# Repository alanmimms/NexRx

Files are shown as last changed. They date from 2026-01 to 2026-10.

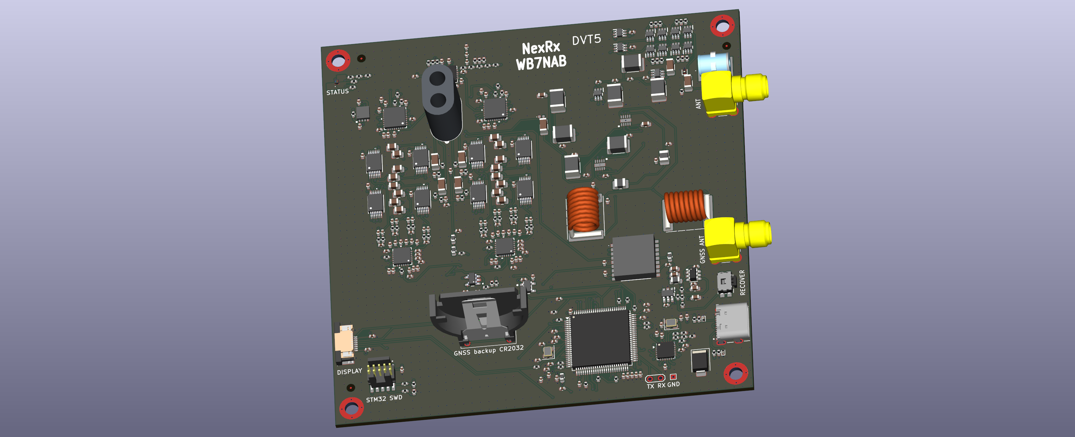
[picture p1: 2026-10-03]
doc/NexRxDVT5.png

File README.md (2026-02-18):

# NexRx: Open-Source Ham Radio SDR Receiver System
## Overview & Core Concepts

### What is NexRx?

NexRx is an ambitious open-source project that reimagines how we
interact with ham radio receivers. Instead of the knobs, buttons,
and menu diving that have defined radio interfaces for decades, NexRx
presents a browser-based interface built around a revolutionary
concept called "setboxes."

Think of it as bringing ham radio into the modern computing age -
where your radio's interface is as flexible and powerful as the
software on your computer, but still maintains the real-time
performance demands of RF communication.

This is an overview of the project. There is much more in the `./doc`
directory.

The entire project uses the MIT License, covering everything from
hardware designs and PCB layouts to software source code. This isn't
just another commercial radio with a fancy display - it's a
community-driven platform designed to push ham radio technology
forward for everyone.

### The Big Idea: Setboxes

Here's where NexRx gets interesting. Traditional radios force you to
think in terms of physical controls - turn this knob for frequency,
press that button for mode, flip this switch for antenna selection.
But why should software-defined radio be limited by the metaphors of
analog hardware?

NexRx introduces "setboxes" - think of them as smart presets that can
inherit settings from each other, just like object-oriented
programming. Instead of having separate "band" and "mode" controls,
you might have a setbox called "40m-CW-Contest" that inherits basic
40-meter settings from a parent "40m" setbox, adds CW-specific
parameters from a "CW" setbox, and then layers on contest-specific
configurations.

```mermaid
graph TD
    A[Global Settings] --> B[40m Band]
    A --> C[CW Mode]
    A --> D[Contest Setup]
    B --> E[40m-CW-Contest]
    C --> E
    D --> E
    
    style A fill:#e1f5fe
    style E fill:#c8e6c9
```

This hierarchy means you can set your antenna preferences once in
"Global Settings," define band-specific power levels in "40m Band,"
configure CW tone preferences in "CW Mode," and create
contest-specific memory channels in "Contest Setup." When you activate
"40m-CW-Contest," it automatically combines all these inherited
settings with any overrides you've defined specifically for that
configuration.

### Why This Matters

Traditional radio interfaces suffer from what we might call "control
soup" - every setting lives at the same level, making it hard to
organize your preferences logically. Want to use different antennas
for 160m versus other bands? You'll be manually switching antennas
every time you change bands. Prefer different power levels for CW
versus SSB? Hope you remember to adjust that knob every time you
change modes.

Setboxes solve this by letting you organize your radio's behavior
hierarchically. Set up your preferences once, then let the inheritance
system handle the details. The result is a radio that adapts to your
operating style instead of forcing you to adapt to its limitations.

### System Overview

NexRx consists of three main components that work together
seamlessly:

**Hardware Platform**: Built around an STM32H753 microcontroller
running at 480MHz with a full megabyte each of flash and RAM. This
isn't your typical Arduino project - we're talking serious
computational power running Zephyr RTOS. The RF hardware handles general
HF coverage from 1MHz to 30MHz.

**Embedded Software**: Written in modern C++20, this handles the
real-time RF control, basic DSP processing, and serves as a web
server. It presents itself to your computer as USB, so there's no
driver installation or network configuration hassles.

**Native Application**: This is where the magic happens. Using a
modern framework (TBD) this app runs on Linux, MacOS, and even Windows
on 64-bit PC or ARM. It handles advanced DSP, the setbox management
system, and provides rich visualizations like waterfall displays and
spectrum analysis. The interface runs entirely on the PC. The NexRx
hardware is essentially "headless".

The beauty of this architecture is its simplicity from the user's
perspective. Plug in the USB cable, install the app, and you're ready
to operate. But under the hood, you have access to computational power
and interface flexibility that would be impossible with traditional
radio architectures.

### Key Design Principles

**Inheritance Over Configuration**: Rather than configuring every
parameter for every situation, set up logical hierarchies and let
inheritance handle the complexity. Your "DX" setbox can inherit from
your "20m" setbox, which inherits from your "HF" setbox, which
inherits from your global preferences.

**Native Interface**: No drivers to manage, no compatibility worries
across different operating systems.

**Community-Driven Development**: The entire project is open source
with permissive licensing specifically to encourage community
contributions, modifications, and improvements. This is ham radio,
after all - we're supposed to be experimenting and learning.

**Real-Time Performance**: Despite the web-based interface, NexRx
maintains the real-time performance requirements of RF operation
through careful architecture and efficient protocols.

### The Vision

NexRx isn't just another SDR project - it's an attempt to demonstrate
what ham radio interfaces could become if we stopped thinking in terms
of analog radio metaphors and started thinking in terms of modern
software design patterns.

Imagine having complete recordings of every QSO with automatic digital
mode decoding, multiple simultaneous receive frequencies with
independent waterfalls, or antenna switching that automatically adapts
to your operating patterns. These capabilities become natural
extensions of the setbox paradigm rather than complex features bolted
onto traditional radio designs.

The goal is to create a platform that grows with you as an operator,
adapts to your preferences, and provides the kind of deep
configurability that makes ham radio uniquely satisfying - but without
the traditional complexity that makes advanced features intimidating
to explore.

# MCP Server

To create the Gemini MCP server I use for Kicad collaboration, you
have to add something like the following to your
`~/.gemini/settings.json` file:

	{

	...

	  "mcpServers": {
		"NexRxMCP": {
		  "command": "/home/yourusername/NexRx/.venv/bin/python3",
		  "args": ["/home/yourusername/NexRx/tools/mcp-server.py"],
		  "trust": true
		}
	  }
	}

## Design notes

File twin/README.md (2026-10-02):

# NexRx Digital Twin

Software-in-the-Loop simulation environment for the NexRx Dual-OSD SDR receiver.

## Building

```bash
mkdir build && cd build
cmake ..
make -j$(nproc)
```

For Zephyr firmware (requires Zephyr SDK):
```bash
cd zephyr
source ~/zephyr-projects/zephyr/zephyr-env.sh
west build -b native_sim
```

## Test Executables

### 1. stimulus_test

**Purpose:** Validates the antenna stimulus generators used to inject test signals into the simulation.

**Run:**
```bash
./build/stimulus_test
```

**What it tests:**
- `ToneGenerator` - Single/multi-tone CW signals
- `NoiseGenerator` - Thermal noise generation
- `CompositeStimulus` - Signal + noise combinations
- `RfCapturePlayer` - I/Q file playback with upconversion

**Expected output:**
```
=== ToneGenerator Tests ===
1. CW 14.010 MHz, 100.0 mV peak
   Peak: 100.0 mV (expected 100 mV)
   RMS:  70.7 mV (expected 70.7 mV)
   Freq: 14.01 MHz (expected 14.01 MHz)

2. Two-tone 14.000 MHz +/- 500 Hz
   Peak: ~100 mV when in phase
   ...

=== NoiseGenerator Tests ===
1. White noise 1.0 uV RMS
   Measured RMS: 1.0 uV (expected 1.0 uV)

2. Thermal noise (290K, 3kHz BW, 50 ohm)
   Measured RMS: ~155 nV (expected ~155 nV)
   ...

=== All Tests Complete ===
```

**Pass/Fail criteria:**
- **PASS:** All measured values within 10% of expected values
- **FAIL:** Large deviations indicate bugs in signal generation math
- Key checks:
  - CW tone peak should be exactly as specified
  - RMS should be peak/sqrt(2) for sinusoids
  - Thermal noise should match Johnson-Nyquist formula
  - S-meter levels: S9 = 50uV, each S-unit = 6dB

### 2. host_test

**Purpose:** Tests the host-side DSP pipeline and visualization without requiring Xyce simulation.

**Run:**
```bash
./build/host_test              # Synthetic test signal
./build/host_test --shm NAME   # Connect to running twin
```

**What it tests:**
- Synthetic OSD mixing model (RF x LO quadrature)
- `DspPipeline` signal processing
- `Visualizer` S-meter and level display
- Baseband frequency estimation

**Expected output (synthetic mode):**
```
=== NexRx Host Test - Synthetic Signal ===
RF: 14.010 MHz, 1mV peak
LO: 14.000 MHz
Expected baseband: 10 kHz

Processing 38400 samples...

S-Meter: [####      ] S5
Level: -73.2 dBm

=== Signal Analysis ===
Estimated baseband freq: 10.0 kHz
RMS level: 0.25 mV
Level: -73 dBm
S-meter: S5
```

**Pass/Fail criteria:**
- **PASS:**
  - Estimated baseband frequency within 5% of expected (10 kHz)
  - S-meter reading reasonable for 1mV input (S4-S6 range)
  - No NaN or infinite values
- **FAIL:**
  - Baseband frequency wildly wrong (indicates mixing bug)
  - Zero output (indicates signal path broken)
  - S-meter shows S0 or S9+60 (indicates scaling bug)

### 3. twin

**Purpose:** Digital twin signal generator and end-to-end test of the RF simulation pipeline. Two modes:
- `--functional`: Fast C++ model, runs real-time, streams I/Q to app
- Default: Full Xyce SPICE simulation (accurate but slow)

**Run:**
```bash
# Fast functional mode with streaming (for app integration)
./build/twin --functional --stream

# Full Xyce physics simulation
./build/twin --duration 1 --netlist netlists/pipeline_test.cir
```

**What it tests:**
- Xyce initialization and simulation stepping
- ADC sampling callback at 384 kHz
- Node voltage extraction from SPICE
- I/Q frame generation and storage

**Expected output:**
```
=== NexRx Digital Twin Pipeline Test ===
Netlist: netlists/pipeline_test.cir
Duration: 1.0 ms

--- Initializing Xyce ---
[Xyce initialization messages]

--- Running Simulation ---

--- Results ---
Success: yes
Samples collected: 384
Wall time: 2.5 s
Speed: 0.0004x realtime

--- First 10 samples ---
t=     2.604us O0:   0.123/  -0.456mV O1:   0.123/  -0.456mV
...

--- Signal Analysis (OSD0) ---
RMS magnitude: 0.5 mV
Expected baseband: 10 kHz
```

**Pass/Fail criteria:**
- **PASS:**
  - "Success: yes"
  - Sample count matches expected (duration * 384000)
  - No samples with error flag (flags != 0)
  - RMS magnitude > 0 (signal present)
- **FAIL:**
  - "Success: no" (Xyce error)
  - Zero samples collected
  - All samples show 0/0 values (node names wrong)
  - Error flags set on frames

**Note:** Requires a valid netlist with nodes named Q0_I, Q0_Q, Q1_I, Q1_Q, Q2_I, Q2_Q.

### 4. Zephyr Firmware (zephyr.exe)

**Purpose:** Tests the Zephyr RTOS firmware running on native_sim (Linux x86_64).

**Run:**
```bash
./zephyr/build/zephyr/zephyr.exe
```

**What it tests:**
- Zephyr RTOS boot and initialization
- Virtual NCO peripheral (frequency setting)
- Virtual ADC peripheral (I/Q frame reading)
- POSIX shared memory connection
- Shell command interface

**Expected output:**
```
uart connected to pseudotty: /dev/pts/X
*** Booting Zephyr OS build v4.3.0 ***
[00:00:00.000,000] <inf> nexrx_main: NexRx Digital Twin Firmware starting...
[00:00:00.000,000] <inf> nexrx_main: Build: Jan  5 2026 15:54:37
[00:00:00.000,000] <inf> twin_transport: Initializing twin transport
[00:00:00.000,000] <inf> twin_transport:   SHM: /nexrx_iq
[00:00:00.000,000] <wrn> twin_transport: Failed to open shared memory: /nexrx_iq (errno=22)
[00:00:00.000,000] <err> nexrx_main: Failed to initialize transport
[00:00:00.000,000] <inf> virtual_nco: Virtual NCO initialized with 2 channels
[00:00:00.000,000] <inf> virtual_adc: Virtual ADC initialized
[00:00:00.000,000] <inf> virtual_adc:   Channels: 4
[00:00:00.000,000] <inf> virtual_adc:   Sample rate: 384000 Hz
[00:00:00.000,000] <inf> virtual_adc:   Resolution: 24 bits
[00:00:00.000,000] <inf> virtual_nco: NCO0 frequency set to 14000000 Hz
[00:00:00.000,000] <inf> virtual_nco: NCO1 frequency set to 14000000 Hz
[00:00:00.000,000] <inf> nexrx_main: I/Q processing thread started
[00:00:00.000,000] <inf> nexrx_main: Firmware initialized, entering shell
```

**Pass/Fail criteria:**
- **PASS:**
  - "Booting Zephyr OS" message appears
  - Both NCOs initialized to 14 MHz
  - Virtual ADC shows 4 channels, 384kHz, 24-bit
  - "Firmware initialized, entering shell"
  - Shared memory warning is OK when orchestrator not running
- **FAIL:**
  - Crash or segfault
  - Missing NCO or ADC initialization messages
  - Boot loop or hang before "Firmware initialized"

**Shell commands (interactive):**
```
uart:~$ nexrx status     # Show VFO frequencies and frame count
uart:~$ nexrx freq 0 7000000   # Set VFO0 to 7 MHz
```

## Architecture Overview

```
                    ┌─────────────────┐
                    │  AntennaStimulus │ ◄── stimulus_test
                    │  (ToneGenerator) │
                    └────────┬────────┘
                             │ RF signal
                             ▼
┌────────────────────────────────────────────────────────────┐
│                     Xyce SPICE Simulation                   │ ◄── twin
│  (Preselector → Transformer → Dual-OSD → TIA)              │
└────────────────────────────┬───────────────────────────────┘
                             │ Node voltages
                             ▼
                    ┌─────────────────┐
                    │   AdcSampler    │ @ 384 kHz
                    └────────┬────────┘
                             │ IQFrame
                             ▼
                    ┌─────────────────┐
                    │ SharedMemTransport│
                    └────────┬────────┘
                             │
              ┌──────────────┴──────────────┐
              │                             │
              ▼                             ▼
     ┌─────────────────┐           ┌─────────────────┐
     │  Zephyr Firmware │           │    Host App     │ ◄── host_test
     │  (native_sim)   │           │  (DspPipeline)  │
     └─────────────────┘           └─────────────────┘
              ▲
              │
      zephyr.exe test
```

## Quick Validation

Run all tests in sequence:
```bash
cd build

# 1. Stimulus generators (no external deps)
./stimulus_test

# 2. Host DSP pipeline (no external deps)
./host_test

# 3. Digital twin - functional mode (fast)
./twin --functional --duration 100

# 3b. Or full Xyce simulation (slow, requires Xyce)
./twin --duration 0.1 --netlist netlists/pipeline_test.cir

# 4. Zephyr firmware
../zephyr/build/zephyr/zephyr.exe &
sleep 2
kill %1
```

All tests should complete without crashes. Check output against criteria above.

## Dependencies

- CMake 3.20+
- C++20 compiler (GCC 11+ or Clang 14+)
- Xyce 7.10 (for twin physics mode)
- Trilinos libraries (for Xyce)
- Zephyr SDK 4.3+ (for firmware)
- FFTW3, LAPACK, BLAS

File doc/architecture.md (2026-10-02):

# NexRx: Technical Architecture
## Hardware, Software, and RF Design

### Hardware Architecture

The NexRx hardware platform centers around an STM32H743
microcontroller - a 480MHz Cortex-M7 processor with 1MB of both flash
memory and RAM. This isn't overkill; real-time RF control, web
serving, and DSP processing demand serious computational resources.

```mermaid
graph TB
    A(Antenna) --> D(Digital attenuators)
    D --> E(broadcast HPF)
	E --> F(four octave BPF array)
    F --> G(OSD0 f-k)
    F --> H(OSD1 f+k)
    
    G --> I(4-channel audio codec with integrated PGA)
    H --> J(4-channel audio codec with integrated PGA)
    I --> |ADC data|K(STM32H743)
    J --> |ADC data|K
    K --> |I/Q data|L(host app via USB)
```

### USB to Host Communication Architecture

To achieve bit-perfect data integrity and cross-platform plug-and-play
capability without requiring custom kernel drivers, the architecture
uses a **Vendor-Specific Bulk USB Class utilizing Microsoft OS 2.0
Descriptors**.

By moving away from USB Audio Class 2.0 (UAC2) and embracing Bulk
transfers, the system benefits from hardware-level CRC error-checking
and automatic retransmissions. This guarantees delivery and entirely
eliminates the dropped packets associated with isochronous streams,
keeping the phase determinism perfectly stable for your DSP pipeline.

### Data Stream and Payload

Because the STM32 handles polyphase recombination, dual-OSD frequency
shifting, and cross-correlation internally, the USB payload is
significantly reduced.

* **Channel Count**: The STM32 sends a single, normalized,
  pre-stitched I/Q baseband stream (2 channels) to the host PC.

* **Framing**: The stream consists of 24-bit samples packed into
  32-bit words to ensure optimal DMA alignment.

* **Sample Rate & Bandwidth**: Streaming at 384ksps, this 2-channel,
  32-bit payload consumes a highly stable 24.576 Mbps of Bulk USB
  bandwidth.

### Command and Status Data Path

Control and telemetry data are completely decoupled from the I/Q data
stream, utilizing dedicated endpoints.

* **Command Channel (Endpoint 0x02 OUT)**: The host PC uses this bulk
  endpoint to issue high-level commands, such as target VFO
  frequencies and PGA analog gains, entirely abstracting the hardware
  state from the PC.

* **Telemetry Channel (Endpoint 0x83 IN)**: This bulk/interrupt
  endpoint delivers state feedback, telemetry, and autonomous SNA
  sweep responses back to the host.

* **Command Protection**: Command packets are protected by a purely
  software-based Fletcher-16 checksum loop on the host and STM32 to
  ensure commands are not corrupted.

### Operating System Deployment Matrix

This Vendor-Specific Bulk architecture cleanly satisfies your security
and privilege constraints across all target platforms:

* **Windows (10 / 11)**: 100% Zero-Admin. Windows Plug-and-Play
  manager reads the MS OS 2.0 descriptors and silently binds the
  native `WinUSB.sys` driver in the background with zero UAC or
  installer prompts.

* **macOS**: 100% Zero-Admin. The host application uses native
  user-space APIs (via `libusb` and `IOUSBHost`) to connect directly
  without requiring any kernel extensions.

* **Linux**: Standard Non-Root User Execution. Users will run a
  standard, one-time `sudo` command to copy a udev rule (e.g.,
  `99-nexrx.rules`) into `/etc/udev/rules.d/` to grant read/write
  access to the raw USB nodes.

* **Android**: Zero-Root / User-Space. The mobile app utilizes the
  standard Android USB Host API (`android.hardware.usb`). The OS
  simply displays a one-time permission pop-up asking the user to
  allow the app to access the NexRx SDR.

### Software Architecture

The software stack divides responsibilities between the embedded
system and the native host application, with each handling what it
does best.

```mermaid
graph TB
    subgraph Embedded ["STM32 Embedded (C++20/Zephyr)"]
        J[Control Plane Server]
		LCD[Tiny LCD Status]
		CAL[GNSS calibration discipline]
        H[RF Controls: AGC, attenuation, filter enables]
        I[Basic DSP / Channel Reduction]
		F[Reduced I/Q Data]
		G[CBOR/JSON Control/Status]
        K[USB]
    end
    
    subgraph App ["Native App (Lua + Raylib + C++)"]
        A[Advanced DSP - C++]
        B[Config Management - Lua]
        C[Unified Widget UI - Lua]
        D[Visualizations - C++/Raylib]
        E[Digital Mode Decoding - C++]
    end
    
    Embedded --> |Control, Status, I/Q Data| App
```

### Receiver Architecture

The receive path implements a sophisticated dual-receiver architecture
using independent octature sampling detectors (OSDs). Each OSD
operates as a direct-conversion mixer, producing I and Q baseband
signals that capture both amplitude and phase information of the RF
signal. The two receivers operate simultaneously, each with
independent frequency tuning controlled by separate CPLD-generated
local oscillator signals.

**Signal Path Components:**

**Signal Path Components & Front-End Protection:**

1. **Input Protection & DC Blocking**:
   - A series 1μF/100V C0G capacitor blocks external DC bias from damaging downstream components.
   - Fast primary TVS protection diodes clip RF surges to 25V pk-pk (surviving up to +40 dBm inputs) to protect attenuator switches.
   - Secondary TVS protection diodes clip signals to 13V pk-pk following the attenuators to protect BPF switches and OSD direct-conversion mixers.

2. **Digital Attenuator Array**:
   - Cascaded T-pad network (24 dB, 12 dB, 6 dB, 3 dB) providing 0 to 45 dB attenuation in 3 dB steps.
   - Each stage utilizes an **AS183-92LF pHEMT SPDT switch chip** wired for true bypass when deactivated.

3. **Bandpass Filter (BPF) Selection**:
   - A bank of 4 octave bandpass filters (1.8-3.4 MHz, 3.2-7.5 MHz, 7.3-14.5 MHz, 21.8-30.0 MHz) paired with a broadcast AM high-pass filter (HPF).
   - BPF selection is routed using **SP4T SKY13322-375LF switches** to select among the four BPF branches. This simplifies component count, eliminates an external inverter package, and reduces the STM32 GPIO control pin count by one.

4. **TLV320ADC5140 Integrated PGAs & Anti-Aliasing Filters**:
   - Each TLV320ADC5140 quad-channel audio ADC incorporates programmable gain amplifiers (PGA) providing 0 dB to 42 dB of analog gain control per channel, configured directly via SPI (SPI4).
   - Differential input low-pass anti-aliasing filtering prior to ADC conversion protects baseband Nyquist boundaries.

5. **Waterfall Viewport Mode Hysteresis**:
   - Below 15 MHz, the dual iCE40 CPLDs run in 8-phase Octature mode (OSD). Above 15 MHz, they run in 4-phase Quadrature mode (QSD).
   - To prevent visual display discontinuities when tuning across 15 MHz, mode switching is tied strictly to the active waterfall viewport bounds: switching to 4-phase occurs only when the active display viewport is *strictly above* 15 MHz, and switching to 8-phase occurs only when the active viewport is *strictly below* 15 MHz. When the viewport straddles 15 MHz, the active mode is retained.
   - In 4-phase QSD mode, a +3 dB digital gain scaling is automatically applied in STM32 DSP to normalize the baseline noise floor level with 8-phase mode.

**System Performance & Dynamic Range:**
- **Sensitivity / MDS**: Thermal noise floor at 50Ω, 500 Hz bandwidth is $-141\text{ dBm}$. With a estimated system noise figure of $6\text{ dB}$, Minimum Detectable Signal (MDS) for 10 dB SNR is $\text{MDS} = -125\text{ dBm}$.
- **Instantaneous Dynamic Range**: $\sim 100\text{ dB}$ (ADC limited).
- **Blocking Dynamic Range (BDR)**: $142\text{ dB}$ (+17 dBm max input to -125 dBm MDS).
- **Two-Tone IMD Dynamic Range**: $97\text{ dB}$ (OSD IP3 $+20\text{ dBm}$).

**AGC Implementation:**

AGC operates as a hybrid hardware/software system optimized for both fast protection and smooth user experience:

1. **STM32 Fast Loop**: Measures I/Q signal strength every sample period, switches attenuator pads within microseconds to prevent overload.
2. **Host PC Smoothing**: Applies gain compensation in DSP so the operator perceives smooth signal level changes rather than abrupt attenuator switching.
3. **Attack/Decay**: Fast attack on strong signals (prevent overload), slow decay to avoid pumping on fading signals.
4. **Setbox Control**: AGC characteristics (attack time, decay time, hang time, target level) configurable via setbox inheritance.

Each OSD output feeds into a four-channel audio codec that digitizes the audio-rate signals at 96 kS/s with 24-bit resolution. This baseband data flows to the STM32 for basic conditioning before transmission to the host PC as a single pre-stitched 384 ksps I/Q pair for host PC DSP processing.

### OSD Mapping and QSD Mapping
There are two instances of the "OSD" schematic page, each of which has
its own audio codec, set of eight accumulator capacitors, set of four
four-way switch chips, and cross-wiring to map the differential
RF+/RF- signals to their switch chips as shown below. Each audio codec
has its own TDM output serial line attached to the STM32, where these
audio samples are reduced via DSP.

| Input Signal | Switch Instance | Clock Phase | Accumulator Capacitor | Codec Channel |
| --- | --- | --- | --- | --- |
| RF+ | 0 | 0 | 0 | IN1+ |
| RF+ | 0 | 1 | 1 | IN3+ |
| RF+ | 0 | 2 | 2 | IN2+ |
| RF+ | 0 | 3 | 3 | IN4+ |
| RF+ | 1 | 4 | 4 | IN1- |
| RF+ | 1 | 5 | 5 | IN3- |
| RF+ | 1 | 6 | 6 | IN2- |
| RF+ | 1 | 7 | 7 | IN4- |
| RF- | 2 | 0 | 4 | IN1- |
| RF- | 2 | 1 | 5 | IN3- |
| RF- | 2 | 2 | 6 | IN2- |
| RF- | 2 | 3 | 7 | IN4- |
| RF- | 3 | 4 | 0 | IN1+ |
| RF- | 3 | 5 | 1 | IN3+ |
| RF- | 3 | 6 | 2 | IN2+ |
| RF- | 3 | 7 | 3 | IN4+ |

### Two CPLD Subsystem

The two CPLDs are identical. There is one for each of the two OSD
pipelines. Each CPLD serves as the high-speed clock generation hub,
and houses a frequency counter for the TCXO clock it receives gated by
the 1pps signal from the GNSS receiver.

**Master Clocking:**

A 40 MHz temperature-compensated crystal oscillator (TCXO) provides
the master timebase.

From this 40 MHz reference, the CPLD synthesizes all system clocks.
This is done in one of two modes, settable by software:

* For VFO frequencies below 15MHz, we generate 8 phase octature clocks
  running at VFO * 8 (up to 120MHz).

* For higher VFO frequencies, we generate 8 outputs but these are set
  up as 4 phase quadrature clocking running at VFO * 4 (up to 120MHz).

### STM32 Subsystem

The STM32H743 microcontroller orchestrates all real-time control and
serves as the bridge between RF hardware and host PC.

**Peripheral Usage:**

**I2C Buses:**
- **Audio Codec Configuration**: Sets up the audio codecs (eight baseband channels across dual OSDs)

**SPI Interfaces:**

- **CPLD Configuration**: Bitstream loading and reconfiguration,
  read/write of control and status registers.

- **High-speed peripherals**: Future expansion

**USB/Ethernet:**
- **Primary Interface**: USB 2.0 High-Speed Ethernet gadget (480 Mbps)
  and/or 100Mb CAT5 Ethernet.

**Real-time Control Tasks:**

The STM32 runs Zephyr RTOS managing multiple concurrent tasks:
- RF switching coordination (low pass filter gating, attenuators)
- AGC fast loop (signal strength → attenuator control)
- OSD channel combining into I/Q data
- Command processing from host PC

### Power Sequencing

The NexRx receiver is powered from the USB VBUS supply (5V at 3A
expected). This provides up to 15W of power, which is significantly
more than required for the dual-OSD architecture, dual iCE40 CPLDs,
and supporting digital logic.

## Power Rail Summary

| Rail | Voltage | Capacity | Control | Purpose |
| :--- | :--- | :--- | :--- | :--- |
| **VBUS** | 5.0V | 3.0A | Always On | Primary input power from USB-C. |
| **+3.3V** | 3.3V | 3.0A | Automatic | Main digital logic supply (MCU, CPLDs, Si5351). |
| **+5VA** | 5.0V | 300mA | Automatic | Analog supply for audio ADCs / Codecs. |
| **+3.3VA** | 3.3V | 300mA | Automatic | Clean analog supply for RF front-end, PGAs, and buffers. |

## Design Verification & Power Sequencing Notes

1.  **Automatic Power Sequencing:** Subsystem power rails feature
    hardware RC delay networks and automatic LDO/regulator sequencing.
    MCU software control is not required to sequence power rails
    during startup or shutdown.
2.  **Input Protection:** The VBUS input includes ESD protection and a
    TVS diode to clamp input surges.
3.  **Conversion Efficiency:** The main 3.3V digital rail uses a
    high-efficiency synchronous buck converter to minimize thermal
    dissipation inside the enclosure.
4.  **Analog Integrity:** Sensitive analog rails (+5VA, +3.3VA)
    utilize ultra-high PSRR LDO regulators to preserve low noise floor
    and high dynamic range.

The STM32 manages power-up and power-down sequencing for all
subsystems. Proper sequencing prevents damage and ensures reliable
startup.

**Note**: Detailed power sequencing design is still in development.
The following outlines requirements and approach:

**STM32 Power:**
- Single 3.3V rail, no sequencing required for STM32 itself
- VBAT pin connects to 3.3V (no battery backup planned)
- STM32 boots on internal 64 MHz HSI clock

**Startup Sequence:**
1. STM32 3.3V powers on using the "3.3V ON" power rail, which is
   enabled immediately upon availability of VBUS power from USB.
1. STM32 boots on internal clock.
1. STM32 switches to external crystal clock.
1. STM32 configures the two CPLDs (simultaneously by selecting them
   both on its SPI bus) with an image from its flash file system.
1. STM32 configures the receiver for the current VFO frequency F,
   setting the OSDs' clock generators to F +/- 12kHz.
1. STM32 configures the audio codec to set up the I/Q channel I/O.
1. STM32 connects with the host PC application (if present) over USB.
1. Ready to receive.

### Development Standards and Practices

The project maintains consistent coding standards across both embedded
and host application components. All code uses CamelCase naming
conventions for variables, functions, and methods, with SNAKE_CASE
reserved only for constants and preprocessor macros.

The embedded system targets C++20 running on Zephyr RTOS, taking
advantage of modern language features for safer and more expressive
code. The host application leverages a high-performance C++ DSP core
integrated with a Lua 5.4 scripting environment for UI and high-level
logic, utilizing Raylib for hardware-accelerated rendering.

**Performance Requirements**: The system maintains sub-100ms response
times for critical RF parameter changes, continuous I/Q streaming at
384ksps, and smooth real-time waterfall displays via the host PC app.
These requirements drive many of the architectural decisions,
particularly the division of responsibilities between embedded and
native host components.

**Communication Protocol**: The system uses binary frames for
high-throughput I/Q data and structured messages (CBOR or JSON) for
control and status updates. This hybrid approach optimizes for both
efficiency and developer productivity.

### Hardware Interface Abstractions

The embedded software provides clean C++20 abstractions for all
hardware interfaces. pHEMT FET switching, Si5351 synthesizer
configuration, and other RF parameter adjustment all use
object-oriented interfaces that hide hardware complexity from
higher-level code.

These abstractions enable rapid development and testing while
maintaining the real-time performance requirements of RF operation.
The modular design also simplifies hardware variations and upgrades
without requiring extensive software changes.

### Testing and Validation Strategy

Real-time RF systems present unique testing challenges that require
both automated testing and careful measurement validation. The project
includes provisions for automated testing of DSP algorithms,
communication protocols, and user interface components.

Hardware validation requires RF test equipment for measuring receive
sensitivity and various distortion and harmonic responses.

The open-source nature of the project enables distributed testing
across different operating environments and use cases, helping
identify issues that might not appear in controlled laboratory
conditions.

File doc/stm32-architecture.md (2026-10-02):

# STM32H743VIT6 Architecture & Peripheral Allocation

This document details the hardware allocation for the
**STM32H743VIT6** MCU in the NexRx project.

## Peripheral Allocation Summary

### SPI Controllers
* **SPI2**: ST7789V Display Interface (`dispNSS` PA11, `dispSCK` PA9, `dispMOSI` PC1, `dispDC` PE13, `dispRESET` PE12)
* **SPI3**: Dual CPLD Interface (`cpld0NCS` PA4, `cpld1NCS` PA15, `cpldSCK` PC10, `cpldMISO` PC11, `cpldMOSI` PB2, `cpldDONE` PE0, `cpldCRESET` PE1)
* **SPI4**: Dual TLV320ADC5140 ADC Control Bus (`osd0NSS` PE3, `osd1NSS` PE4, `osdSCK` PE2, `osdMOSI` PE14, `osdMISO` PE5, `adcReset` PA6)

### I2C Controllers
* **I2C1**: Si5351 Synthesizer Configuration & Status (`si5351SCL` PB6, `si5351SDA` PB7, `si5351OE` PB4)

### USART / UART Mapping
* **UART7**: GNSS Receiver Interface (`gnssRX` PE8, `gnssTX` PE9, `gnssNRESET` PB3)

### SAI (Serial Audio Interface) Mapping
* **SAI2a (Master)**: OSD0 audio serial link (`osd0` PA0 data, `osdMCLK` PA1, `osdBCLK` PA2, `osdWCLK` PA12)
* **SAI2b (Slave)**: OSD1 audio serial link (`osd1` PD11 data; synchronous to SAI2a clocks)

Each TLV320ADC5140 ADC provides four 24-bit samples at 384ksps per OSD over its serial audio link to the STM32. The STM32 performs on-chip DSP to combine and correlate these into two 384ksps streams (I and Q) sent over USB Bulk (`iq_data_pump`) to the host application.

### ADC Channels
* **ADC1**: USB Type-C CC pin monitoring (`cc1ADC` PC5, `cc2ADC` PA7) for power source validation.

### USB Interface
* **USB_OTG_HS**: High-Speed ULPI interface (480 Mbps) to external USB3343 transceiver.

---

## Hardware Pin Allocation Table

| Symbol | Peripheral | Pin | Type | Notes |
| :--- | :--- | :--- | :--- | :--- |
| `osd0` | SAI2a | PA0 | input | Master audio data (OSD0) |
| `osdMCLK` | SAI2a | PA1 | output | Master clock |
| `osdBCLK` | SAI2a | PA2 | output | Bit clock |
| `osdWCLK` | SAI2a | PA12 | output | Word clock (Frame Sync) |
| `osd1` | SAI2b | PD11 | input | Slave audio data (OSD1) |
| `dispNSS` | SPI2 | PA11 | output | Display chip select |
| `dispSCK` | SPI2 | PA9 | output | Display SPI clock |
| `dispMOSI` | SPI2 | PC1 | output | Display SPI MOSI |
| `dispDC` | GPIO | PE13 | output | Display data/command select |
| `dispRESET` | GPIO | PE12 | output | Display reset |
| `cpld0NCS` | SPI3 | PA4 | output | CPLD0 SPI chip select |
| `cpld1NCS` | SPI3 | PA15 | output | CPLD1 SPI chip select |
| `cpldSCK` | SPI3 | PC10 | output | CPLD SPI clock |
| `cpldMISO` | SPI3 | PC11 | input | CPLD SPI MISO |
| `cpldMOSI` | SPI3 | PB2 | output | CPLD SPI MOSI |
| `cpldDONE` | GPIO | PE0 | input | CPLD configuration done |
| `cpldCRESET` | GPIO | PE1 | output | CPLD configuration reset |
| `osd0NSS` | SPI4 | PE3 | output | OSD0 ADC (TLV320ADC5140) SPI select |
| `osd1NSS` | SPI4 | PE4 | output | OSD1 ADC (TLV320ADC5140) SPI select |
| `osdSCK` | SPI4 | PE2 | output | OSD ADC SPI clock |
| `osdMOSI` | SPI4 | PE14 | output | OSD ADC SPI MOSI |
| `osdMISO` | SPI4 | PE5 | input | OSD ADC SPI MISO |
| `adcReset` | GPIO | PA6 | output | Reset line for ADCs |
| `bpf2` | GPIO | PD0 | output | Filter selection (BPF branch 2) |
| `bpf1` | GPIO | PD1 | output | Filter selection (BPF branch 1) |
| `hpf` | GPIO | PD2 | output | Filter selection (HPF enable) |
| `nHPF` | GPIO | PD3 | output | Inverted HPF selection |
| `bpf4` | GPIO | PD4 | output | Filter selection (BPF branch 4) |
| `bpf3` | GPIO | PD5 | output | Filter selection (BPF branch 3) |
| `enable3V3` | GPIO | PD6 | output | 3.3V power rail enable |
| `atten6dB` | GPIO | PD7 | output | 6 dB attenuator stage |
| `atten12dB` | GPIO | PD8 | output | 12 dB attenuator stage |
| `atten24dB` | GPIO | PD9 | output | 24 dB attenuator stage |
| `atten3dB` | GPIO | PD10 | output | 3 dB attenuator stage |
| `cc1ADC` | ADC1 | PC5 | input | USB CC1 voltage |
| `cc2ADC` | ADC1 | PA7 | input | USB CC2 voltage |
| `statusRed` | GPIO | PB9 | output | RGB Status LED - Red (active low) |
| `statusGreen` | GPIO | PB8 | output | RGB Status LED - Green (active low) |
| `statusBlue` | GPIO | PE6 | output | RGB Status LED - Blue (active low) |
| `gnssNRESET` | GPIO | PB3 | output | GNSS reset (active low) |
| `gnssRX` | UART7 | PE8 | input | GNSS serial receive |
| `gnssTX` | UART7 | PE9 | output | GNSS serial transmit |
| `si5351OE` | GPIO | PB4 | output | Si5351 output enable |
| `si5351SCL` | I2C1 | PB6 | bidir | Si5351 I2C clock |
| `si5351SDA` | I2C1 | PB7 | bidir | Si5351 I2C data |
| `swdSWDIO` | SWD | PA13 | bidir | SWD debug data |
| `swdSWDCLK` | SWD | PA14 | input | SWD debug clock |
| `usbDATA0` | USB_HS | PA3 | bidir | USB ULPI Data 0 |
| `usbCLKOUT` | USB_HS | PA5 | input | USB ULPI Clock |
| `usbDATA1` | USB_HS | PB0 | bidir | USB ULPI Data 1 |
| `usbDATA2` | USB_HS | PB1 | bidir | USB ULPI Data 2 |
| `usbDATA7` | USB_HS | PB5 | bidir | USB ULPI Data 7 |
| `usbDATA3` | USB_HS | PB10 | bidir | USB ULPI Data 3 |
| `usbDATA4` | USB_HS | PB11 | bidir | USB ULPI Data 4 |
| `usbDATA5` | USB_HS | PB12 | bidir | USB ULPI Data 5 |
| `usbDATA6` | USB_HS | PB13 | bidir | USB ULPI Data 6 |
| `usbSTP` | USB_HS | PC0 | output | USB ULPI Stop |
| `usbDIR` | USB_HS | PC2_C | input | USB ULPI Direction |
| `usbNXT` | USB_HS | PC3_C | input | USB ULPI Next |
| `STM32Clock` | RCC | PH0 | input | 26MHz Crystal Resonator (HSE) |

---

## Firmware Integration (Zephyr RTOS)

The embedded firmware resides in the `fw/` directory.

### Subsystem Driver Allocation:
1. **SPI (`zephyr,spi-stm32`)**:
   - SPI2: ST7789V display driver.
   - SPI3: Dual CPLD register and configuration interface.
   - SPI4: Dual TLV320ADC5140 ADC SPI control driver.
2. **I2C (`zephyr,i2c-stm32`)**: Controls Si5351 synthesizer tuning (I2C1).
3. **UART (`zephyr,uart-stm32`)**: Handles GNSS NMEA/UBX telemetry parsing (UART7).
4. **SAI (`zephyr,i2s-stm32`)**: Captures four 24-bit samples at 384ksps per OSD across SAI2a (master) and SAI2b (slave) with DMA buffering.
5. **USB (`zephyr,usb-device`)**: High-speed USB 2.0 offload (480 Mbps) using the external ULPI PHY.
6. **ADC (`zephyr,adc-stm32`)**: Monitors CC1 and CC2 pin voltages to validate Type-C power negotiation before enabling 3.3V analog supplies.
7. **GPIO (`zephyr,gpio-stm32`)**:
   - BPF/HPF filter bank selection (`bpf1`..`bpf4`, `hpf`, `nHPF`).
   - Attenuator stage switching (`atten3dB`, `atten6dB`, `atten12dB`, `atten24dB`).
   - Power rail control (`enable3V3`).
   - Status RGB LEDs (`statusRed`, `statusGreen`, `statusBlue`).
   - Hardware reset control (`adcReset`, `gnssNRESET`, `cpldCRESET`).

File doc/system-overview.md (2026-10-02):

# NexRx: System Overview
## Open-Source HF SDR Receiver

**Document Version:** 1.0
**Date:** March 2026
**License:** MIT License (hardware, firmware, and software)

---

## Table of Contents

1. [Introduction](#introduction)
2. [Key Innovations](#key-innovations)
3. [System Architecture](#system-architecture)
4. [Power Architecture](#power-architecture)
5. [Connectivity Architecture](#connectivity-architecture)
6. [Host PC Application](#host-pc-application)
7. [Operating Concept: SetBoxes](#operating-concept-setboxes)
8. [Target Users](#target-users)
9. [System Specifications](#system-specifications)

---

## Introduction

NexRx is an open-source software-defined radio (SDR) receiver that is
the receiver portion of the NexRig project—a full transceiver. NexRx is a
general coverage HF receiver aimed at the ham radio HF bands but it
covers 1-30 MHz without gaps. Unlike traditional commercial receivers,
NexRx combines modern computing capabilities with sophisticated RF
engineering to create a platform that is both powerful and accessible
to the amateur radio community.

The entire project—hardware schematics, PCB designs, firmware source
code, FPGA designs, and host application software—is released under
the MIT License. This permissive license encourages experimentation,
modification, and contribution from the global amateur radio
community.

### Design Philosophy

NexRx represents a fundamental rethinking of receiver architecture:

**Digital-First Engineering**: Where traditional radios use analog
circuits, NexRx leverages digital control and processing. The Host
PC, STM32H753 microcontroller, and Lattice FPGA handle tasks
traditionally performed by analog components for flexibility and
precision.

**Software-Defined Configuration**: The SetBox paradigm replaces
traditional fixed knobs with hierarchical configuration
inheritance. Complex operating scenarios become simple profile
switches, with all parameters managed intelligently by the software.

---

## Key Innovations

### Dual-OSD Receiver Architecture

NexRx's receiver uses two independent Octature/Quadrature Synchronous Detectors
(OSDs) operating simultaneously to achieve superior image rejection and harmonic
attenuation.

**OSD0** operates at frequency offset *f-k*, providing the first
receive signal path with excellent sensitivity.

**OSD1** operates at frequency offset *f+k*, enabling image cancellation
and passband stitching through complex signal combining with OSD0. The complementary
frequency offsets allow DSP software to separate desired signals from
images and achieve high dynamic range image rejection.

The dual OSD paths feed eight ADC channels (four 24-bit channels at 384 ksps
per OSD) with integrated programmable gain amplifiers in dual TLV320ADC5140 audio converters.
The STM32 performs on-chip DSP to correlate and combine these into two 384 ksps streams
(I and Q) sent over USB to the host PC for advanced DSP processing. Below 15 MHz, the
CPLDs run the detector switches in 8-phase octature mode (OSD); above 15 MHz,
they run in 4-phase quadrature mode (QSD) with automatic +3 dB digital normalization.

### SetBox Configuration Paradigm

Traditional radios force operators to adjust many independent
parameters every time they change bands, modes, or operating
situations. A contest operator switching from 20-meter CW to 40-meter
SSB might need to change: frequency, mode, antenna selection, power
level, audio equalization, AGC settings, noise reduction, filter
bandwidth, and more.

NexRx's SetBox software configuration system uses hierarchical
inheritance. Create a "Contest-Base" SetBox defining common contest
settings—perhaps reduced power for battery operation and your contest
callsign. Create "Contest-20m" and "Contest-40m" SetBoxes inheriting
from Contest-Base but adding band-specific antenna selections and
frequency memories. Create "Contest-20m-CW" and "Contest-40m-SSB"
SetBoxes that inherit from their respective band configurations and
add mode-specific parameters.

When you switch from Contest-20m-CW to Contest-40m-SSB, the system
instantly reconfigures everything—antenna, power, frequency, mode,
audio processing, and waterfall colors. Settings common to all contest operations (inherited from
Contest-Base) remain consistent, while band and mode specifics adjust
automatically.

The SetBox hierarchy makes complex operating scenarios trivial to
manage while maintaining complete control for operators who want to
adjust individual parameters.

---

## System Architecture

## Connectivity Architecture

### Data Streams

**Receive I/Q Data** (STM32 → Host):
- Four baseband channels (I and Q for OSD0 and OSD1), pre-stitched into a 384 ksps stream
- 24-bit samples packed into 32-bit words
- Total data rate: 2 channels × 384,000 samples/sec × 4 bytes = ~3.07 MB/s (24.576 Mbps continuous payload)
- Transport must deliver minimal latency

**Control/Status Messages** (Bidirectional):
- Relay switching commands (band, attenuator, T/R)
- PGA gain adjustments
- FPGA frequency/phase settings
- Temperature/voltage telemetry
- Calibration data
- TCP transport for reliability
- Low bandwidth (~100 kB/s peak)

Total bandwidth: ~15 Mbps well within 100 Mbps Ethernet capability
(Fast Ethernet), leaving substantial headroom. The Ethernet vs USB2
(480Mb/s) decision is still pending, but it's likely both will be
supported in some fashion.

## Host PC Application

### Native Application

The NexRx user interface is a high-performance **native desktop application** built with **Lua 5.4** and **Raylib**.

**Cross-Platform**: A single codebase produces native applications for:
- Windows (10/11)
- macOS (11.0+)
- Linux (Ubuntu, Fedora, Arch, etc.)

The application is packaged as a standalone binary with embedded Lua scripts and assets, ensuring a consistent experience across platforms.

#### Application Architecture

**Main Process (C++ Engine)**
- High-throughput I/Q signal processing and DSP.
- Hardware-accelerated rendering of spectrum and waterfall.
- Low-latency socket communication with the STM32.
- Operating system integration (Audio, File I/O).

**Scripting Layer (Lua UI)**
- Unified Widget system for UI hierarchy and interaction logic.
- Reactive property graph for state synchronization.
- SetBox configuration and styling management.
- User-definable macros and operating workflows.

### DSP Responsibilities

The host application performs **computationally intensive DSP**
unsuitable for real-time embedded processing:

**Dual-OSD Combining**: The two complex baseband signals (from
OSD0 and OSD1) are combined with calibrated weights and phase alignment
to maximize desired signals and cancel images.

**Demodulation**: SSB, CW, AM, FM, and digital mode (PSK, FT8, RTTY)
demodulation algorithms.

**Filtering**: User-adjustable passband filters, notch filters, and
noise reduction filters applied in the frequency domain (FFT-based).

**AGC (Automatic Gain Control)**: Adaptive gain control with
configurable attack/release times to maintain consistent audio levels.

**Audio Processing**: High-fidelity audio output with user-adjustable equalization.

**Visualization**: Real-time FFT for waterfall and spectrum displays,
constellation diagrams for digital modes, waveform display.

### User Interface Highlights

**Waterfall Display**: Primary tuning interface. Mouse wheel scrolling
tunes frequency. Click-and-drag selects signals via SignalBoxes. Zoom controls adjust
span.

**SetBox Selector**: Dropdown or tree view showing available
configurations. One-click switching between operating scenarios.

**Control Panel**: Consolidated access to frequency, mode, power,
antenna selection, audio controls, and advanced settings.

**Status Indicators**: S-meter, VSWR, temperature, power output,
voltage rails—all updated in real-time.

**Digital Mode Integration**: Built-in decoders for popular digital
modes with automatic frequency tracking and logging.

---

## Operating Concept: SetBoxes

### The Problem with Traditional Radios

A typical contest operator switching from 20-meter CW to 40-meter SSB
must manually adjust dozens of independent parameters. Traditional radios force operators to execute complex sequences of knob turns and button presses, leading to errors and slow transitions.

### The SetBox Solution

A **SetBox** is a named configuration profile containing values for every adjustable parameter in the system. SetBoxes form **inheritance hierarchies**, where child SetBoxes inherit parameter values from parents and override only what changes. This decouples the *intent* of the operator from the *implementation* of the radio's state.

**Example Hierarchy**:

```
Global-Defaults
    ├─ Contest-Base (inherits from Global-Defaults)
    │   ├─ Contest-20m (inherits from Contest-Base)
    │   │   ├─ Contest-20m-CW (inherits from Contest-20m)
    │   │   └─ Contest-20m-SSB (inherits from Contest-20m)
    │   └─ Contest-40m (inherits from Contest-Base)
    │       ├─ Contest-40m-CW (inherits from Contest-40m)
    │       └─ Contest-40m-SSB (inherits from Contest-40m)
    └─ Ragchew-Base (inherits from Global-Defaults)
        ├─ Ragchew-20m-SSB
        └─ Ragchew-40m-SSB
```

**Global-Defaults** might define:
- Default AGC: Medium
- Default antenna: Auto-select by band

**Contest-Base** inherits everything from Global-Defaults but overrides:
- Callsign: W1ABC/M (mobile operation)

**Contest-20m** inherits from Contest-Base and overrides:
- Frequency: 14.000 MHz starting point
- Antenna: Force 20m beam selection

**Contest-20m-CW** inherits from Contest-20m and overrides:
- Mode: CW
- Filter bandwidth: 500 Hz
- AGC: Fast

When the operator switches to Contest-20m-CW, the system applies:
- Callsign: W1ABC/M (from Contest-Base)
- Frequency: 14.000 MHz (from Contest-20m)
- Antenna: 20m beam (from Contest-20m)
- Mode: CW (from Contest-20m-CW)
- Filter: 500 Hz (from Contest-20m-CW)
- AGC: Fast (from Contest-20m-CW)

Switching to Contest-40m-SSB instantly reconfigures to:
- Callsign: W1ABC/M (from Contest-Base, unchanged)
- Frequency: 7.200 MHz (from Contest-40m)
- Antenna: 40m dipole (from Contest-40m)
- Mode: SSB (from Contest-40m-SSB)
- Filter: 2.4 kHz (from Contest-40m-SSB)
- AGC: Slow (from Contest-40m-SSB)

### Benefits

**Consistency**: Settings common to all contest operations (power,
callsign) are defined once in Contest-Base and automatically apply to
all child SetBoxes.

**Flexibility**: Any parameter can be overridden at any level of the
hierarchy.

**Simplicity**: Switching between complex operating scenarios becomes
a single SetBox selection.

**Transparency**: The user interface shows exactly where each active
parameter value comes from in the inheritance chain.

**Experimentation**: Trying new settings is safe. Create a new child
SetBox, experiment, and discard if unsuccessful. The parent SetBox
remains unchanged.

---

## Target Users

### Amateur Radio Operators

**Experienced Operators**: Hams who understand radio theory and want
maximum control over their equipment. NexRx provides direct access to
every parameter while simplifying complex operations through SetBoxes.

**Digital Mode Enthusiasts**: Built-in decoders and optimized
configurations for digital modes.

**Contesters**: Rapid band/mode switching via SetBoxes. Multiple
receiver windows. Logging integration.

**Experimenters**: Open-source design invites modification. Add new
digital modes, implement advanced DSP algorithms, design custom UI
panels—all without hardware changes.

### Developers and Researchers

**RF Engineers**: Complete schematics and design documentation enable
detailed analysis and optimization. The modular architecture supports
subsystem replacement without redesigning the entire radio.

**Software Developers**: The Lua-based UI is highly accessible for customization. Contribution doesn't require deep embedded systems expertise.

**Educators**: NexRx serves as a teaching platform for SDR concepts,
DSP algorithms, RF engineering, and software architecture.

### Open-Source Community

Anyone interested in advancing amateur radio technology. Contributions
range from documentation improvements to hardware revisions to
software enhancements. The MIT License ensures that improvements
benefit the entire community.

---

## System Specifications

### Frequency Coverage

**Receive**: 1.0 - 30 MHz continuous (general coverage)

### Receiver Performance

**Architecture**: Dual-OSD direct conversion with complementary image rejection

**Preselection**: Band pass filters with overlapping ranges for full
HF coverage and an additional high pass filter to reject the AM
broadcast band.

**Sampling Rate**: 96 kHz per channel (four channels: I/Q for each of two OSDs), pre-stitched into 384 ksps
**ADC Resolution**: 24-bit
**Dynamic Range**: >100 dB (achievable with dual-OSD combining and gain ranging)
**MDS (Minimum Detectable Signal)**: Better than -130 dBm (estimated, 500 Hz BW, 10 dB SNR)

### Physical Interfaces

**Power**: USB-C connector.
**Data**: RJ45 Ethernet, 100 Mbps (Fast Ethernet) or USB2 480Mb/s (still pending).
**Antenna**: SO-239 or Type-N connector (TBD)

### Control and Monitoring

**Microcontroller**: STM32H753, 480 MHz Cortex-M7, 1MB flash, 1MB RAM, Zephyr RTOS
**FPGA**: Lattice iCE40UP5K-SG48I, 40 MHz TCXO reference, NCO and clock generation
**Voltage Monitoring**: USB VBUS input

---

## Conclusion

NexRx represents a modern approach to amateur radio receiver
design, combining sophisticated RF engineering with flexible software
control. The dual-OSD receiver architecture and SetBox configuration
system provide capabilities typically found only in commercial
equipment costing thousands of dollars.

The open-source nature of the project—hardware, firmware, and
software—encourages experimentation, learning, and community
contribution.

The following documents provide detailed technical information:

- **RX-ARCHITECTURE.md**: Complete receiver design (preselector, OSDs, PGAs, ADC, AGC)
- **SYSTEM-INTEGRATION.md**: Power system, connectivity, protocols, firmware/FPGA design, calibration
- **CONSTRUCTION-TESTING.md**: Assembly procedures, testing, calibration, validation

Welcome to the NexRx project. We look forward to your contributions and innovations.

---

**Document Revision**: 1.1
**Last Updated**: March 2026
**Project Repository**: https://github.com/alanmimms/nexrx.git
**License**: MIT License - See LICENSE.md

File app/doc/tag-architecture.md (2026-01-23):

# Unified Tag & SetBox Architecture

## 1. Executive Summary

NexRx utilizes a **Digital-First** architecture where application state, UI layout, and hardware control are unified into a single reactive system. There is no hardcoded layout engine; instead, **SetBoxes** contain **Rules** that match **Tags** to derive **Properties**. Drawing occurs from first principles every frame, ensuring the UI is always bit-identical to the underlying configuration.

## 2. Core Principles

* **Everything is a Widget**: Every visible element (text, waterfalls, buttons) is a widget responding to the same tag-based lifecycle.
* **Behavior via Rules**: Styling and event handling are declared in SetBoxes, not hardcoded in Lua.
* **Reactive Synchronicity**: UI properties are **Reactive Observables**. A change in a SetBox property triggers an immediate topological reflow of the UI.
* **Live-Round-Trip**: The UI can be manipulated graphically (Design Mode) to update SetBox properties, which are then serialized back to Lua files.

## 3. The Tag System

Tags are namespaced strings representing the current environment. The **Active Tag Set** is recomputed every frame from five sources:

| Namespace | Source | Examples |
| --- | --- | --- |
| `widget.` | Widget Identity | `widget.VfoA`, `widget.Waterfall` |
| `state.` | App/Hardware State | `state.Mode-USB`, `state.Hardware-Twin` |
| `input.` | Held Inputs | `input.SHIFT`, `input.MouseLEFT` |
| `event.` | Transient Events | `event.MouseDown-LEFT`, `event.KeyDown-H` |
| `layout.` | Structural Forces | `layout.Anchor-Left`, `layout.Spring-H` |

### Comparison Syntax

Rules can match against widget properties using comparison operators:

* `tag.prop==value` (Equals)
* `tag.prop>value` (Greater than)
* `tag.prop~A,B,C` (Value in set)

## 4. SetBox Rules & Scoring

A **SetBox** is a hierarchical configuration container. It contains rules that apply properties when a specific combination of tags is active.

### Priority and Overrides

Each tag in a rule can have a priority suffix `@N` (default `@1`).

```lua
-- Rule 1: Global Default
rule { tags = {"widget.Button"}, apply = { bg = "#374151" } } -- Score = 1

-- Rule 2: Hover State (Higher priority)
rule { tags = {"widget.Button@10", "state.Hovered@5"}, apply = { bg = "#3b82f6" } } -- Score = 15

```

The rule with the highest total score (sum of tag priorities) determines the property value. This allows child SetBoxes to override parent behavior by providing more specific or higher-priority rules.

## 5. Reactive Property Integration

Properties are not static values; they are **Computeds** in the Reactive Property System.

* **Lazy Evaluation**: Properties are only re-calculated when a dependency (like a changed SetBox value) is updated.
* **Topological Updates**: If the `layout.SidebarWidth` changes, all dependent widgets (VFOs, Waterfalls) reflow in the correct order to prevent visual "glitches".

## 6. Layout via Attraction Forces

Instead of rigid Docks or Splits, NexRx uses an **Attraction Force Model**. Layout is determined by reactive "springs" and "anchors" defined in rules:

* **Anchors**: Fixed relationships to container edges (e.g., `anchorLeft = 0`).
* **Springs**: Flexible distribution of space (e.g., `springHorizontal = 1.0`).
* **Reserving Space**: Widgets use the `layout.reserveSpace(w, h)` property to influence the cursor of their parent container.

## 7. The Live-Round-Trip (Design Mode)

The "Live-Round-Trip" allows the GUI and Lua code to be manipulated interchangeably.

1. **Enter Design Mode**: Activating `state.DesignMode` triggers rules that add visual handles (borders, resize grips) to all widgets.
2. **Manipulation**: Moving a widget via `event.MouseMove` updates the corresponding **Observable** in the active SetBox.
3. **Reflow**: The reactive core detects the change, updates the layout properties, and the UI draws the new position in the next frame.
4. **Serialization**: A reactive **Watcher** monitors the SetBox and writes the updated Lua rule definitions back to the project repository.

## 8. Event Bubbling & Handlers

Events are transient tags. When an event occurs:

1. **Tag Injection**: Transient tags like `event.MouseDown-LEFT` are added to the Active Set.
2. **Bubbling**: The event includes tags from the target widget and all parent containers.
3. **Handler Execution**: The highest-scoring rule with a `handler` property executes its Lua function.
4. **Completion**: If the handler returns `true`, the event is consumed; otherwise, it continues to bubble.

## 9. Implementation Standards

* **Naming**: CamelCase for methods/variables, SNAKE_CASE for constants.
* **Performance**: Targeting >= 60fps on host hardware for smooth manipulation.
* **Asynchronicity**: UI rendering is asynchronous to DSP; structural changes do not interrupt the I/Q stream.

---

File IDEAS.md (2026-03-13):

# List of ideas to work in someday or soon

* Add "auto" tuning to click on a signal in spectrum, analyze what
  that signal is with DSP, etc., and tune to hear it properly, setting
  demod mode, bandwidth, precise frequency to tune it, etc.

  * Add a "auto clean" to narrow bandpass filters, add notch(es) to
    eliminate interference, maybe find best noise blanking technology
    to use for the current signalbox.

* Build minimize solution for parts of the UI.

* Build detent-set based sliders for setting eg AGC mode instead of
  the four buttons. Should this be used for volume? RF gain?
  
* RF gain is currently a small integer in control commands. Why isn't
  this a 0..1 float? Attenuator blocks aren't the only thing
  controlled by it. PGA and audio codec permit fine grained gain.

* Add mechansism to tune bandpass width.

* Implement AGC

* Implement zoom for spectrum/waterfall

* Consider greater sample rates

* Change CALIBRATE to "I/Q balance cal" in utilities subUI

* Build notch filter solution - especially for CW over top of SSB and vice versa.

* Build decoder plugin solution.

* Build CW decoder.

* Build RTTY decoder.

* Build SSTV decoder.

* Build FT8 decoder.

* Use bands.lua data to create bands list for buttons.

* Use a new modes.lua to create modes list for modes.

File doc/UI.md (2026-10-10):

# NexRx UI Architecture Guide

## Overview

NexRx is a high-frequency (HF) amateur radio receiver built on a novel
hardware design. It streams dual OSD I/Q samples (up to 384 kS/s)
via a 480Mb/s USB connection to a host PC.

The software architecture divides responsibilities strictly to
maintain high performance while offering maximum flexibility. The host
application is built in C++ to handle the last stages of digital
signal processing (DSP) and real-time data constraints. The user
interface, however, is driven entirely by Lua 5.4, utilizing Raylib
and SDL2 to render an immediate-mode, OpenGL-accelerated GUI that
operates similarly to a high-framerate video game UI.

This document outlines the core concepts, data structures, and layout
philosophies of the NexRx UI engine.

---

## Core Philosophy

* **Strict Language Separation:** C++ does the heavy lifting (DSP,
  hardware interfacing, raw OpenGL rendering). Lua dictates the logic,
  layout, state, and UI hierarchy.
* **Data-Driven UI:** The UI is constructed as a tree of Lua tables.
  This structural approach ensures the UI can easily be serialized,
  modified at runtime, and eventually manipulated via a Drag-and-Drop
  (DND) visual editor.
* **Decoupled Layouts:** Widgets do not contain their own positioning
  math. They declare their constraints (stuck edges, proportional
  mapping, flex), and a contextual layout function processes the
  container to position the children.
* **FPS-Style Rendering:** The UI does not use a "dirty rectangle" or
  traditional retained redraw system. It renders continuously,
  allowing for seamless zooming, panning, and animations in critical
  components like the RF spectrum and waterfall.

---

## Architecture Components

### 1. The Widget Types and Instances

The UI differentiates strictly between a **Widget Type** (the
definition or class) and a **Widget Instance** (the realized object in
the tree).

A Lua metatable DSL (Domain Specific Language) allows developers and
users to construct the UI declaratively. Every hierarchy begins with a
`Window` root node.

```lua
local WidgetInstance = {}
WidgetInstance.__index = WidgetInstance

-- Defines a new widget class
local function defineWidgetType(typeName)
  local widgetType = { typeName = typeName }
  
  setmetatable(widgetType, {
    __call = function (cls, def)
      local instance = {
        type = cls.typeName,
        id = def.id or "",
        props = def.props or {},
        tags = def.tags or {},
        children = def.children or {},
        parent = nil
      }
      
      local nChildren = #instance.children
      for i = 1, nChildren do
        instance.children[i].parent = instance
      end
      
      setmetatable(instance, WidgetInstance)
      return instance
    end
  })
  
  return widgetType
end

local Window = defineWidgetType("Window")
local VBox = defineWidgetType("VBox")
local Checkbox = defineWidgetType("Checkbox")

```

### 2. Theming and State (Tags)

State is managed through a hierarchical tag system. Themes are defined
globally using normalized RGBA color values (0.0 to 1.0). When a
widget renders, it resolves its style by traversing its tag hierarchy
(Local -> Container -> Window -> Global).

```lua
local function hexToRgba(hexStr)
  local hex = string.gsub(hexStr, "#", "")
  local hexLen = string.len(hex)
  
  local r = tonumber(string.sub(hex, 1, 2), 16) / 255.0
  local g = tonumber(string.sub(hex, 3, 4), 16) / 255.0
  local b = tonumber(string.sub(hex, 5, 6), 16) / 255.0
  local a = 1.0
  
  if (hexLen == 8) then
    a = tonumber(string.sub(hex, 7, 8), 16) / 255.0
  end
  
  return { r, g, b, a }
end

local theme = {
  default = {
    background = { style = "fill", color = hexToRgba("#1c1c1cFF") },
    foreground = { textColor = { 0.86, 0.86, 0.86, 1.0 }, lineColor = { 0.0, 1.0, 0.0, 1.0 } }
  }
}

```

This allows a global state change (e.g., adding a `"transmitting"`
tag) to instantly alter the appearance or behavior of deeply nested
leaf widgets, such as checkboxes or sliders, without requiring tight
coupling.

### 3. Layout Strategies

Layout logic is treated as a swappable strategy applied to containers.
The layout function interprets a child's constraints (e.g., edge
sticking) and distributes available space.

The layout process uses the Stick bits to pin the edges of a given
widget to its siblings corresponding adjacent or parent's
corresponding edge to make its size fill or not fill the available
space. This is done in box X and Y axes based in the stickiness bits.
The size of a label is taken into account for its height and width to
force the parent's dimensions to encompass it if it's tallest or
widest of the kids.

#### Generic Sticking and Stretching

For standard UI elements (buttons, panels), widgets declare their
adhesion to container boundaries via the `props.stick` table.

```lua
local function applyHorizontalSticking(container)
  local nChildren = #container.children
  local parentWidth = container.props.width
  local currentX = container.props.x
  
  for i = 1, nChildren do
    local child = container.children[i]
    local stick = child.props.stick or {}
    local padLeft = child.props.padLeft or 0
    local padRight = child.props.padRight or 0
    
    if (stick.left and stick.right) then
      child.props.width = parentWidth - padLeft - padRight
      child.props.x = currentX + padLeft
    elseif (stick.left) then
      child.props.x = currentX + padLeft
    elseif (stick.right) then
      child.props.x = (currentX + parentWidth) - child.props.width - padRight
    end
    
    currentX = currentX + child.props.width + padLeft + padRight
  end
end

```

#### Proportional Mapping (Data-Driven Placement)

For SDR-specific widgets, like a `SignalBox` representing a
demodulation target on the spectrum, positioning is mapped directly
from the domain data (frequency) to screen space, bypassing
traditional flex or grid rules.

```lua
local function spectrumLayout(container)
  local fMin = container.props.freqMin
  local fMax = container.props.freqMax
  local span = fMax - fMin
  local nChildren = #container.children
  
  for i = 1, nChildren do
    local child = container.children[i]
    if (child.type == "SignalBox") then
      local startFreq = child.props.centerFreq - (child.props.bandwidth / 2.0)
      local xRatio = (startFreq - fMin) / span
      local wRatio = child.props.bandwidth / span
      
      child.props.x = container.props.x + (xRatio * container.props.width)
      child.props.width = wRatio * container.props.width
    end
  end
end

```

### 4. The C++ Bridge

The C++ host provides primitive rendering functions and handles
high-throughput data. To maintain performance and follow project
conventions, the API utilizes standard C strings (`const char*`)
rather than standard library string objects, avoiding unnecessary
allocations during the render loop.

Functions are generalized, and templates are reserved strictly for
handling varying DSP data types.

```cpp
class RenderBridge {
public:
  void drawWidgetBorder(const char* widgetId, int x, int y, int w, int h, const char* borderStyle) {
    constexpr int borderThickness = 2; 
    
    if (strcmp(borderStyle, "dashed") == 0) {
      // Execute Raylib dashed line draw
    } else if (strcmp(borderStyle, "solid") == 0) {
      // Execute Raylib solid line draw
    }
  }

  template <typename DSP_PAYLOAD>
  void drawWaterfallRegion(const char* widgetId, int x, int y, int w, int h, const DSP_PAYLOAD* dspData, int dataSize) {
    constexpr int bytesPerPixel = 4;
    constexpr int textureWidth = 1024;
    constexpr int maxBufferSize = textureWidth * 1024 * bytesPerPixel; 
    
    for (int i = 0; i < dataSize; ++i) {
      // Map dspData[i] to waterfall texture and render via Raylib
    }
  }
};

```

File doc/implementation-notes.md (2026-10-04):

# NexRx: Implementation and Design Notes

This document captures non-obvious design decisions and architectural
details discovered during schematic analysis.

---

## Active Bias Voltage Generation

### Design Choice
The receiver uses an **OPA1692** operational amplifier to buffer
resistive voltage dividers, creating the `+1.65V` (OSD) reference.

### Rationale
*   **Low Source Impedance**: The OSD sampling capacitors (8.2nF)
    charge at frequencies up to 120 MHz. An active buffer ensures the
    bias point remains stable during these rapid switching events,
    preventing "bias sag" that would degrade I/Q balance.
*   **Noise Isolation**: The OPA1692 is a high-performance audio op-amp
    with extremely low noise. It filters residual noise from the
    digital power rails that might leak through the resistive
    dividers.
*   **Multiple Load Driving**: A single buffered reference can drive
    both OSD channels crosstalk or voltage variation between channels.

---

## RF Switching with pHEMTs

### Design Choice
The preselector and attenuator stages utilize **AS183-92LF** -- and
their relatives, **SKY13322-375LF** -- pHEMT (pseudomorphic High
Electron Mobility Transistor) switches.

### Rationale
*   **High Linearity**: With an Input IP3 of +43 dBm, these switches
    can handle very strong signals (up to +20 dBm) without
    introducing intermodulation distortion.
*   **Low Insertion Loss**: 0.3 dB loss at HF frequencies preserves
    system noise figure.
*   **Zero DC Power**: Unlike PIN diodes, pHEMT switches require
    negligible current to maintain their state, reducing heat and
    power consumption.

---

## Cascaded Protection Strategy

The receiver implements a four-stage protection chain to ensure
survivability in harsh RF environments:

1.  **GDT (Gas Discharge Tube)**: Located at the SMA antenna input.
    Acts as the "heavy hitter" for lightning-induced surges or
    massive static discharge.
2.  **25V pk-pk Limiter**: A TVS diode array before the digital
    attenuators. Protects the attenuator switch chips from nearby
    high-power transmitters (+40 dBm survival).
3.  **13V pk-pk Limiter**: A second stage before the preselector.
    Protects the sensitive OSD analog switches from transients that
    bypass the primary limiter.
4.  **ADC Input Diodes**: Final BAV99-style clamping at the TLV320ADC5140
    inputs to ensure signals never exceed the ADC's power rails.

---

## Transformer Symmetry

### Design Choice
The 200Ω to 3x22Ω output transformer uses **hexafilar winding** on a
BN-43-202 binocular core.

### Rationale
*   **Phase/Amplitude Matching**: The dual-OSD architecture relies
    on mathematical cancellation of images and harmonics. This requires the
    two RF inputs to the OSDs to be as identical as possible.
*   **Magnetic Coupling**: Hexafilar winding (twisting all six wires
    together before winding) ensures that leakage inductance and
    coupling coefficients are perfectly matched across all channels.

## OSD Biasing Implementation

### Design Choice
The final implementation uses **10kΩ** bias resistors for the OSD inputs (instead of the 100kΩ originally considered).

### Rationale
*   **Thermal Noise Reduction**: Lower resistance values reduce the
    Johnson-Nyquist noise contribution at the sensitive OSD input stage.
*   **Improved Settling Time**: 10kΩ provides a faster RC time constant
    with the AC coupling capacitors, ensuring the DC bias point settles
    quickly during power-up or rapid signal transients.
*   **Dynamic Range**: The reduced noise floor directly contributes to
    the high dynamic range targets of the receiver.

---

## High-Speed USB Connectivity

### Design Choice
The receiver utilizes an external **USB3343** ULPI (UTMI+ Low Pin Interface)
transceiver instead of the STM32's internal Full-Speed PHY.

### Rationale
*   **High-Speed Data Rates**: The NexRx streams two channels of 24-bit
    baseband data (streamed at 384 ksps). At ~12.25 Mbps of raw throughput (plus overhead),
    this exceeds the reliable capacity of standard 12 Mbps Full-Speed USB.
*   **480 Mbps Capability**: The USB3343 provides a true High-Speed (480 Mbps)
    interface, ensuring that the USB bus is never a bottleneck for
    real-time spectral visualization and audio processing.
*   **Offloading Microcontroller**: Using an external PHY allows the
    STM32H753 to focus its computational resources on DSP and AGC
    tasks rather than managing the low-level physical USB signaling.

# Testing and Twin

The digital twin hardware simulation takes considerable multi-core CPU
horsepower to run. You will want to run this on a pretty high end
modern CPU. I use a 32 core (64 thread) AMD Ryzen Threadripper 2990WX
at 2.2GHz. Fortunately, this level of horsepower is usually only
needed if you don't have hardware.

The NexRx app is architected to require substantially less power
(TBD). Estimates are:

* UDP network ingest thread: < 2% CPU.
* Stage D DSP / Demodulation thread: about 18% to 25% of one core.
* Raylib UI / Render thread: about 4% to 6% of one core.

## Realtime Scheduling of Twin

To run the "twin" testing against the app (digital twin to stand in
for hardware), you might want to grant realtime capability to your
username. These instructions apply for modern (Ubuntu 26.04 is what
I'm using) Linux.

You can grant non-root users permission to use POSIX realtime
scheduling (like `SCHED_FIFO` or `SCHED_RR`) and memory locking by
configuring PAM (Pluggable Authentication Modules) limits. This is the
standard mechanism to run high-performance audio or SDR DSP code
natively without requiring `sudo`.

1. **Create a Realtime Group:** Terminal.

First, create a dedicated group for users who need realtime execution
privileges.

```bash
sudo groupadd realtime

```

**Verification:** Run `getent group realtime` to confirm the group was
successfully added to the system.

2. **Add Your User to the Group:** Terminal.

Add your current user account to this new group.

```bash
sudo usermod -aG realtime $USER

```

**Verification:** Run `groups $USER` and ensure `realtime` appears in
the output list.

3. **Configure PAM Limits:** File Editing.

Create a new limits configuration file that delegates realtime
priority (`rtprio`) and unlimited memory locking (`memlock`) to
members of the group. The `@` symbol denotes a group rather than a
specific user.

```bash
sudo nano /etc/security/limits.d/99-realtime.conf

```

Paste the following two lines into the file and save it:

```text
@realtime - rtprio 98
@realtime - memlock unlimited

```

**Verification:** Run `cat /etc/security/limits.d/99-realtime.conf` to
ensure the file contains the correct text exactly as written.

4. **Apply and Verify Limits:** Session Restart.

PAM limits are evaluated strictly at login. You must completely log
out of your Ubuntu desktop session and log back in (or reboot) for the
changes to take effect.

**Verification:** Open a new terminal and run `ulimit -r` to confirm
it returns `98`, and `ulimit -l` to confirm it returns `unlimited`.
Your `signalgen` and host application processes can now execute
realtime functions without root access.

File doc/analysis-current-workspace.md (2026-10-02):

# Analysis: Current Workspace Signal Path

## Twin Signal Generator (SignalGen.cpp)
- **Oversampling**: 5x (480 kHz rate).
- **Anti-Aliasing**: 6th-order elliptic filter (fc=40kHz) at 480 kHz.
- **Decimation**: Proper 5:1 decimation (no boxcar averaging found in the latest code).
- **Quantization**: 24-bit with TPDF dithering.
- **LO Generation**: Incremental phase rotation with **normalization every sample** (`std::sqrt` and `1.0/mag`).
- **Phase Continuity**: Maintained during frequency updates (no reset).
- **Simulated Hardware Errors**: Applied at the 480 kHz rate.
- **Control**: CBOR-based protocol (`SVFO`, `SPRL`, etc.).

## App Control Path (GuiEngine.cpp & AppController.lua)
- **VFO Tuning**: `rx.setVFO` is called via the Model's reactive system.
- **VFO Offset**: Correctly sends 12000.0 Hz (12kHz * 1000) for the default offset.
- **Issue**: There is a potential race or miscommunication where `SVFO` is not seen in logs, while `SPRL/SPRC` are. This might be due to the `rx` global not being correctly accessed or the `postCommand` mechanism in `GuiEngine.cpp`.

## App Receive Path DSP (DspEngine.cpp)
- **Frequency Alignment**: Uses `std::fmod`, `std::cos`, and `std::sin` every sample based on `totalSamplesProcessed`. This is expensive and susceptible to phase jumps if packets are dropped.
- **Image Rejection (LMS / Calibration)**:
  - Uses Dual-OSD Coherent Summation: `combined = 0.5 * (wA0 * S0' + S1')`.
  - Learning Rate (`mu`): 0.05 (50x larger than gemini-app-start). This high rate likely causes the LMS to correlate on noise and "chatter," creating the reported noise floor artifacts.
  - Leaky LMS: Adds a `1.0 - leak` term which can also add noise if not tuned carefully.
- **Matrix Bypass**: Allows raw S0' output.

## Root Cause Comparison
1. **Noise Floor**: Highly likely caused by the high LMS learning rate (0.05) and matrix combination which spreads LMS chatter across the spectrum.
2. **Tuning Glitches**: Not present in Twin (incremental rotation is smooth), but potential timing issues in App due to `totalSamplesProcessed` reference.
3. **VFO Command Failure**: Likely a Lua-to-C++ binding or Model update synchronization issue.

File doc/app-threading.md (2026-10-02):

# Threading Architecture

1. Main (UI) Thread:

   * *Function*: Manages the SDL2 window, OpenGL context, and the Lua
     environment.

   * *Responsibilities*: Processes user input (mouse/keyboard),
	 executes the Lua update() and draw() loops, renders the Waterfall
	 and Spectrum, and handles all File I/O (loading config, logging).

   * *Constraints*: Must never block on network or heavy DSP;
     otherwise, the UI "stutters."

2. DSP (Reception) Thread:

   * *Function*: High-priority thread managed by TwinConn that
     triggers upon arrival of network IQ frames.

   * *Responsibilities*: Performs frequency shifting (LO rotation),
	 Dual-OSD combination, LMS balancing, baseband filtering, and
	 demodulation.

   * *Constraints*: Strictly No-Blocking. No std::cout, no printf, no
	 File I/O, and absolutely no Lua calls. Communication with other
	 threads is done via thread-safe lock-free buffers (audioBuffer,
	 iqBuffer) or atomic variables.

3. Audio Callback Thread:

   * *Function*: System-managed thread that pulls samples from the
     application to feed the sound card (via SDL_Audio).

   * *Responsibilities*: Reads from the audioBuffer (populated by
     DSP), and applies master volume.

   * *Constraints*: Must return quickly to prevent audio under-runs
     (clicks/pops).

4. Command (Worker) Thread:

   * *Function*: Asynchronous queue processor.

   * *Responsibilities*: Serializes outgoing control commands (Set
     VFO, Set Gain) to the hardware/twin over TCP.

   * *Constraints*: Prevents network latency from blocking the UI
     thread during property changes.

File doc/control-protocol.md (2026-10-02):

# NexRx Control Protocol Specification

This document defines the communication protocol used for control and
configuration between the NexRx Application (Client) and the NexRx
Digital Twin or Physical Hardware (Server). This protocol is only for
the _control plane:_ It doesn't carry digital media streaming data. It
gives the NexRx host app control over the hardware and software in the
NexRx radio.

## 1. Overview

The control plane uses a reliable, bi-directional stream for sending
commands and receiving responses. It is designed to be
transport-agnostic, though currently implemented over TCP/IP for use
with the digital twin.

*   **Default TCP Port:** 5000
*   **Role:** The App is the Client; the Twin/Hardware is the Server.
*   **Model:** Synchronous Request-Response using CBOR.

## 2. Transport Layer

The protocol runs over TCP. To ensure low-latency performance, the
`TCP_NODELAY` option (Nagle's algorithm disabled) is enabled on both
sides.

## 3. Framing

Every message (request and response) is encapsulated in a binary frame.

### 3.1 Frame Structure

| Offset | Size | Type | Description |
| :--- | :--- | :--- | :--- |
| 0 | Var | CBOR uint | **Payload Length**: The number of bytes in the following payload, encoded as a CBOR unsigned integer. |
| Var | N | bytes | **Payload**: The CBOR-encoded message data. |

*   **Byte Order:** CBOR encoding naturally handles byte order (network byte order).

## 4. Message Format (CBOR)

All payloads are encoded using **CBOR (Concise Binary Object Representation)**.

### 4.1 Request Format

A request is a CBOR array:
`[command_id, [args...]]`

*   **command_id**: A 4-byte text string identifier.
*   **args**: An array of arguments specific to the command.

### 4.2 Response Format

A response is a CBOR array:
`[status_code, payload]`

*   **status_code**: 0 for success (`OK`), non-zero for errors.
*   **payload**: Command-specific return data (e.g., a string, a nested array, or a JSON string).

## 5. Command Reference

### 5.1 System Control

| Command | ID (String) | Args | Description |
| :--- | :--- | :--- | :--- |
| `START_STREAM` | `STM[` | `[]` | Enables IQ data streaming via the UDP data plane. |
| `STOP_STREAM` | `]STM` | `[]` | Disables IQ data streaming. |
| `GET_STATUS` | `GSTS` | `[]` | Returns a JSON string containing system status. |
| `GET_CONFIGURATION`| `GCNF` | `[]` | Returns a JSON string describing hardware capabilities. |
| `DISCONNECT` | `GBYE` | `[]` | Hint from client that it is closing the connection. |

### 5.2 Receiver Configuration

| Command | ID (String) | Args | Description |
| :--- | :--- | :--- | :--- |
| `SET_OSD_VFO` | `SVFO` | `[index, freq_hz]` | Sets the NCO frequency for OSD 0 or 1. |
| `SET_ATTEN` | `SATT` | `[db_value, enabled]` | Enables/disables a specific attenuator stage (3, 6, 12, or 24 dB). |
| `SET_HPF_BYPASS` | `SHPB` | `[bypass]` | Bypasses the 1.75 MHz AM reject High Pass Filter if true. |
| `SET_BPF_SELECT` | `SBPF` | `[index]` | Selects one of the 5 BPFs (1=1.8-3.4, 2=3.2-7.5, 3=7.3-14.5, 4=14.3-22, 5=21.8-30). 0 for bypass. |
| `SET_PGA_GAIN` | `SPGA` | `[gain_db]` | Sets the gain for TLV320ADC5140 audio ADC PGAs across both OSD converters. |
| `SET_TR_MODE`  | `STRM` | `[mode]` | Sets T/R mode: 0=RX (default), 1=TX. |

### 5.3 Internal Signal Generator (ISG)

The Internal Signal Generator provides a reference signal for calibration and testing.

| Command | ID (String) | Args | Description |
| :--- | :--- | :--- | :--- |
| `SET_ISG_ENABLE`| `SIEN` | `[enabled]` | Master power control for the ISG. |
| `SET_ISG_FREQ` | `SIFQ` | `[freq_hz]` | 0=Disabled, 1=White Noise, >1=Single Tone (Hz). |

### 5.4 Calibration

Calibration data is stored as JSON strings.

| Command | ID (String) | Args | Description |
| :--- | :--- | :--- | :--- |
| `SET_CALIBRATION`| `SCAL` | `[type, json_data]` | Stores a JSON calibration string for a specific type. |
| `GET_CALIBRATION`| `GCAL` | `[type]` | Retrieves a JSON calibration string. |

### 5.5 Audio ADC (TLV320ADC5140)

Configures the TLV320ADC5140 audio ADC parameters across both OSD converters (four 24-bit channels at 384ksps per OSD).

| Command | ID (String) | Args | Description |
| :--- | :--- | :--- | :--- |
| `SET_CODEC` | `SCOD` | `[rate, [ch_map...], gain, filter]` | Configures sample rate, channel mapping, gain, and filter type. |

## 6. Philosophy

The philosophy for the attenuator and the L and C components in the
preselector is to provide raw calibration and hardware capability data
to the application and have the application determine which specific
components to enable to achieve its goals.

This ensures that if complex calculations are required—for example,
combining calibration data with DSP signal metrics to determine the
optimal L/C/Attenuator configuration—these calculations are performed
on the host application where significantly more compute power is
available compared to the embedded controller.

## 7. Data Plane (UDP/USB)

High-bandwidth IQ sample data is sent over a separate UDP stream (Digital Twin)
or USB Bulk endpoint (Physical Hardware).

### 7.1 Digital Twin Format (CBOR / Version 1)

The Digital Twin uses CBOR-encoded arrays for UDP packets:
`["NXRQ", 1, type, frames]`

### 7.2 Physical Hardware Format (Binary / Version 2)

To minimize MCU overhead, the physical hardware uses a fixed-length binary
header for USB Bulk transfers.

| Offset | Size | Type | Description |
| :--- | :--- | :--- | :--- |
| 0 | 4 | uint32 | **Magic**: `0x52584E51` ("NXRQ") |
| 4 | 4 | uint32 | **Version**: `2` (Binary Format) |
| 8 | 4 | uint32 | **Sequence**: 32-bit packet counter |
| 12 | 8 | uint64 | **Timestamp**: 64-bit nanosecond timer |
| 20 | 4 | uint32 | **Frame Count**: Number of I/Q frames (4 channels/frame) |
| 24 | N | int32[] | **Samples**: Interleaved `[i0, q0, i1, q1, ...]` |

*   **Sample Alignment**: Each sample is a 32-bit signed integer (S24 sign-
    extended to S32).
*   **Frame Structure**: A single "frame" consists of 4 samples (I/Q for two
    OSD stages).

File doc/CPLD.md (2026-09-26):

# NexRx CPLD Architecture (iCE40LP384-SG32)

This document describes the design, register map, and verification
flow for the NexRx CPLD SystemVerilog logic (`CPLD/rtl/top.sv`).

## Architecture Overview

Two identical iCE40LP384 CPLD ICs are deployed in the system—one
dedicated to **OSD0** and one to **OSD1**. Each CPLD acts as a
GNSS-disciplined, precision 8-phase octature or 4-phase quadrature
clock generator.

### Key Components

*   **Walking Ring Phase Generator**: A software-configurable one-hot
    counter that converts the synthesizer input clock (`osdClk`, pin
    20) into non-overlapping multiphase switching signals
    (`nPh[0..7]`).
    *   **8-Phase Octature Mode**: Active below 15 MHz ($8 \times
        \text{VFO}$ input clock up to 120 MHz).
    *   **4-Phase Quadrature Mode**: Active above 15 MHz ($4 \times
        \text{VFO}$ input clock up to 120 MHz).
*   **Waterfall Viewport Hysteresis Rule**: To eliminate visual
    discontinuities and mode thrashing in the waterfall display around
    15 MHz, software evaluates the active waterfall viewport
    boundaries:
    *   Switch to **4-phase mode** occurs **only when the entire
        waterfall viewport is strictly above 15 MHz**.
    *   Switch to **8-phase mode** occurs **only when the entire
        waterfall viewport is strictly below 15 MHz**.
    *   When the waterfall viewport straddles 15 MHz (e.g. 14.9 MHz to
        15.1 MHz), the current clock mode is preserved.
*   **GNSS TCXO Discipline Counter**: A monotonic 64-bit counter
    clocked directly by the 40 MHz master TCXO (`tcxo`, pin 29) and
    latched on the rising edge of the 1pps timing pulse from the GNSS
    chip (`gnssPPS`, pin 32). The latched 64-bit value is read via SPI
    by the STM32 to compute exact TCXO frequency offset and drift.
*   **SPI Slave Interface**: A 40-bit register-mapped SPI slave (8-bit
    address/command, 32-bit data payload).

## Pin Assignment Summary (`CPLD/rtl/pins.pcf`)

| Signal Name | CPLD Pin | Direction | Description |
| :--- | :--- | :--- | :--- |
| `osdClk` | Pin 20 | Input | Clock input from Si5351 synthesizer output. |
| `tcxo` | Pin 29 | Input | 40 MHz TCXO reference clock. |
| `gnssPPS` | Pin 32 | Input | 1 Hz precision pulse input directly from GNSS receiver. |
| `fpgaMOSI` | Pin 13 | Input | SPI Master-Out Slave-In from STM32. |
| `fpgaMISO` | Pin 12 | Output | SPI Master-In Slave-Out to STM32. |
| `fpgaSCK` | Pin 15 | Input | SPI Serial Clock from STM32. |
| `fpgaNSS` | Pin 14 | Input | SPI Active-Low Chip Select from STM32. |
| `nPh[0..7]` | Pins 1, 5, 8, 2, 18, 22, 23, 19 | Output | Non-overlapping 8-phase clock outputs to OSD switches. |

## Register Map (32-bit wide)

See `CPLD/rtl/regs.py` for register generators.

| Address | Mode | Name | Description |
| :---: | :---: | :---: | :--- |
| **0x00** | RW | `Control` | Bit 0: Mode Select (0 = 8-phase Octature, 1 = 4-phase Quadrature). Bit 1: Soft Reset. |
| **0x01** | RO | `PPSLatchHi` | High 32 bits of the 64-bit TCXO frequency counter latched on the last 1pps edge. |
| **0x02** | RO | `PPSLatchLo` | Low 32 bits of the 64-bit TCXO frequency counter latched on the last 1pps edge. |
| **0x7F** | RO | `Sig` | Hardware signature validation. Always reads `0x4E785278` ("NxRx"). |

## Simulation & Verification

The `CPLD/` directory contains complete SystemVerilog testbenches
(`tb.cpp`) and verification tooling:
*   **Simulation**: `verilator`, `gtkwave`, or `surfer`.
*   **Synthesis & PnR**: `yosys`, `nextpnr-ice40`, and `icepack`.

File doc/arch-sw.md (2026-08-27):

# NexRx Software & Digital Twin Architecture Specification

## 1. System Overview & Partitioning

The NexRx software ecosystem is partitioned into three distinct
operational domains: the **STM32 Embedded Firmware**, the **PC Host
Receiver Engine**, and the **Hardware Digital Twin (`Twin`)**. The
design enforces a strict separation of concerns, offloading real-time
DSP, phase-coherent decimation, and hardware sequencing to embedded
execution while dedicating host resources to high-level filtering,
demodulation, and stream management.

```
┌───────────────────────────────────────────────────────────────────────────────┐
│                             PC Host Application                               │
│  ┌────────────────────────┐   ┌────────────────────┐   ┌───────────────────┐  │
│  │   USB Ingest Engine    │   │ Host-Side ASRC     │   │ Channel Demod     │  │
│  │ (WinUSB/libusb Stream) │─▶│ & Elastic Buffer   │─▶│ (SSB/CW/AM/Modes) │  │
│  └────────────────────────┘   └────────────────────┘   └───────────────────┘  │
│               ▲                                                 │             │
│               │ (2-ch 384ksps I/Q @ 24.576Mbps)                 │             │
└───────────────┼─────────────────────────────────────────────────┼─────────────┘
                |                                                 │
  [USB Bulk Pipe / IPC Socket]                         [High-Level Control Pipe]
                |                                                 │
┌───────────────┴─────────────────────────────────────────────────▼───────────┐
│                          Shared Firmware Core (C++)                         │
│  ┌────────────────────────┐  ┌────────────────────┐  ┌───────────────────┐  │
│  │ DSP Pipeline Engine    │  │ VFO State Machine  │  │ Autonomous BIST   │  │
│  │ (2x4 Matrix, Rot, Sum) │  │ & Mode Hysteresis  │  │ & Goertzel Engine │  │
│  └────────────────────────┘  └────────────────────┘  └───────────────────┘  │
└───────────────────────────────────────┬─────────────────────────────────────┘
                                        │
                         ┌──────────────┴──────────────┐
                         ▼                             ▼
┌───────────────────────────────────┐ ┌────────────────────────────────┐
│     STM32 Physical Platform       │ │    PC Hardware Digital Twin    │
├───────────────────────────────────┤ ├────────────────────────────────┤
│ • STM32 HAL / SAI / I2C / USB     │ │ • HalSynth (Simulated LO)      │
│ • Dual TLV320ADC5140 TDM Ingest   │ │ • HalAudio (Synthetic RF Gen)  │
│ • Si5351 Clock Synthesizer        │ │ • HalTransport (Socket / Pipe) │
│ • CPLD Shift Registers & Relays   │ │ • SamplePacer (384ksps Timer)  │
└───────────────────────────────────┘ └────────────────────────────────┘
```

---

## 2. Shared Firmware Core & Hardware Abstraction Layer (HAL)

To guarantee exact behavioral parity between physical silicon and the
simulation environment without duplicating firmware logic, all core
receiver algorithms compile against C++ Hardware Abstraction
interfaces (see `HAL*.h`). All interface filenames and class
definitions strictly use `PascalCase`, omitting underscores.

---

## 3. STM32 Embedded Firmware Pipeline

### 3.1 DMA Audio Ingest & Polyphase Recombination

* **Physical Ingest:** The STM32 SAI peripheral receives 8
  differential channels across synchronous TDM streams from two
  TLV320ADC5140 converters at 384ksps of 24-bit samples.

* **Intrinsic Harmonic Rejection:** For each 8-way Octal Sampling
  Detector (OSD0 and OSD1), a programmable $2 \times 4$ projection
  matrix converts the 4 differential pairs into orthogonal $I$ and $Q$
  baseband signals, rejecting 3rd and 5th odd harmonics by
  $>60\text{dB}$:

$$I = \text{CH}_1 + \frac{\sqrt{2}}{2}\text{CH}_3 - \frac{\sqrt{2}}{2}\text{CH}_4$$

$$Q = \text{CH}_2 + \frac{\sqrt{2}}{2}\text{CH}_3 + \frac{\sqrt{2}}{2}\text{CH}_4$$

* **Calibration Weighting:** The fixed geometric coefficients
  $\frac{\sqrt{2}}{2} \approx 0.7071$ are dynamically modified by
  calibration offsets stored in non-volatile memory to cancel physical
  analog board imbalances.

### 3.2 Dual-OSD Translation & Coherent Summation

* **Spectral Rotation:** The OSD0 baseband stream is shifted up by
  $+12\text{kHz}$ and the OSD1 baseband stream is shifted down by
  $-12\text{kHz}$ via complex exponential multiplication ($e^{\pm
  j\omega t}$) to center the true RF spectrum at baseband.

* **Vector Summation:** The firmware adds the rotated streams together
  in the time domain, producing a $+6\text{dB}$ constructive
  reinforcement of true RF signals while unaligned hardware images, LO
  spurs, and ADC artifacts are vetoed into the noise floor.

* **DC Hole Mitigation:** Offsetting the local oscillators by $\pm
  12\text{kHz}$ places the physical DC notches of the analog front
  end outside the primary detection passband, eliminating the central
  DC spike without requiring heavy host-side notch filtering.

### 3.3 VFO State Machine & 15.1 MHz Dual-Mode Hysteresis

* **Conversion Gain Compensation:** Polyphase 8-way commutation yields
  a $-0.9\text{dB}$ conversion loss, whereas high-band 4-way Tayloe
  commutation exhibits a $-3.9\text{dB}$ loss. When transitioning to
  4-way mode above 15.1 MHz, the STM32 applies a frame-synchronous
  $+3\text{dB}$ digital gain compensation to maintain a stable
  baseline noise floor.

* **Viewport Hysteresis Window:** The mode transition is governed by a
  300 kHz hysteresis loop (14.950 MHz to 15.250 MHz) tied to the
  active display span, ensuring hardware state transitions never occur
  while the 15.1 MHz boundary is within the active passband.

* **Deterministic Tuning Sequence:**
1. Drive `OutputEnableBar` (OEB) HIGH to halt clock outputs.

2. Write new fractional divider parameters to the Si5351 via I2C.

3. Trigger a soft PLL reset on Si5351 Register 177.

4. Enforce a 1.0 ms settling delay for analog VCO lock.

5. Pulse `CPLDReset` to align walking ring counters to state
   `00000001`.

6. Drive `OutputEnableBar` LOW to simultaneously launch phase-locked
   clocks into the mixers.

### 3.4 Autonomous Scalar Network Analyzer (SNA) BIST Engine

* **Closed-Loop Test Execution:** An on-chip diagnostic state machine
  runs a 113-bin frequency sweep (1.8 MHz to 30.0 MHz in 250 kHz
  steps).

* **Tracking Clock Generation:** Si5351 CH0 outputs a test tone at
  $f$, while CH1 outputs an OSD tracking clock at $4(f + 10\text{
  kHz})$.

* **Goertzel Magnitude Filter:** For each 1.0 ms step (384 samples),
  the STM32 executes a 10 kHz Goertzel magnitude detector on the
  polyphase-recombined baseband stream.

* **ATE Data Export:** The final 113-element magnitude array is
  serialized and output over the USB Virtual COM Port (VCP) as a
  standard CSV/JSON payload.

---

## 4. Hardware Digital Twin (`Twin`)

The `Twin` subsystem models the physical hardware and executes the
identical shared C++ firmware algorithms on the host PC, validating
downstream DSP and host communication paths before physical hardware
assembly.

### 4.1 Architecture & Components

```
┌─────────────────────────────────────────────────────────────────────────────┐
│                          Digital Twin (`Twin`) Execution                    │
│                                                                             │
│  ┌───────────────────────┐                     ┌─────────────────────────┐  │
│  │ Synthetic RF Gen      │                     │ Twin Synth Model        │  │
│  │ (Carriers, Noise, QRN)│                     │ (Calculates LO Freqs    │  │
│  └──────────┬────────────┘                     │  from Si5351 Registers) │  │
│             │                                  └────────────┬────────────┘  │
│             ▼                                               │               │
│  ┌──────────────────────────────────────────────────────────┴────────────┐  │
│  │ Simulated Mixer & ADC Downconversion (OSD0 / OSD1 Commutation)        │  │
│  └──────────────────────────────────────┬────────────────────────────────┘  │
│                                         │                                   │
│                                         ▼ (8 Differential Channels)         │
│  ┌───────────────────────────────────────────────────────────────────────┐  │
│  │ Shared Firmware DSP Core:                                             │  │
│  │ • 2x4 Polyphase Matrix Multiplication                                 │  │
│  │ • NCO Frequency Shifts (+/- 12 kHz)                                   │  │
│  │ • Coherent Summation & Image Vetoing                                  │  │
│  │ • Dual-Mode Gain Normalization (+3 dB)                                │  │
│  └──────────────────────────────────────┬────────────────────────────────┘  │
│                                         │                                   │
│                                         ▼ (2-ch Normalized I/Q)             │
│  ┌───────────────────────────────────────────────────────────────────────┐  │
│  │ SamplePacer & Virtual Transport (IPC Socket / Named Pipe @ 384ksps)   │  │
│  └───────────────────────────────────────────────────────────────────────┘  │
└─────────────────────────────────────────────────────────────────────────────┘

```

### 4.2 Synthetic RF & Mixer Simulation

* **RF Signal Synthesis:** Mathematical signal generators synthesize
  arbitrary RF test environments:

$$S_{\text{RF}}(t) = \sum_{k} A_k \cos(2\pi f_k t + \phi_k) + N_{\text{AWGN}}(t) + N_{\text{Impulse}}(t)$$

* **Simulated LO Tracking:** The `TwinSynth` class intercepts register
  writes to Si5351 MultiSynth parameters and computes the active
  mixing frequencies for OSD0 and OSD1.
* **Commutation Simulation:** The RF input is downconverted by
  multiplying against simulated 8-phase (or 4-phase) switching
  functions, generating 8 differential baseband audio channels with
  simulated analog phase/amplitude skews to enable testing of skew
  compensation algorithms.

### 4.3 Deterministic Sample Pacing

* **Master Clock Authority:** The `Twin` operates as an unyielding
  data master, pumping samples at precisely 384ksps.

* **High-Resolution Pacer:** A dedicated `SamplePacer` thread uses
  high-precision timers (e.g., `std::chrono::steady_clock`) to push
  384 sample pairs every 1.0 ms into the virtual transport.
* **Zero Backpressure:** Transport endpoints operate in non-blocking
  mode; if the host application fails to read incoming blocks in real
  time, the virtual transport buffer overflows, faithfully reproducing
  physical USB DMA overrun behavior.

---

## 5. Host PC Software Architecture

The host PC receiver engine ingests the normalized baseband stream,
resolves clock domain drift, manages adaptive noise cancellation, and
executes mode demodulation.

### 5.1 Driverless USB Transport Layer

* **Protocol:** Vendor-Specific Bulk USB Class utilizing Microsoft OS
  2.0 Descriptors.

* **Platform Binding:**
* **Windows 10/11:** Automatic native binding to `WinUSB.sys` without
  administrative prompts or third-party filter drivers.

* **macOS:** User-space bulk communication via `libusb` / `IOUSBHost`.

* **Linux:** User-space access via standard non-root `udev`
  permissions (`99-nexrx.rules`).

* **Payload Ingest:** Continuously receives a 2-channel, 24-bit
  baseband stream packed into 32-bit words at 384ksps (24.576Mbps
  sustained throughput).

### 5.2 Host-Side Elastic Buffering & Dynamic Time Interpolation

Because the physical STM32 ADC crystal and the host PC sound card DAC
operate on independent physical timebases, the host software
implements host-side sample rate adaptation to prevent FIFO overflow
or starvation.

```
[Incoming USB Bulk Stream / Twin IPC (384ksps Master)]
                         │
                         ▼
[Host Ingest Ring Buffer (Lock-Free FIFO)]
                         │
                         ├────────────────────────────────────────┐
                         ▼                                        ▼
           [Watermark Tracking / Software PLL]         [Baseband DSP Processing]
                         │                             (LMS Noise Filter, Demod)
                         ▼                                        │
           [Fractional ASRC / Interpolator]                       ▼
                         │                             [Audio Output Buffer]
                         └────────────────────────────────────────┤
                                                                  ▼
                                                      [OS Audio DAC Master Clock]
                                                      (WASAPI / CoreAudio / ALSA)

```

* **Ingest Ring Buffer:** Incoming bulk packets are pushed immediately
  into a high-capacity lock-free ring buffer.
* **Buffer Watermark Tracking:** A software tracking loop monitors the
  long-term fill level of the buffer against the local audio
  consumption rate.
* **Asynchronous Sample Rate Conversion (ASRC):** A high-order
  polynomial (or Farrow) fractional interpolator dynamically adjusts
  the resampling ratio by minute fractions of a percent, eliminating
  buffer underruns and overruns without dropping samples or
  introducing audible pitch artifacts.
* **Concealment Engine:** If severe operating system scheduling stalls
  occur, the host applies Vector Blanking and Linear Predictive Coding
  (LPC) interpolation to patch data discontinuities seamlessly.

### 5.3 Demodulation & Fundamental Signal Chain

* **Panoramic Waterfall & Panadapter:** The host computes direct FFTs
  on the incoming pre-stitched, normalized 384ksps $I/Q$ stream,
  displaying a 300 kHz panoramic view with zero DC spike or image
  artifacts.

* **Digital Down-Conversion (DDC):** A software NCO and complex mixer
  translate the desired listening frequency within the 300 kHz
  passband down to zero IF.
* **Demodulation Blocks:**
* **SSB/CW:** Weaver / Phasing method baseband filtering with variable
  bandwidth selection.
* **AM:** Synchronous carrier recovery and envelope detection.
* **Digital Modes:** Baseband routing to external virtual audio
  endpoints for digital decoding.

* **Adaptive Filtering:** Multi-tap Least Mean Squares (LMS) adaptive
  noise reduction and automatic notch filtering operating on the
  extracted audio channel.

---

## 6. Interface & Wire Protocol Specification

### 6.1 USB Bulk Endpoint Architecture

| Endpoint | Direction | Transfer Type | Max Packet Size | Description |
| --- | --- | --- | --- | --- |
| `0x00` | Bidirectional | Control | 64 Bytes | Standard enumeration & MS OS 2.0 descriptors

 |
| `0x81` | IN (MCU $\to$ Host) | Bulk | 512 Bytes | Normalized 2-Channel $I/Q$ data stream (384ksps)

 |
| `0x02` | OUT (Host $\to$ MCU) | Bulk | 64 Bytes | High-level receiver command channel

 |
| `0x83` | IN (MCU $\to$ Host) | Bulk / Interrupt | 64 Bytes | Telemetry, state feedback & SNA sweep responses

 |

### 6.2 Data Stream Framing (`0x81` Bulk IN)

* **Sample Depth:** 24-bit signed integer, sign-extended and
  left-aligned into a 32-bit signed integer word.

* **Channel Interleaving:** Consecutive sample pairs are transmitted
  in alternating $[I_k, Q_k]$ sequence:

$$\text{Payload Word: } [\text{Sample } k \text{ (Channel 0 / } I
\text{)}], [\text{Sample } k \text{ (Channel 1 / } Q \text{)}]$$

* **Data Rate:**

$$2 \text{ channels} \times 32 \text{ bits/sample} \times 384,000
\text{ samples/sec} = 24.576 \text{Mbps}$$

### 6.3 Command Protocol Structure (`0x02` Bulk OUT)

Commands are structured as fixed-header, variable-length binary
packets, where the `n` byte structure is:

	00: Sync Byte (0xA5)
	01: Command ID
	02: Payload Length
	03..n-3: Payload Data (n-5 bytes)
	n-1..n-2: CRC-16-CCITT (16-bits)

#### Core Command Set

* `0x0001` - `SetTunedFrequency`: Payload contains a 32-bit unsigned
  integer representing target center frequency in Hz.

* `0x0002` - `SetAnalogGain`: Payload contains an 8-bit unsigned
  integer setting front-end PGA gain (0 to 42 dB).

* `0x0003` - `SetAttenuator`: Payload contains an 8-bit value in dB to
  specify the input T-pad attenuation required.

* `0x0010` - `TriggerRFSweep`: Payload defines SNA start frequency,
  stop frequency, and step size for autonomous BIST execution.

* `0x0020` - `SetRecombinationWeights`: Payload contains eight 16-bit
  fixed-point coefficients for the $2 \times 4$ polyphase
  recombination matrix.

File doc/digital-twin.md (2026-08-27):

# NexRx Digital Twin Architecture

## 1. Overview

The NexRx Digital Twin (`Twin`) is a Software-in-the-Loop (SiL)
simulation environment that models the physical hardware and executes
the identical shared C++ firmware algorithms natively on the host
PC. It allows the host PC receiver engine (DSP, UI, demodulation) to
be developed, tested, and validated without requiring physical
hardware.

The Twin accurately emulates the RF frontend's Dual Octal Sampling
Detector (OSD) architecture and runs the exact STM32 embedded DSP
pipeline to synthesize the final data stream.

---

## 2. Shared Firmware Core & Hardware Abstraction Layer (HAL)

To guarantee exact behavioral parity between the physical silicon and
the simulation environment without duplicating firmware logic, all
core receiver algorithms compile against abstract C++ Hardware
Abstraction interfaces.

* **HALSynth:** The Twin intercepts simulated I2C register writes to
  Si5351 MultiSynth parameters and computes the active mixing
  frequencies ($f - 12\text{kHz}$ and $f + 12\text{kHz}$) for OSD0
  and OSD1.

* **HALGpio:** Simulates the state of hardware control pins, including
  the Output Enable Bar (OEB), reset lines, and mode selection relays.

* **HALAudio:** Injects synthetic RF test vectors into the simulated
  mixing and ADC quantization stages, pushing the resulting 8-channel
  frames to the DSP callback.

* **HALTransport:** Binds the high-level command and data streams to a
  local Inter-Process Communication (IPC) transport—such as a POSIX
  domain socket or named pipe—acting as a direct stand-in for the
  physical USB endpoints.

---

## 3. Simulated Signal Pipeline

### 3.1 Synthetic RF Generation

Mathematical signal generators synthesize arbitrary RF test
environments. The engine supports complex carrier injection,
atmospheric noise (AWGN), QRN impulses, and modulated digital signals.

### 3.2 Mixer & ADC Behavioral Engine

* The synthetic RF input is downconverted by multiplying it against
  simulated 8-phase or 4-phase switching functions.

* This generates the 8 differential baseband audio channels while
  simulating analog phase and amplitude skews typical of the physical
  hardware.

### 3.3 Deterministic Sample Pacing

* The Twin acts as an unyielding data master, operating at precisely
  384ksps.

* A dedicated `SamplePacer` thread uses high-precision timers to push
  exactly 384 sample pairs every 1.0 ms into the virtual transport.

* This perfectly mimics the timing of the STM32's hardware DMA buffer
  intervals and forces the host software to perform host-side elastic
  buffering and dynamic time interpolation.

---
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

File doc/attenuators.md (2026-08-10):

# Attenuator T-Pad Values

In a T-pad topology, you use two identical **Series** resistors (R1,
R2) and one **Shunt** resistor (R3) to ground.

| Target Attenuation | Ideal Series | Ideal Shunt | Recommended E96 Series | Recommended E96 Shunt |
| --- | --- | --- | --- | --- |
| **3 dB** | $8.55\ \Omega$ | $141.93\ \Omega$ | **$8.66\ \Omega$** | **$143\ \Omega$** |
| **6 dB** | $16.61\ \Omega$ | $66.93\ \Omega$ | **$16.5\ \Omega$** | **$66.5\ \Omega$** |
| **12 dB** | $29.92\ \Omega$ | $26.81\ \Omega$ | **$30.1\ \Omega$** | **$26.7\ \Omega$** |
| **24 dB** | $44.06\ \Omega$ | $6.34\ \Omega$ | **$44.2\ \Omega$** | **$6.34\ \Omega$** |
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

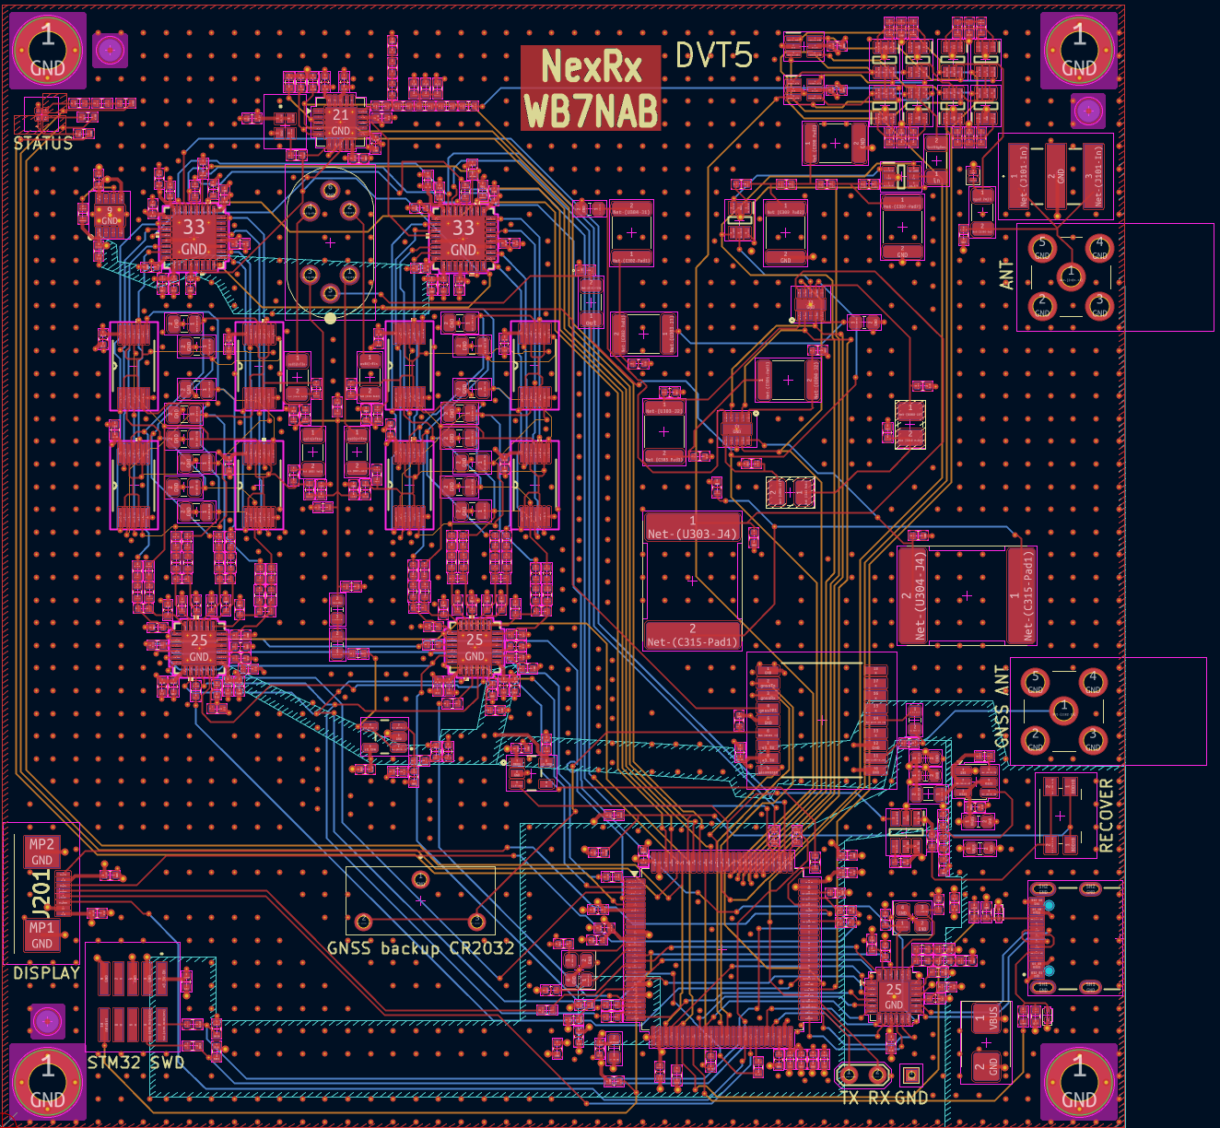
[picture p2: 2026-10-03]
doc/NexRxDVT5-PCB.png

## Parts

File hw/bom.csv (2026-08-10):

Reference | Value | Footprint | QUANTITY | LCSC | MPN | Description
BT101 | CR3032 holder | Library:S8401-46 | 1 | C5904513 | S8401-46 | Coin Cell Battery Retainer, Vertical Throughboard, for CR2032 and BR2032 Coin Cell Batteries
C101 | 100nF | Capacitor_SMD:C_1206_3216Metric | 1 |  | GRM3195C2A104JA01D | Capacitor, MLCC, NP0, 100V, 5%, 100nF, 1206
C102 | 100nF | Capacitor_SMD:C_1206_3216Metric | 1 |  | GRM3195C2A104JA01D | Capacitor, MLCC, NP0, 100V, 5%, 100nF, 1206
C103 | 100nF | Capacitor_SMD:C_1206_3216Metric | 1 |  | GRM3195C2A104JA01D | Capacitor, MLCC, NP0, 100V, 5%, 100nF, 1206
C104 | 10uF | Capacitor_SMD:C_0402_1005Metric | 1 | C479655 | CM105X5R106M25AT | Unpolarized capacitor
C105 | 10uF | Capacitor_SMD:C_0402_1005Metric | 1 | C479655 | CM105X5R106M25AT | Unpolarized capacitor
C106 | 150pF | Capacitor_SMD:C_0402_1005Metric | 1 |  |  | Unpolarized capacitor
C107 | 100nF | Capacitor_SMD:C_0402_1005Metric | 1 |  | C0805F104K1RACAUTO | Capacitor, MLCC, X7R, 50V, 5%, 100nF, 0603
C108 | 100nF | Capacitor_SMD:C_0402_1005Metric | 1 |  | C0805F104K1RACAUTO | Capacitor, MLCC, X7R, 50V, 5%, 100nF, 0603
C201 | 10uF | Capacitor_SMD:C_0402_1005Metric | 1 |  | 81-GXT155R71E223KE1D | Capacitor, MLCC, X7R, 25V, 10%, 10uF, 0603
C202 | 10uF | Capacitor_SMD:C_0402_1005Metric | 1 |  |  | Unpolarized capacitor
C203 | 10uF | Capacitor_SMD:C_0402_1005Metric | 1 |  | 81-GXT155R71E223KE1D | Capacitor, MLCC, X7R, 25V, 10%, 10uF, 0603
C204 | 27pF | Capacitor_SMD:C_0402_1005Metric | 1 |  |  | Capacitor, MLCC, NP0, 50V, 5%, 27pF, 0402
C205 | 27pF | Capacitor_SMD:C_0402_1005Metric | 1 |  |  | capacitor, small US symbol
C206 | 1uF | Capacitor_SMD:C_0402_1005Metric | 1 |  |  | Unpolarized capacitor
C207 | 100nF | Capacitor_SMD:C_0402_1005Metric | 1 |  | C0805F104K1RACAUTO | Capacitor, MLCC, X7R, 50V, 5%, 100nF, 0603
C208 | 100nF | Capacitor_SMD:C_0402_1005Metric | 1 |  | C0805F104K1RACAUTO | Capacitor, MLCC, X7R, 50V, 5%, 100nF, 0603
C209 | 1uF | Capacitor_SMD:C_0402_1005Metric | 1 |  |  | Unpolarized capacitor
C210 | 100nF | Capacitor_SMD:C_0402_1005Metric | 1 |  | C0805F104K1RACAUTO | Capacitor, MLCC, X7R, 50V, 5%, 100nF, 0603
C211 | 100nF | Capacitor_SMD:C_0402_1005Metric | 1 |  | C0805F104K1RACAUTO | Capacitor, MLCC, X7R, 50V, 5%, 100nF, 0603
C212 | 4.7uF | Capacitor_SMD:C_0402_1005Metric | 1 |  | 298D475X9010M2T | Capacitor, Tantalum, 10V, 10%, 4.7uF, 0805
C213 | 1uF | Capacitor_SMD:C_0402_1005Metric | 1 |  |  | Unpolarized capacitor
C214 | 1uF | Capacitor_SMD:C_0402_1005Metric | 1 |  |  | Unpolarized capacitor
C215 | 1uF | Capacitor_SMD:C_0402_1005Metric | 1 |  | GRM155R61E105KE11D | Capacitor, MLCC, X5R, 25V, 10%, 1uF, 0402
C216 | 100nF | Capacitor_SMD:C_0402_1005Metric | 1 |  |  | Unpolarized capacitor
C217 | 27pF | Capacitor_SMD:C_0402_1005Metric | 1 |  |  | capacitor, small US symbol
C218 | 27pF | Capacitor_SMD:C_0402_1005Metric | 1 |  |  | capacitor, small US symbol
C219 | 2.2uF | Capacitor_SMD:C_0402_1005Metric | 1 |  |  | Capacitor, MLCC, X7R, 50V, 10%, 2.2uF, 0603
C220 | 2.2uF | Capacitor_SMD:C_0402_1005Metric | 1 |  |  | Capacitor, MLCC, X7R, 50V, 10%, 2.2uF, 0603
C221 | 10uF | Capacitor_SMD:C_0402_1005Metric | 1 |  |  | Unpolarized capacitor
C222 | 10uF | Capacitor_SMD:C_0402_1005Metric | 1 |  |  | Unpolarized capacitor
C223 | 10uF | Capacitor_SMD:C_0402_1005Metric | 1 |  |  | Unpolarized capacitor
C224 | 10uF | Capacitor_SMD:C_0402_1005Metric | 1 |  |  | Unpolarized capacitor
C225 | 10uF | Capacitor_SMD:C_0402_1005Metric | 1 |  |  | Unpolarized capacitor
C226 | 1uF | Capacitor_SMD:C_0402_1005Metric | 1 |  | GRM155R61E105KE11D | Capacitor, MLCC, X5R, 25V, 10%, 1uF, 0402
C227 | 100nF | Capacitor_SMD:C_0402_1005Metric | 1 |  |  | Unpolarized capacitor
C228 | 100nF | Capacitor_SMD:C_0402_1005Metric | 1 |  |  | Unpolarized capacitor
C229 | 100nF | Capacitor_SMD:C_0402_1005Metric | 1 |  |  | Unpolarized capacitor
C230 | 100nF | Capacitor_SMD:C_0402_1005Metric | 1 |  |  | Unpolarized capacitor
C231 | 100nF | Capacitor_SMD:C_0402_1005Metric | 1 |  | C0805F104K1RACAUTO | Capacitor, MLCC, X7R, 50V, 5%, 100nF, 0603
C232 | 100nF | Capacitor_SMD:C_0402_1005Metric | 1 |  |  | Unpolarized capacitor
C233 | 100nF | Capacitor_SMD:C_0402_1005Metric | 1 |  |  | Unpolarized capacitor
C301 | 910pF | Capacitor_SMD:C_0402_1005Metric | 1 |  | C0402C132J5GACTU | capacitor, US symbol
C302 | 1.5nF | Capacitor_SMD:C_0402_1005Metric | 1 |  | C0402C202J3GACTU | capacitor, US symbol
C303 | 910pF | Capacitor_SMD:C_0402_1005Metric | 1 |  | C0402C132J5GACTU | capacitor, US symbol
C304 | 300pF | Capacitor_SMD:C_0402_1005Metric | 1 |  | C0402C132J5GACTU | capacitor, US symbol
C305 | 620pF | Capacitor_SMD:C_0402_1005Metric | 1 |  | C0402C202J3GACTU | capacitor, US symbol
C306 | 300pF | Capacitor_SMD:C_0402_1005Metric | 1 |  | C0402C132J5GACTU | capacitor, US symbol
C307 | 2.2nF | Capacitor_SMD:C_0402_1005Metric | 1 |  | GRM2165C1H162JA01D | capacitor, US symbol
C308 | 1nF | Capacitor_SMD:C_0402_1005Metric | 1 |  | 08051A911JAT2A | capacitor, US symbol
C309 | 1nF | Capacitor_SMD:C_0402_1005Metric | 1 |  | 08051A911JAT2A | capacitor, US symbol
C310 | 2.2nF | Capacitor_SMD:C_0402_1005Metric | 1 |  | GRM2165C1H162JA01D | capacitor, US symbol
C311 | 150pF | Capacitor_SMD:C_0402_1005Metric | 1 |  | C0402C132J5GACTU | capacitor, US symbol
C312 | 300pF | Capacitor_SMD:C_0402_1005Metric | 1 |  | C0402C202J3GACTU | capacitor, US symbol
C313 | 150pF | Capacitor_SMD:C_0402_1005Metric | 1 |  | C0402C132J5GACTU | capacitor, US symbol
C314 | 75pF | Capacitor_SMD:C_0402_1005Metric | 1 |  | C0402C132J5GACTU | capacitor, US symbol
C315 | 160pF | Capacitor_SMD:C_0402_1005Metric | 1 |  | C0402C202J3GACTU | capacitor, US symbol
C316 | 75pF | Capacitor_SMD:C_0402_1005Metric | 1 |  | C0402C132J5GACTU | capacitor, US symbol
C317 | 100nF | Capacitor_SMD:C_0402_1005Metric | 1 |  | C0805F104K1RACAUTO | Capacitor, MLCC, X7R, 50V, 5%, 100nF, 0603
C801 | 1uF | Capacitor_SMD:C_0402_1005Metric | 1 |  | GRM155R61E105KE11D | Capacitor, MLCC, X5R, 25V, 10%, 1uF, 0402
C802 | 100nF | Capacitor_SMD:C_0402_1005Metric | 1 |  | C0805F104K1RACAUTO | Capacitor, MLCC, X7R, 50V, 5%, 100nF, 0603
C803 | 100nF | Capacitor_SMD:C_0402_1005Metric | 1 |  | C0805F104K1RACAUTO | Capacitor, MLCC, X7R, 50V, 5%, 100nF, 0603
C804 | 100nF | Capacitor_SMD:C_0402_1005Metric | 1 |  | C0805F104K1RACAUTO | Capacitor, MLCC, X7R, 50V, 5%, 100nF, 0603
C805 | 10uF | Capacitor_SMD:C_0402_1005Metric | 1 |  | TAJD106K050RNJ | Capacitor, Tantalum, 50V, 10%, 10uF, 0805
C806 | 4.7uF | Capacitor_SMD:C_0402_1005Metric | 1 |  |  | Capacitor, MLCC, X5R, 25V, 5%, 0402
C807 | 2.2nF | Capacitor_SMD:C_0402_1005Metric | 1 |  |  | Capacitor, MLCC, NP0, 25V, 5%, 0603
C808 | 10uF | Capacitor_SMD:C_0402_1005Metric | 1 |  | TAJD106K050RNJ | Capacitor, Tantalum, 50V, 10%, 10uF, 0805
C809 | 100nF | Capacitor_SMD:C_0402_1005Metric | 1 |  | C0805F104K1RACAUTO | Capacitor, MLCC, X7R, 50V, 5%, 100nF, 0603
C810 | 4.7uF | Capacitor_SMD:C_0402_1005Metric | 1 |  |  | Capacitor, MLCC, X5R, 25V, 5%, 0402
C811 | 100nF | Capacitor_SMD:C_0402_1005Metric | 1 |  | C0805F104K1RACAUTO | Capacitor, MLCC, X7R, 50V, 5%, 100nF, 0603
C812 | 10uF | Capacitor_SMD:C_0402_1005Metric | 1 |  | TAJD106K050RNJ | Capacitor, Tantalum, 50V, 10%, 10uF, 0805
C813 | 150pF | Capacitor_SMD:C_0402_1005Metric | 1 |  | 06033A151FAT2A | Capacitor, MLCC, NP0, 50V, 5%, 150pF, 0603
C814 | 150pF | Capacitor_SMD:C_0402_1005Metric | 1 |  | 06033A151FAT2A | Capacitor, MLCC, NP0, 50V, 5%, 150pF, 0603
C815 | 8nF 1% | Capacitor_SMD:C_0805_2012Metric | 1 |  |  | Unpolarized capacitor
C816 | 1uF | Capacitor_SMD:C_0402_1005Metric | 1 |  | GRM155R61E105KE11D | Capacitor, MLCC, X5R, 25V, 10%, 1uF, 0402
C817 | 8nF 1% | Capacitor_SMD:C_0805_2012Metric | 1 |  |  | Unpolarized capacitor
C818 | 100nF | Capacitor_SMD:C_0402_1005Metric | 1 |  | C0805F104K1RACAUTO | Capacitor, MLCC, X7R, 50V, 5%, 100nF, 0603
C819 | 4.7uF | Capacitor_SMD:C_0402_1005Metric | 1 |  |  | Capacitor, MLCC, X5R, 25V, 5%, 0402
C820 | 8nF 1% | Capacitor_SMD:C_0805_2012Metric | 1 |  |  | Unpolarized capacitor
C821 | 2.2nF | Capacitor_SMD:C_0402_1005Metric | 1 |  |  | Capacitor, MLCC, NP0, 25V, 5%, 0603
C822 | 100nF | Capacitor_SMD:C_0402_1005Metric | 1 |  | C0805F104K1RACAUTO | Capacitor, MLCC, X7R, 50V, 5%, 100nF, 0603
C823 | 8nF 1% | Capacitor_SMD:C_0805_2012Metric | 1 |  |  | Unpolarized capacitor
C824 | 4.7uF | Capacitor_SMD:C_0402_1005Metric | 1 |  |  | Capacitor, MLCC, X5R, 25V, 5%, 0402
C825 | 100nF | Capacitor_SMD:C_1206_3216Metric | 1 |  | GRM3195C2A104JA01D | Capacitor, MLCC, NP0, 100V, 5%, 100nF, 1206
C826 | 8nF 1% | Capacitor_SMD:C_0805_2012Metric | 1 |  |  | Unpolarized capacitor
C827 | 150pF | Capacitor_SMD:C_0402_1005Metric | 1 |  | 06033A151FAT2A | Capacitor, MLCC, NP0, 50V, 5%, 150pF, 0603
C828 | 150pF | Capacitor_SMD:C_0402_1005Metric | 1 |  | 06033A151FAT2A | Capacitor, MLCC, NP0, 50V, 5%, 150pF, 0603
C829 | 8nF 1% | Capacitor_SMD:C_0805_2012Metric | 1 |  |  | Unpolarized capacitor
C830 | 8nF 1% | Capacitor_SMD:C_0805_2012Metric | 1 |  |  | Unpolarized capacitor
C831 | 4.7uF | Capacitor_SMD:C_0402_1005Metric | 1 |  |  | Capacitor, MLCC, X5R, 25V, 5%, 0402
C832 | 8nF 1% | Capacitor_SMD:C_0805_2012Metric | 1 |  |  | Unpolarized capacitor
C833 | 2.2nF | Capacitor_SMD:C_0402_1005Metric | 1 |  |  | Capacitor, MLCC, NP0, 25V, 5%, 0603
C834 | 4.7uF | Capacitor_SMD:C_0402_1005Metric | 1 |  |  | Capacitor, MLCC, X5R, 25V, 5%, 0402
C835 | 150pF | Capacitor_SMD:C_0402_1005Metric | 1 |  | 06033A151FAT2A | Capacitor, MLCC, NP0, 50V, 5%, 150pF, 0603
C836 | 150pF | Capacitor_SMD:C_0402_1005Metric | 1 |  | 06033A151FAT2A | Capacitor, MLCC, NP0, 50V, 5%, 150pF, 0603
C837 | 100nF | Capacitor_SMD:C_0402_1005Metric | 1 |  | C0805F104K1RACAUTO | Capacitor, MLCC, X7R, 50V, 5%, 100nF, 0603
C838 | 4.7uF | Capacitor_SMD:C_0402_1005Metric | 1 |  |  | Capacitor, MLCC, X5R, 25V, 5%, 0402
C839 | 2.2nF | Capacitor_SMD:C_0402_1005Metric | 1 |  |  | Capacitor, MLCC, NP0, 25V, 5%, 0603
C840 | 4.7uF | Capacitor_SMD:C_0402_1005Metric | 1 |  |  | Capacitor, MLCC, X5R, 25V, 5%, 0402
C841 | 150pF | Capacitor_SMD:C_0402_1005Metric | 1 |  | 06033A151FAT2A | Capacitor, MLCC, NP0, 50V, 5%, 150pF, 0603
C842 | 150pF | Capacitor_SMD:C_0402_1005Metric | 1 |  | 06033A151FAT2A | Capacitor, MLCC, NP0, 50V, 5%, 150pF, 0603
C843 | 100nF | Capacitor_SMD:C_0402_1005Metric | 1 |  | C0805F104K1RACAUTO | Capacitor, MLCC, X7R, 50V, 5%, 100nF, 0603
C844 | 100nF | Capacitor_SMD:C_0402_1005Metric | 1 |  | C0805F104K1RACAUTO | Capacitor, MLCC, X7R, 50V, 5%, 100nF, 0603
C845 | 100nF | Capacitor_SMD:C_1206_3216Metric | 1 |  | GRM3195C2A104JA01D | Capacitor, MLCC, NP0, 100V, 5%, 100nF, 1206
C901 | 1uF | Capacitor_SMD:C_0402_1005Metric | 1 |  | GRM155R61E105KE11D | Capacitor, MLCC, X5R, 25V, 10%, 1uF, 0402
C902 | 100nF | Capacitor_SMD:C_0402_1005Metric | 1 |  | C0805F104K1RACAUTO | Capacitor, MLCC, X7R, 50V, 5%, 100nF, 0603
C903 | 100nF | Capacitor_SMD:C_0402_1005Metric | 1 |  | C0805F104K1RACAUTO | Capacitor, MLCC, X7R, 50V, 5%, 100nF, 0603
C904 | 100nF | Capacitor_SMD:C_0402_1005Metric | 1 |  | C0805F104K1RACAUTO | Capacitor, MLCC, X7R, 50V, 5%, 100nF, 0603
C905 | 10uF | Capacitor_SMD:C_0402_1005Metric | 1 |  | TAJD106K050RNJ | Capacitor, Tantalum, 50V, 10%, 10uF, 0805
C906 | 4.7uF | Capacitor_SMD:C_0402_1005Metric | 1 |  |  | Capacitor, MLCC, X5R, 25V, 5%, 0402
C907 | 2.2nF | Capacitor_SMD:C_0402_1005Metric | 1 |  |  | Capacitor, MLCC, NP0, 25V, 5%, 0603
C908 | 10uF | Capacitor_SMD:C_0402_1005Metric | 1 |  | TAJD106K050RNJ | Capacitor, Tantalum, 50V, 10%, 10uF, 0805
C909 | 100nF | Capacitor_SMD:C_0402_1005Metric | 1 |  | C0805F104K1RACAUTO | Capacitor, MLCC, X7R, 50V, 5%, 100nF, 0603
C910 | 4.7uF | Capacitor_SMD:C_0402_1005Metric | 1 |  |  | Capacitor, MLCC, X5R, 25V, 5%, 0402
C911 | 100nF | Capacitor_SMD:C_0402_1005Metric | 1 |  | C0805F104K1RACAUTO | Capacitor, MLCC, X7R, 50V, 5%, 100nF, 0603
C912 | 10uF | Capacitor_SMD:C_0402_1005Metric | 1 |  | TAJD106K050RNJ | Capacitor, Tantalum, 50V, 10%, 10uF, 0805
C913 | 150pF | Capacitor_SMD:C_0402_1005Metric | 1 |  | 06033A151FAT2A | Capacitor, MLCC, NP0, 50V, 5%, 150pF, 0603
C914 | 150pF | Capacitor_SMD:C_0402_1005Metric | 1 |  | 06033A151FAT2A | Capacitor, MLCC, NP0, 50V, 5%, 150pF, 0603
C915 | 8nF 1% | Capacitor_SMD:C_0805_2012Metric | 1 |  |  | Unpolarized capacitor
C916 | 1uF | Capacitor_SMD:C_0402_1005Metric | 1 |  | GRM155R61E105KE11D | Capacitor, MLCC, X5R, 25V, 10%, 1uF, 0402
C917 | 8nF 1% | Capacitor_SMD:C_0805_2012Metric | 1 |  |  | Unpolarized capacitor
C918 | 100nF | Capacitor_SMD:C_0402_1005Metric | 1 |  | C0805F104K1RACAUTO | Capacitor, MLCC, X7R, 50V, 5%, 100nF, 0603
C919 | 4.7uF | Capacitor_SMD:C_0402_1005Metric | 1 |  |  | Capacitor, MLCC, X5R, 25V, 5%, 0402
C920 | 8nF 1% | Capacitor_SMD:C_0805_2012Metric | 1 |  |  | Unpolarized capacitor
C921 | 2.2nF | Capacitor_SMD:C_0402_1005Metric | 1 |  |  | Capacitor, MLCC, NP0, 25V, 5%, 0603
C922 | 100nF | Capacitor_SMD:C_0402_1005Metric | 1 |  | C0805F104K1RACAUTO | Capacitor, MLCC, X7R, 50V, 5%, 100nF, 0603
C923 | 8nF 1% | Capacitor_SMD:C_0805_2012Metric | 1 |  |  | Unpolarized capacitor
C924 | 4.7uF | Capacitor_SMD:C_0402_1005Metric | 1 |  |  | Capacitor, MLCC, X5R, 25V, 5%, 0402
C925 | 100nF | Capacitor_SMD:C_1206_3216Metric | 1 |  | GRM3195C2A104JA01D | Capacitor, MLCC, NP0, 100V, 5%, 100nF, 1206
C926 | 8nF 1% | Capacitor_SMD:C_0805_2012Metric | 1 |  |  | Unpolarized capacitor
C927 | 150pF | Capacitor_SMD:C_0402_1005Metric | 1 |  | 06033A151FAT2A | Capacitor, MLCC, NP0, 50V, 5%, 150pF, 0603
C928 | 150pF | Capacitor_SMD:C_0402_1005Metric | 1 |  | 06033A151FAT2A | Capacitor, MLCC, NP0, 50V, 5%, 150pF, 0603
C929 | 8nF 1% | Capacitor_SMD:C_0805_2012Metric | 1 |  |  | Unpolarized capacitor
C930 | 8nF 1% | Capacitor_SMD:C_0805_2012Metric | 1 |  |  | Unpolarized capacitor
C931 | 4.7uF | Capacitor_SMD:C_0402_1005Metric | 1 |  |  | Capacitor, MLCC, X5R, 25V, 5%, 0402
C932 | 8nF 1% | Capacitor_SMD:C_0805_2012Metric | 1 |  |  | Unpolarized capacitor
C933 | 2.2nF | Capacitor_SMD:C_0402_1005Metric | 1 |  |  | Capacitor, MLCC, NP0, 25V, 5%, 0603
C934 | 4.7uF | Capacitor_SMD:C_0402_1005Metric | 1 |  |  | Capacitor, MLCC, X5R, 25V, 5%, 0402
C935 | 150pF | Capacitor_SMD:C_0402_1005Metric | 1 |  | 06033A151FAT2A | Capacitor, MLCC, NP0, 50V, 5%, 150pF, 0603
C936 | 150pF | Capacitor_SMD:C_0402_1005Metric | 1 |  | 06033A151FAT2A | Capacitor, MLCC, NP0, 50V, 5%, 150pF, 0603
C937 | 100nF | Capacitor_SMD:C_0402_1005Metric | 1 |  | C0805F104K1RACAUTO | Capacitor, MLCC, X7R, 50V, 5%, 100nF, 0603
C938 | 4.7uF | Capacitor_SMD:C_0402_1005Metric | 1 |  |  | Capacitor, MLCC, X5R, 25V, 5%, 0402
C939 | 2.2nF | Capacitor_SMD:C_0402_1005Metric | 1 |  |  | Capacitor, MLCC, NP0, 25V, 5%, 0603
C940 | 4.7uF | Capacitor_SMD:C_0402_1005Metric | 1 |  |  | Capacitor, MLCC, X5R, 25V, 5%, 0402
C941 | 150pF | Capacitor_SMD:C_0402_1005Metric | 1 |  | 06033A151FAT2A | Capacitor, MLCC, NP0, 50V, 5%, 150pF, 0603
C942 | 150pF | Capacitor_SMD:C_0402_1005Metric | 1 |  | 06033A151FAT2A | Capacitor, MLCC, NP0, 50V, 5%, 150pF, 0603
C943 | 100nF | Capacitor_SMD:C_0402_1005Metric | 1 |  | C0805F104K1RACAUTO | Capacitor, MLCC, X7R, 50V, 5%, 100nF, 0603
C944 | 100nF | Capacitor_SMD:C_0402_1005Metric | 1 |  | C0805F104K1RACAUTO | Capacitor, MLCC, X7R, 50V, 5%, 100nF, 0603
C945 | 100nF | Capacitor_SMD:C_1206_3216Metric | 1 |  | GRM3195C2A104JA01D | Capacitor, MLCC, NP0, 100V, 5%, 100nF, 1206
C1001 | 4.7uF | Capacitor_SMD:C_0402_1005Metric | 1 |  | 298D475X9010M2T | Capacitor, Tantalum, 10V, 10%, 4.7uF, 0805
C1002 | 4.7uF | Capacitor_SMD:C_0402_1005Metric | 1 |  | 298D475X9010M2T | Capacitor, Tantalum, 10V, 10%, 4.7uF, 0805
C1003 | 100nF | Capacitor_SMD:C_0402_1005Metric | 1 |  | C0805F104K1RACAUTO | Capacitor, MLCC, X7R, 50V, 5%, 100nF, 0603
C1004 | 100nF | Capacitor_SMD:C_0402_1005Metric | 1 |  | C0805F104K1RACAUTO | Capacitor, MLCC, X7R, 50V, 5%, 100nF, 0603
C1005 | 100nF | Capacitor_SMD:C_0402_1005Metric | 1 |  | C0805F104K1RACAUTO | Capacitor, MLCC, X7R, 50V, 5%, 100nF, 0603
C1006 | 100nF | Capacitor_SMD:C_0402_1005Metric | 1 |  | C0805F104K1RACAUTO | Capacitor, MLCC, X7R, 50V, 5%, 100nF, 0603
C1007 | 100nF | Capacitor_SMD:C_0402_1005Metric | 1 |  | C0805F104K1RACAUTO | Capacitor, MLCC, X7R, 50V, 5%, 100nF, 0603
C1008 | 100nF | Capacitor_SMD:C_0402_1005Metric | 1 |  | C0805F104K1RACAUTO | Capacitor, MLCC, X7R, 50V, 5%, 100nF, 0603
C1009 | 100nF | Capacitor_SMD:C_0402_1005Metric | 1 |  | C0805F104K1RACAUTO | Capacitor, MLCC, X7R, 50V, 5%, 100nF, 0603
C1201 | 100nF | Capacitor_SMD:C_0402_1005Metric | 1 |  | C0805F104K1RACAUTO | Capacitor, MLCC, X7R, 50V, 5%, 100nF, 0603
C1202 | 100nF | Capacitor_SMD:C_0402_1005Metric | 1 |  | C0805F104K1RACAUTO | Capacitor, MLCC, X7R, 50V, 5%, 100nF, 0603
C1203 | 100nF | Capacitor_SMD:C_0402_1005Metric | 1 |  | C0805F104K1RACAUTO | Capacitor, MLCC, X7R, 50V, 5%, 100nF, 0603
C1204 | 100nF | Capacitor_SMD:C_0402_1005Metric | 1 |  | C0805F104K1RACAUTO | Capacitor, MLCC, X7R, 50V, 5%, 100nF, 0603
C1205 | 100nF | Capacitor_SMD:C_0402_1005Metric | 1 |  | C0805F104K1RACAUTO | Capacitor, MLCC, X7R, 50V, 5%, 100nF, 0603
C1206 | 100nF | Capacitor_SMD:C_0402_1005Metric | 1 |  | C0805F104K1RACAUTO | Capacitor, MLCC, X7R, 50V, 5%, 100nF, 0603
C1207 | 27pF | Capacitor_SMD:C_0402_1005Metric | 1 |  |  | capacitor, small US symbol
C1208 | 27pF | Capacitor_SMD:C_0402_1005Metric | 1 |  |  | capacitor, small US symbol
C1209 | 27pF | Capacitor_SMD:C_0402_1005Metric | 1 |  |  | capacitor, small US symbol
C1401 | 4.7uF | Capacitor_SMD:C_0402_1005Metric | 1 |  | 298D475X9010M2T | Capacitor, Tantalum, 10V, 10%, 4.7uF, 0805
C1402 | 4.7uF | Capacitor_SMD:C_0402_1005Metric | 1 |  | 298D475X9010M2T | Capacitor, Tantalum, 10V, 10%, 4.7uF, 0805
C1403 | 100nF | Capacitor_SMD:C_0402_1005Metric | 1 |  | C0805F104K1RACAUTO | Capacitor, MLCC, X7R, 50V, 5%, 100nF, 0603
C1404 | 100nF | Capacitor_SMD:C_0402_1005Metric | 1 |  | C0805F104K1RACAUTO | Capacitor, MLCC, X7R, 50V, 5%, 100nF, 0603
C1405 | 100nF | Capacitor_SMD:C_0402_1005Metric | 1 |  | C0805F104K1RACAUTO | Capacitor, MLCC, X7R, 50V, 5%, 100nF, 0603
C1406 | 100nF | Capacitor_SMD:C_0402_1005Metric | 1 |  | C0805F104K1RACAUTO | Capacitor, MLCC, X7R, 50V, 5%, 100nF, 0603
C1407 | 100nF | Capacitor_SMD:C_0402_1005Metric | 1 |  | C0805F104K1RACAUTO | Capacitor, MLCC, X7R, 50V, 5%, 100nF, 0603
C1408 | 100nF | Capacitor_SMD:C_0402_1005Metric | 1 |  | C0805F104K1RACAUTO | Capacitor, MLCC, X7R, 50V, 5%, 100nF, 0603
C1409 | 100nF | Capacitor_SMD:C_0402_1005Metric | 1 |  | C0805F104K1RACAUTO | Capacitor, MLCC, X7R, 50V, 5%, 100nF, 0603
C1501 | 100nF | Capacitor_SMD:C_0402_1005Metric | 1 |  | C0805F104K1RACAUTO | Capacitor, MLCC, X7R, 50V, 5%, 100nF, 0603
C1502 | 10uF | Capacitor_SMD:C_0603_1608Metric | 1 |  | 81-GXT155R71E223KE1D | Capacitor, MLCC, X7R, 25V, 10%, 10uF, 0603
C1503 | 1uF | Capacitor_SMD:C_0402_1005Metric | 1 |  | GRM155R61E105KE11D | Capacitor, MLCC, X5R, 25V, 10%, 1uF, 0402
C1504 | 1uF | Capacitor_SMD:C_0402_1005Metric | 1 |  |  | Unpolarized capacitor
C1505 | 1uF | Capacitor_SMD:C_0402_1005Metric | 1 |  | GRM155R61E105KE11D | Capacitor, MLCC, X5R, 25V, 10%, 1uF, 0402
C1506 | 10uF | Capacitor_SMD:C_0603_1608Metric | 1 |  |  | Unpolarized capacitor
C1507 | 10uF | Capacitor_SMD:C_0603_1608Metric | 1 |  |  | Unpolarized capacitor
C1508 | 200pF | Capacitor_SMD:C_0402_1005Metric | 1 |  | C1608C0G1H221F080AA | Capacitor, MLCC, NP0, 50V, 5%, 220pF, 0603
C1509 | 1uF | Capacitor_SMD:C_0402_1005Metric | 1 |  |  | Unpolarized capacitor
C1510 | 1uF | Capacitor_SMD:C_0402_1005Metric | 1 |  |  | Unpolarized capacitor
C1511 | 100nF | Capacitor_SMD:C_0402_1005Metric | 1 |  | C0805F104K1RACAUTO | Capacitor, MLCC, X7R, 50V, 5%, 100nF, 0603
C1512 | 2.2uF | Capacitor_SMD:C_0402_1005Metric | 1 |  | TMCP1D225MTR2F | Capacitor, Tantalum, 50V, 10%, 2.2uF, CP_EIA-3528-21_Kemet-B
C1513 | 10nF | Capacitor_SMD:C_0402_1005Metric | 1 |  | C0805F104K1RACAUTO | Capacitor, MLCC, X7R, 50V, 5%, 100nF, 0603
C1514 | 10nF | Capacitor_SMD:C_0402_1005Metric | 1 |  | GCM1885C2A103JE02J | Capacitor, MLCC, X7R, 25V, 5%, 10nF, 0603
C1515 | 2.2uF | Capacitor_SMD:C_0402_1005Metric | 1 |  | TMCP1D225MTR2F | Capacitor, Tantalum, 50V, 10%, 2.2uF, CP_EIA-3528-21_Kemet-B
C1516 | 10nF | Capacitor_SMD:C_0402_1005Metric | 1 |  | GCM1885C2A103JE02J | Capacitor, MLCC, X7R, 25V, 5%, 10nF, 0603
C1517 | 10uF | Capacitor_SMD:C_0603_1608Metric | 1 |  | 81-GXT155R71E223KE1D | Capacitor, MLCC, X7R, 25V, 10%, 10uF, 0603
D101 | TPD1E0B04DPY | Diode_SMD:D_SOD-882 | 1 |  |  | 0.13-pF, ±3.6-V, ±8-kV ESD protection diode in 0402 & 0201 packages for USB-C & Antenna
D102 | SP0402B-ELC-01ETG | Diode_SMD:D_0402_1005Metric | 1 |  | SP0402B-ELC-01ETG | ESD Suppressor Diode TVS Bi-Dir 7V 2-Pin DFN T/R
D201 | LED_BGRA | Library:UHD111AFKAC3K23E1L3VG5ZB3Z3 | 1 |  | UHD111A-FKA-C3K23E1L3VG5ZB3Z3 | RGB LED, blue/green/red/anode
D1501 | SMBJ15A | Diode_SMD:D_SMB | 1 |  | SMBJ15A | 600W 14V transient protection zener diode
D1502 | ESD9B5.0ST5G | Diode_SMD:D_SOD-923 | 1 |  |  | ESD protection diode, 5.0Vrwm, SOD-923
D1503 | ESD9B5.0ST5G | Diode_SMD:D_SOD-923 | 1 |  |  | ESD protection diode, 5.0Vrwm, SOD-923
FB201 | 600 | Inductor_SMD:L_0603_1608Metric | 1 |  | MI0603J601R-10 | Ferrite bead, small symbol,TDK KPZ1608SHR601ATD25 600 ohm ferrite bead 1A
FB1501 | 600 | Inductor_SMD:L_0603_1608Metric | 1 |  | MI0603J601R-10 | Ferrite bead, small symbol,TDK KPZ1608SHR601ATD25 600 ohm ferrite bead 1A
GD101 | 350V | Library:GDT3535S1RP | 1 |  | GDT35-35-S1-RP | Gas Discharge Tube with 3 Pins
J101 | SMA | Library:733910083 | 1 |  | 733910083 | coaxial connector (BNC, SMA, SMB, SMC, Cinch/RCA, LEMO, ...)
J102 | SMA | Library:733910083 | 1 |  | 733910083 | coaxial connector (BNC, SMA, SMB, SMC, Cinch/RCA, LEMO, ...)
J201 | 68710814022 | Library:68710814022 | 1 |  | 5034800800 | Wurth Elektronik 687 Series 0.5mm 8 Way 1 Row Straight PCB Socket Surface Mount Wire to Board
J202 | FTSH-105-01-L-DV-K | Library:FTSH10501LDVK | 1 |  |  | Cortex Debug Connector, standard ARM Cortex-M SWD and JTAG interface SamTec FTSH-105-01-L-DV-K
J1501 | pwr+data | Library:USB_C_Receptacle_HRO_TYPE-C-31-M-12-bursted | 1 |  | TYPE-C-31-M-12 | USB 2.0-only 16P Type-C Receptacle connector
L101 | 47nH | Inductor_SMD:L_0603_1608Metric | 1 | C98076 | AIMC-0603-47NJ-T | Inductor with ferrite core, small symbol
L1501 | 2.2uH | Inductor_SMD:L_0805_2012Metric | 1 |  |  | Inductor, small symbol
L1502 | 1.5uH | Inductor_SMD:L_1210_3225Metric | 1 |  | NLV32T-1R5J-EF | Inductor with ferrite core, small symbol
R101 | 100k | Resistor_SMD:R_0402_1005Metric | 1 |  | ERJ-P08J104V | Resistor, Thin Film, 0.1%, 100k, 0603
R201 | 10k | Resistor_SMD:R_0402_1005Metric | 1 |  |  | Resistor, Thin Film, 0.1%, 10k, 0402
R202 | 22 | Resistor_SMD:R_0402_1005Metric | 1 |  |  | Resistor, Thin Film, 0.1%, 22, 0402
R203 | 22 | Resistor_SMD:R_0402_1005Metric | 1 |  |  | Resistor, Thin Film, 0.1%, 22, 0402
R204 | 10k | Resistor_SMD:R_0402_1005Metric | 1 |  |  | Resistor, Thin Film, 0.1%, 10k, 0402
R205 | 10k | Resistor_SMD:R_0402_1005Metric | 1 |  |  | Resistor, Thin Film, 0.1%, 10k, 0402
R206 | 22 | Resistor_SMD:R_0402_1005Metric | 1 |  |  | Resistor, small US symbol
R207 | 22 | Resistor_SMD:R_0402_1005Metric | 1 |  |  | Resistor, small US symbol
R208 | 22 | Resistor_SMD:R_0402_1005Metric | 1 |  |  | Resistor, small US symbol
R209 | 100 | Resistor_SMD:R_0402_1005Metric | 1 |  |  | Resistor, small US symbol
R210 | 100 | Resistor_SMD:R_0402_1005Metric | 1 |  |  | Resistor, small US symbol
R211 | 100 | Resistor_SMD:R_0402_1005Metric | 1 |  |  | Resistor, small US symbol
R212 | 22 | Resistor_SMD:R_0402_1005Metric | 1 |  |  | Resistor, small US symbol
R213 | 22 | Resistor_SMD:R_0402_1005Metric | 1 |  |  | Resistor, small US symbol
R214 | 100 | Resistor_SMD:R_0402_1005Metric | 1 |  |  | Resistor, small US symbol
R215 | 100 | Resistor_SMD:R_0402_1005Metric | 1 |  |  | Resistor, small US symbol
R216 | 22 | Resistor_SMD:R_0402_1005Metric | 1 |  |  | Resistor, small US symbol
R217 | 22 | Resistor_SMD:R_0402_1005Metric | 1 |  |  | Resistor, small US symbol
R218 | 22.1k | Resistor_SMD:R_0402_1005Metric | 1 |  |  | Resistor, Thin Film, 0.1%, 22.1k, 0402
R219 | 22 | Resistor_SMD:R_0402_1005Metric | 1 |  |  | Resistor, small US symbol
R220 | 22 | Resistor_SMD:R_0402_1005Metric | 1 |  |  | Resistor, small US symbol
R221 | 8.06k | Resistor_SMD:R_0402_1005Metric | 1 |  |  | Resistor, Thin Film, 0.1%, 8.06k, 0603
R222 | 330 | Resistor_SMD:R_0402_1005Metric | 1 |  |  | Resistor, Thin Film, 0.1%, 10k, 0402
R223 | 5.1k | Resistor_SMD:R_0402_1005Metric | 1 |  |  | Resistor, Thin Film, 0.1%, 5.1k, 0603
R224 | 5.1k | Resistor_SMD:R_0402_1005Metric | 1 |  |  | Resistor, Thin Film, 0.1%, 5.1k, 0603
R225 | 10k | Resistor_SMD:R_0402_1005Metric | 1 |  |  | Resistor, Thin Film, 0.1%, 10k, 0402
R401 | 34.4 | Resistor_SMD:R_0402_1005Metric | 1 |  |  | Resistor, Thin Film, 0.1%, 34.4, 0402
R402 | 34.4 | Resistor_SMD:R_0402_1005Metric | 1 |  |  | Resistor, Thin Film, 0.1%, 34.4, 0402
R403 | 562 | Resistor_SMD:R_0402_1005Metric | 1 |  |  | Resistor, Thin Film, 0.1%, 562, 0402
R501 | 34.4 | Resistor_SMD:R_0402_1005Metric | 1 |  |  | Resistor, Thin Film, 0.1%, 34.4, 0402
R502 | 34.4 | Resistor_SMD:R_0402_1005Metric | 1 |  |  | Resistor, Thin Film, 0.1%, 34.4, 0402
R503 | 562 | Resistor_SMD:R_0402_1005Metric | 1 |  |  | Resistor, Thin Film, 0.1%, 562, 0402
R601 | 34.4 | Resistor_SMD:R_0402_1005Metric | 1 |  |  | Resistor, Thin Film, 0.1%, 34.4, 0402
R602 | 34.4 | Resistor_SMD:R_0402_1005Metric | 1 |  |  | Resistor, Thin Film, 0.1%, 34.4, 0402
R603 | 562 | Resistor_SMD:R_0402_1005Metric | 1 |  |  | Resistor, Thin Film, 0.1%, 562, 0402
R701 | 34.4 | Resistor_SMD:R_0402_1005Metric | 1 |  |  | Resistor, Thin Film, 0.1%, 34.4, 0402
R702 | 34.4 | Resistor_SMD:R_0402_1005Metric | 1 |  |  | Resistor, Thin Film, 0.1%, 34.4, 0402
R703 | 562 | Resistor_SMD:R_0402_1005Metric | 1 |  |  | Resistor, Thin Film, 0.1%, 562, 0402
R801 | 100 | Resistor_SMD:R_0402_1005Metric | 1 |  |  | Resistor, Thin Film, 0.1%, 100, 0402
R802 | 100 | Resistor_SMD:R_0402_1005Metric | 1 |  |  | Resistor, Thin Film, 0.1%, 100, 0402
R803 | 10k | Resistor_SMD:R_0402_1005Metric | 1 |  |  | Resistor, Thin Film, 0.1%, 10k, 0402
R804 | 100 | Resistor_SMD:R_0402_1005Metric | 1 |  |  | Resistor, Thin Film, 0.1%, 100, 0402
R805 | 100 | Resistor_SMD:R_0402_1005Metric | 1 |  |  | Resistor, Thin Film, 0.1%, 100, 0402
R806 | 22 | Resistor_SMD:R_0402_1005Metric | 1 |  |  | Resistor, small US symbol
R807 | 10 | Resistor_SMD:R_0402_1005Metric | 1 |  |  | Resistor, Thin Film, 0.1%, 10 ohm, 0402
R808 | 22 | Resistor_SMD:R_0402_1005Metric | 1 |  |  | Resistor, small US symbol
R809 | 100 | Resistor_SMD:R_0402_1005Metric | 1 |  |  | Resistor, Thin Film, 0.1%, 100, 0402
R810 | 100 | Resistor_SMD:R_0402_1005Metric | 1 |  |  | Resistor, Thin Film, 0.1%, 100, 0402
R811 | 100 | Resistor_SMD:R_0402_1005Metric | 1 |  |  | Resistor, Thin Film, 0.1%, 100, 0402
R812 | 100 | Resistor_SMD:R_0402_1005Metric | 1 |  |  | Resistor, Thin Film, 0.1%, 100, 0402
R813 | 10k | Resistor_SMD:R_0402_1005Metric | 1 |  |  | Resistor, Thin Film, 0.1%, 10k, 0402
R814 | 10 | Resistor_SMD:R_0402_1005Metric | 1 |  |  | Resistor, Thin Film, 0.1%, 10 ohm, 0402
R901 | 100 | Resistor_SMD:R_0402_1005Metric | 1 |  |  | Resistor, Thin Film, 0.1%, 100, 0402
R902 | 100 | Resistor_SMD:R_0402_1005Metric | 1 |  |  | Resistor, Thin Film, 0.1%, 100, 0402
R903 | 10k | Resistor_SMD:R_0402_1005Metric | 1 |  |  | Resistor, Thin Film, 0.1%, 10k, 0402
R904 | 100 | Resistor_SMD:R_0402_1005Metric | 1 |  |  | Resistor, Thin Film, 0.1%, 100, 0402
R905 | 100 | Resistor_SMD:R_0402_1005Metric | 1 |  |  | Resistor, Thin Film, 0.1%, 100, 0402
R906 | 22 | Resistor_SMD:R_0402_1005Metric | 1 |  |  | Resistor, small US symbol
R907 | 10 | Resistor_SMD:R_0402_1005Metric | 1 |  |  | Resistor, Thin Film, 0.1%, 10 ohm, 0402
R908 | 22 | Resistor_SMD:R_0402_1005Metric | 1 |  |  | Resistor, small US symbol
R909 | 100 | Resistor_SMD:R_0402_1005Metric | 1 |  |  | Resistor, Thin Film, 0.1%, 100, 0402
R910 | 100 | Resistor_SMD:R_0402_1005Metric | 1 |  |  | Resistor, Thin Film, 0.1%, 100, 0402
R911 | 100 | Resistor_SMD:R_0402_1005Metric | 1 |  |  | Resistor, Thin Film, 0.1%, 100, 0402
R912 | 100 | Resistor_SMD:R_0402_1005Metric | 1 |  |  | Resistor, Thin Film, 0.1%, 100, 0402
R913 | 10k | Resistor_SMD:R_0402_1005Metric | 1 |  |  | Resistor, Thin Film, 0.1%, 10k, 0402
R914 | 10 | Resistor_SMD:R_0402_1005Metric | 1 |  |  | Resistor, Thin Film, 0.1%, 10 ohm, 0402
R1001 | 22.1k | Resistor_SMD:R_0402_1005Metric | 1 |  |  | Resistor, Thin Film, 0.1%, 22.1k, 0402
R1002 | 10k | Resistor_SMD:R_0402_1005Metric | 1 |  |  | Resistor, US symbol
R1003 | 22 | Resistor_SMD:R_0402_1005Metric | 1 |  |  | Resistor, small US symbol
R1201 | 22 | Resistor_SMD:R_0402_1005Metric | 1 |  |  | Resistor, small US symbol
R1202 | 330 | Resistor_SMD:R_0402_1005Metric | 1 |  |  | Resistor, Thin Film, 0.1%, 330, 0402
R1203 | 100k | Resistor_SMD:R_0402_1005Metric | 1 |  |  | Resistor, US symbol
R1204 | 100k | Resistor_SMD:R_0402_1005Metric | 1 |  |  | Resistor, Thin Film, 0.1%, 100k, 0402
R1205 | 100k | Resistor_SMD:R_0402_1005Metric | 1 |  |  | Resistor, US symbol
R1206 | 100k | Resistor_SMD:R_0402_1005Metric | 1 |  |  | Resistor, US symbol
R1207 | 330 | Resistor_SMD:R_0402_1005Metric | 1 |  |  | Resistor, US symbol
R1208 | 330 | Resistor_SMD:R_0402_1005Metric | 1 |  |  | Resistor, US symbol
R1209 | 330 | Resistor_SMD:R_0402_1005Metric | 1 |  |  | Resistor, US symbol
R1401 | 22.1k | Resistor_SMD:R_0402_1005Metric | 1 |  |  | Resistor, Thin Film, 0.1%, 22.1k, 0402
R1402 | 10k | Resistor_SMD:R_0402_1005Metric | 1 |  |  | Resistor, US symbol
R1403 | 22 | Resistor_SMD:R_0402_1005Metric | 1 |  |  | Resistor, small US symbol
R1501 | 100k | Resistor_SMD:R_0402_1005Metric | 1 |  |  | Resistor, Thin Film, 0.1%, 100k, 0402
R1502 | 22.1k | Resistor_SMD:R_0402_1005Metric | 1 |  |  | Resistor, Thin Film, 0.1%, 22.1k, 0402
R1503 | 47k | Resistor_SMD:R_0402_1005Metric | 1 |  |  | Resistor, US symbol
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

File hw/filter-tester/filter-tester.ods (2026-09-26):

Reference | Qty | Value | Footprint | MPN | Manufacturer | Mouser_PN
C101,C102 | 2 | 100nF | Capacitor_SMD:C_1206_3216Metric | GRM3195C2A104JA01D | muRata | 81-GRM31C5C2A104JA1L
C201,C202,C205 | 3 | 1.3nF | Capacitor_SMD:C_0402_1005Metric | C0402C132J5GACTU | KEMET | 80-C0402C132J5GACTU
C203 | 1 | 2nF | Capacitor_SMD:C_0402_1005Metric | C0402C202J3GACTU | KEMET | 80-C0402C202J3G
C204,C209 | 2 | 510pF | Capacitor_SMD:C_0402_1005Metric | GRT1555C1H511FA02D | muRata | 81-GRT1555C1H511FA2D
C206 | 1 | 910pF | Capacitor_SMD:C_0402_1005Metric | GRT1555C1H911FA02D | muRata | 81-GRT1555C1H911FA2D
C207,C208 | 2 | 200pF | Capacitor_SMD:C_0402_1005Metric | GCM1555C1H201FA16D | muRata | 81-GCM1555C1H201FA6D
C210,C211 | 2 | 75pF | Capacitor_SMD:C_0402_1005Metric | GCM1555C1H750FA16J | muRata | 81-GCM1555C1H750FA6J
C212 | 1 | 470pF | Capacitor_SMD:C_0402_1005Metric | GRM1555C2A471GE01D | muRata | 81-GRM1555C2A471GE1D
C213,C214 | 2 | 39pF | Capacitor_SMD:C_0402_1005Metric | GRM1555C2A390JA01D | muRata | 81-GRM1555C2A390JA1D
C215 | 1 | 430pF | Capacitor_SMD:C_0402_1005Metric | GRT1555C1H431FA02D | muRata | 81-GRT1555C1H431FA2D
C216,C219 | 2 | 1.6nF | Capacitor_SMD:C_0805_2012Metric | GRM2165C1H162JA01D | muRata | 81-GRM2165C1H162JA1D
C217,C218 | 2 | 910pF | Capacitor_SMD:C_0805_2012Metric | 08051A911JAT2A | Kyocera | 581-08051A911JAT2A
J101,J102 | 2 | SMA | Library:733910083 | 73391-0083 | Molex | 538-73391-0083
J103 | 1 | Conn_02x10_Odd_Even | Connector_PinHeader_2.54mm:PinHeader_2x10_P2.54mm_Vertical_SMD | M20-8761046 | Harwin | 855-M20-8761046
R101,R102,R103,R104,R105,R106,R107,R108,R109,R110 | 10 | 10k | Resistor_SMD:R_0603_1608Metric | RC0402JR-7D10KL | YAGEO | 603-RC0402JR-7D10KL
U201,U202,U203,U204,U205,U206,U207,U208,U209,U210 | 10 | AS183-92LF | Library:SOT65P220X110-6N | AS183-92LF | Skyworks | 873-AS183-92LF
https://www.mouser.com/en/account/orders/detail
W2026043007513973

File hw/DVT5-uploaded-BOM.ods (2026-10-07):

Comment | Designator | Footprint | JLCPCB Part # | Qty | Ext.Price($)
4.7uF | C1001,C1002,C1401,C1402,C214,C806,C810,C819,C824,C831,C834,C838,C840,C906,C910,C919,C924,C931,C934,C938,C940 | 0402 | C23733 | 52 | 0.86
AS183-92LF | U301,U302,U401,U402,U501,U502,U601,U602,U701,U702 | SOT65P220X110-6N | C2654768 | 20 | 0.00
47nH | L101 | 0603 | C60035 | 6 | 0.25
TPD1E0B04DPY | D101 | D_SOD-882 | C913830 | 5 | 0.88
SN74LVC2G14DCKRE4 | U101,U103 | SOT65P210X110-6N | C37361 | 8 | 1.68
1nF | C308,C309 | 0402 | C53547 | 20 | 0.18
10uF | C1502,C1506,C1507,C1517,C201,C202,C203,C221,C222,C223,C224,C225,C805,C808,C812,C905,C908,C912,C104,C105 | 0402 | C76991 | 50 | 1.03
8.66 | R401,R402 | 0402 | C166423 | 20 | 0.02
SP0402B-ELC-01ETG | D201,D102 | 0402 | C1974049 | 4 | 0.00
CR3032holder | BT101 | XDBS-CR2032-5 | C48687404 | 2 | 0.24
600 | FB1501,FB201 | 0603 | C1006 | 20 | 0.15
3.3uH | L305,L307 | 1812 | C49241336 | 5 | 1.04
66.5 | R503 | 0402 | C158993 | 20 | 0.01
100k | R101,R1203,R1204,R1205,R1206,R1501 | 0402 | C25741 | 22 | 0.05
300pF | C1508,C304,C306,C312 | 0402 | C126505 | 20 | 0.71
10nF | C1513,C1514,C1516 | 0402 | C1710 | 20 | 0.23
330nH | L310,L311 | L_Coilcraft_2929SQ-331 | C42418223 | 4 | 2.07
150pF | C106,C311,C313,C315,C813,C814,C827,C828,C835,C836,C841,C842,C913,C914,C927,C928,C935,C936,C941,C942 | 0402 | C12220 | 50 | 0.31
pwr+data | J1501 | SAMESKY_UJ20-C-H-G-SMT-1-P16-TR | C45082766 | 2 | 1.50
1.5uH | L1502 | 0603 | C73201 | 20 | 0.36
TPS22918DBVR | U1503 | SOT95P280X145-6N | C131941 | 5 | 1.80
560nH | L308,L309 | 1008 | C54534441 | 8 | 0.58
Si5351C-B-GM | U1201 | QFN-20-1EP_4x4mm_P0.5mm_EP2.7x2.7mm | C3608122 | 2 | 11.03
SMBJ15A | D1501 | D_SMB | C83846 | 5 | 0.71
27pF | C1207,C1208,C1209,C204,C205,C215,C216 | 0402 | C1557 | 24 | 0.06
2.2nF | C307,C310,C807,C821,C833,C839,C907,C921,C933,C939 | 0402 | C2167434 | 24 | 0.33
22k | R1001,R1401,R1502,R219 | 0402 | C25768 | 20 | 0.05
TPS74612PQWDRBRQ1 | U1504,U1501 | SON65P300X300X100-9N-D | C2862740 | 5 | 1.08
ICE40LP384-SG32 | U1001,U1401 | QFNS32_LAT | C1552244 | 4 | 14.03
100nF | C1003,C1004,C1005,C1006,C1007,C1008,C1009,C107,C108,C1201,C1202,C1203,C1204,C1205,C1206,C1403,C1404,C1405,C1406,C1407,C1408,C1409,C1501,C1511,C207,C208,C212,C213,C218,C227,C228,C229,C230,C231,C232,C233,C802,C803,C804,C809,C811,C818,C822,C837,C843,C844,C902,C903,C904,C909,C911,C918,C922,C937,C943,C944 | 0402 | C96446 | 120 | 9.02
STM32H743VIT6 | U201 | LQFP-100_14x14mm_P0.5mm | C114409 | 2 | 24.29
22 | R1003,R1201,R1403,R1505,R202,R203,R204,R205,R208,R209,R210,R214,R215,R218,R220,R221,R226,R806,R808,R906,R908 | 0402 | C25092 | 52 | 0.14
1uF | C1503,C1504,C1505,C1509,C1510,C206,C209,C210,C211,C217,C226,C801,C816,C901,C916 | 0402 | C77009 | 42 | 0.29
LMR51430 | U1502 | SOT-23-6 | C5210749 | 2 | 1.67
1k | R1507,R1508,R222 | 0402 | C11702 | 20 | 0.04
10k | R1002,R1402,R1511,R201,R206,R207,R223,R224,R225,R227,R231,R803,R813,R903,R913 | 0402 | C283961 | 40 | 0.29
GNSSmodule | U102 | MAXM10M20B | C90770 | 2 | 6.47
100 | R1512,R211,R212,R213,R216,R217,R801,R802,R804,R805,R809,R810,R811,R812,R901,R902,R904,R905,R909,R910,R911,R912 | 0402 | C332259 | 54 | 0.78
1.5nF | C302 | 0402 | C668348 | 20 | 0.36
910pF | C301,C303 | 0603 | C458911 | 20 | 0.38
680pF | C305 | 0402 | C113781 | 20 | 0.15
75pF | C314,C316 | 0402 | C37809 | 20 | 0.07
6.34 | R703 | 0402 | C166432 | 20 | 0.02
26.7 | R603 | 0402 | C159056 | 20 | 0.09
5.1k | R1210,R1509,R1510,R229,R230 | 0402 | C854378 | 20 | 0.64
2.2uF | C1512,C1515,C219,C220 | 0402 | C50254 | 16 | 1.37
USB3343-CP | U202 | QFN-24-1EP_4x4mm_P0.5mm_EP2.6x2.6mm | C633347 | 2 | 6.22
TLV320ADC5140IRTWR | U802,U902 | RTW24_4P15X4P15_TEX | C2876368 | 4 | 18.18
47k | R1503,R1504,R1506 | 0402 | C25792 | 20 | 0.05
16.5 | R501,R502 | 0402 | C368412 | 20 | 0.02
44.2 | R701,R702 | 0402 | C173939 | 20 | 0.06
68710814022 | J201 | 68710814022 | C293338 | 5 | 1.67
ESD9B5.0ST5G | D1502,D1503 | D_SOD-923 | C111566 | 9 | 0.41
SN74CBTLV3125RGYR | U801,U803,U804,U805,U901,U903,U904,U905 | DGV14 | C133940 | 16 | 0.00
2.7uH | L301,L302,L306 | 1812 | C20882986 | 10 | 10.93
26MHz | Y201,Y202 | Crystal_SMD_2520-4Pin_2.5x2.0mm | C2149229 | 5 | 0.66
OPA320AIDBVR | U1505 | SOT95P280X145-5N | C92494 | 2 | 2.72
100nF | C101,C102,C103,C825,C845,C925,C945 | 1206 | C170182 | 16 | 2.67
SMA | J101,J102 | SMAJPHRATH1 | C493445 | 4 | 28.08
330 | R1202,R1207,R1208,R1209,R228 | 0402 | C25104 | 20 | 0.08
FTSH-105-01-L-DV-K | J202 | FTSH10501LDVK | C5155080 | 2 | 2.89
10 | R807,R814,R907,R914 | 0402 | C25077 | 20 | 0.06
143 | R403 | 0402 | C852531 | 20 | 0.40
1.2uH | L303,L304 | 1812 | C52259879 | 4 | 0.93
2.2uH | L1501 | 0805 | C341781 | 5 | 1.82
30.1 | R601,R602 | 0402 | C67234 | 20 | 0.01
350V | GD101 | GDT3535S1RP | C19947197 | 2 | 0.00
40MHz | Y1201 | ECSTXO201633400TR | C2451471 | 2 | 4.92

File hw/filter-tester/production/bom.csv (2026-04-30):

Designator | Footprint | Quantity | Value | LCSC Part #
C101, C102 | 1206 | 2 | 100nF | GRM3195C2A104JA01D
C201, C202, C205 | 0402 | 3 | 1.3nF | C0402C132J5GACTU
C203 | 0402 | 1 | 2nF | C0402C202J3GACTU
C204, C209 | 0402 | 2 | 510pF | GRT1555C1H511FA02D
C206 | 0402 | 1 | 910pF | GRT1555C1H911FA02D
C207, C208 | 0402 | 2 | 200pF | GCM1555C1H201FA16D
C210, C211 | 0402 | 2 | 75pF | GCM1555C1H750FA16J
C212 | 0402 | 1 | 470pF | GRM1555C2A471GE01D
C213, C214 | 0402 | 2 | 39pF | GRM1555C2A390JA01D
C215 | 0402 | 1 | 430pF | GRT1555C1H431FA02D
C216, C219 | 0805 | 2 | 1.6nF | GRM2165C1H162JA01D
C217, C218 | 0805 | 2 | 910pF | 08051A911JAT2A
J101, J102 | 733910083 | 2 | SMA | 73391-0083
J103 | PinHeader_2x10_P2.54mm_Vertical_SMD | 1 | Conn_02x10_Odd_Even | M20-8761046
L201, L202, L216, L217, L218 | 1812 | 5 | 3.3uH | 1812CS-332XJR
L203, L204, L205 | 1812 | 3 | 2.2uH | 1812CS-222XJR
L206, L207, L208 | 1812 | 3 | 1.2uH | 1812CS-122XJR
L209 | 1206 | 1 | 470nH | AISC-1206-R47G-T
L210, L211, L213, L214 | 1812 | 4 | 1uH | 1812CS-102XJR
L212 | 1206 | 1 | 150nH | AISC-1206-R15G-T
L215 | 1206 | 1 | 82nH | AISC-1206-82NK-T
R101, R102, R103, R104, R105, R106, R107, R108, R109, R110 | 0603 | 10 | 10k | RC0402JR-7D10KL
U201, U202, U203, U204, U205, U206, U207, U208, U209, U210 | SOT65P220X110-6N | 10 | AS183-92LF | AS183-92LF

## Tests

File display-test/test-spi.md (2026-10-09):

| STM32 pin | Function | wire color and connector |
| +---+ | +---+ | +---+ |
| PG3 | RES  | WH/PUR CN8 |
| PB3 | SCK  | YEL CN7 |
| PA4 | NSS  | ORG CN7 |
| PB5 | MOSI | BLU CN7 |
| PG2 | DC   | GRN CN8 |
| 3v3 | 3.3V | RED CN8 |
| GND | GND  | BLK CN8 |

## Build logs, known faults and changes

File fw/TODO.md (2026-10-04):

# NexRx Firmware (fw) - Development TODO

## Phase 1: Basic Bring-Up & Infrastructure
- [x] **Debug Logging**: Route logs over dedicated USB CDC-ACM 0 (virtual COM port) and configure USART6 (PC6 TX) as auxiliary hardware debug UART.
- [ ] **Power & USB-C CC Monitoring**: Read `cc1ADC` (PC5) and `cc2ADC` (PA7) via ADC1 to determine USB-C power budget (500mA, 1.5A, 3.0A) before enabling 3.3V power rail via `enable3V3` (PD6).
- [ ] **Power Status Indication**: Display error banner on LCD and set RGB status LED (PB8/PB9/PE6) if detected USB power is inadequate.
- [x] **Display**: SPI2 driver and `DisplayManager` for ST7789V status rendering ("BOOTING...", "WAIT CPLD", "READY").

## Phase 2: Host Connectivity & Dynamic CPLD Configuration (Path B)
- [ ] **USB High-Speed PHY (ULPI)**: Configure Zephyr `&usbotg_hs` with external USB3343 ULPI PHY for sustained 480 Mb/s throughput.
- [ ] **USB Device Composite Stack**:
  - Endpoint 0x81 Bulk IN: continuous 384 ksps I/Q sample stream (24.576 Mbps).
  - CDC-ACM 0: Interactive Zephyr Shell & serial console.
  - CDC-ACM 1: CBOR request/response control plane.
- [ ] **Firmware Version Handshake**: Report firmware version and protocol magic on connection; App verifies compatibility and displays an interactive modal if an update is required.
- [ ] **Dynamic CPLD Bitstream Loading**:
  - App streams ~7.1 KB iCE40 bitstream over USB (`CMD_LOAD_CPLD`).
  - MCU triggers Slave SPI configuration sequence over SPI3 simultaneously to both CPLDs (`cpld0NCS` PA4, `cpld1NCS` PA15, `cpldCRESET` PE1).
  - Monitor `cpldDONE` (PE0) pin for configuration success.
  - Validate register access by checking signature `0x4E785278` ("NxRx") on both CPLDs.

## Phase 3: Peripheral & Front-End Control
- [ ] **Direct GPIO Attenuator Array**: Implement `FrontEndDriver` controlling AS183-92LF step attenuator switches on GPIOD (`atten3dB` PD10, `atten6dB` PD7, `atten12dB` PD8, `atten24dB` PD9) for 0 to 45 dB attenuation in 3 dB steps.
- [ ] **Direct GPIO Filter Bank**: Implement BPF/HPF band selection on GPIOD (`bpf1` PD1, `bpf2` PD0, `bpf3` PD5, `bpf4` PD4, `hpf` PD2, `nhpf` PD3) to switch the 4 octave bandpass filters and broadcast AM high-pass filter.
- [ ] **Si5351 Synthesizer**: Complete I2C1 MultiSynth fractional PLL/divider calculation for OSD0 ($f - 12\text{kHz}$) and OSD1 ($f + 12\text{kHz}$), applying $8\times$ factor in 8-phase mode (< 15 MHz) and $4\times$ in 4-phase mode (> 15 MHz).
- [x] **Dual TLV320ADC5140 Audio ADCs**: Configure both quad-channel ADCs over SPI4 for 384 ksps 24-bit TDM/I2S output and integrated PGA gain control (0 to 42 dB).
- [ ] **GNSS Telemetry**: UART7 driver for GNSS receiver and 1pps TCXO discipline counter latch via CPLD registers.

## Phase 4: High-Speed Audio Capture & Cortex-M7 DSP Pipeline
- [ ] **SAI2 Capture Engine**:
  - Configure SAI2b (Master) on PA0/PA1/PA2/PA12 for OSD0 (4 channels, 24-bit, 384 ksps).
  - Configure SAI2a (Slave) on PD11 for OSD1 (4 channels, 24-bit, 384 ksps) synchronous to SAI2b clocks.
  - Set up circular ping-pong DMA buffers in AXI SRAM (`sram0` @ `0x24000000`).
- [ ] **On-Chip DSP Channel Reduction**:
  - Polyphase projection: Combine 4 differential phases per OSD into orthogonal $I/Q$ baseband pairs.
  - Complex phasor rotation: Rotate OSD0 by $-12\text{kHz}$ and OSD1 by $+12\text{kHz}$.
  - Coherent summation: $(OSD0_{\text{rot}} + OSD1_{\text{rot}}) \times 0.5$ for $+6\text{ dB}$ signal reinforcement and image rejection.
  - 4-Phase gain normalization: Automatically scale by $+3\text{ dB}$ ($\times \sqrt{2}$) when in 4-phase mode.
- [ ] **Fast Reflex AGC**: Peak detection $\max(|I|, |Q|)$ per frame; coordinate step attenuator switching with PGA gain reduction within $< 500\ \mu\text{s}$ to prevent ADC clipping.
- [ ] **Data Framing & USB Offload**: Pack interleaved 2-channel 384 ksps samples into fixed binary `IQPacketHeader` (Version 2) with timestamp and sequence numbering, submitting to USB Bulk IN endpoint.

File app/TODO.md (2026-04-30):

# NOTES to do

* Add tag for platform the app is running on so we can conditionalize
  things like font path using proper rules.

# UI
* Parameterize spectrum/waterfall rendering (grid, center lines, colors) via Lua and SetBox rules/tags instead of hard-coded C++ values.

## How to do each use scenario
* Show and change bandpass and notch filters on spectrum/waterfall.
* Zoom in and out for waterfall/spectrum width.
* Show sideband rejection.
* Create and change color schemes.
* Move widgets around and set up layout rules.
* Set up SetBox rules and tags and try them out.
* Tie various controls to keystrokes and/or mouse clicks and wheel with modifiers.
  * E.g., volume up and down are up/down arrows and freq is left/right arrows.
  * SetBox for each event type with modifiers as part of name.
    * SetBox sets whatever effect the event is tied to.
	* Can be specific to mouse position or not via event delivery search path.
* Right click or similar "context menu".
  * For volume control -> MUTE.
  * S meter decay time and peaking behavior.
  * Add/change/delete SetBox associated with a UI item.
* Zoom out to show more than +/-50kHz waterfall/spectrum.
  * Can timeshare or quick-shift tuning for QSDs somehow?
* Can waterfall look much more like spectrum rotated out from 2d on screen into 3d?

# Document

The design philosophy is:

  1. All UI is presentation only.
     * We handle events based on tags defined for UI regions, for clicks, keys, modifiers, etc.
	 * The UI widget code creates a presentation.
	 * The code that creates a UI widget by calling that code also
       creates the setbox rules to handle events as needed for that
       UI.

  1. All events dispatched uniformly - clicks, releases, motion, wheel, keys
  2. Tags describe the event context - mouse button type, held mouse buttons, modifiers, widget, mode
  3. SetBox rules determine handlers - no hard-coded mouse button-specific behavior
  4. Motion events are first-class - with held mouse buttons acting as modifier

* Need capability to support future extension of set of UI devices.
  * Can add USB based keypads, touchpads, knobs, etc. for example like the ones used for CAD.

# Hardware Calibration & Verification (ISG)
* Implement FPGA ISG Stimulus:
  * Add command to FPGA to generate PDM "sine" on IOB_22a at a requested frequency.
  * Filtered through 130pf + 100k resistor, fed to rx input in 50 ohm domain.
  * Consider if FPGA can generate a better signal than square wave (e.g., simple DDS or PWM filtering).
  * Add commands to Twin/HW to tune and toggle this ISG signal.
* Filter Bank Calibration:
  * App uses FPGA ISG to inject signal, QSD to measure amplitude.
  * App verifies filter response for each BPF band.
  * App sends this a priori calibration table to Twin/HW for storage.
  * Replace real-time solver with a priori calculation using this calibration data.
* Attenuator Calibration:
  * App uses FPGA ISG to inject steady signal.
  * App switches each attenuator stage (3, 6, 12, 24dB) in and out, measuring actual amplitude drop.
  * App computes true attenuation for each combination.
  * App generates calibration data mapping requested dB to the most accurate bit setting.
* File Server Mechanism:
  * Implement file transfer protocol over TCP link between App and HW/Twin.
  * Support updating: FPGA image, NexBus STM32C011 firmware (up to 16 KBytes).
  * Execute STM32H753 firmware in place (no tiny bootloader). Recovery via standard USB firmware update mechanism.
  * Implement maintenance ops: READ, WRITE, SHA256, DELETE, LIST.
  * Store files in a highly efficient Flash file system optimized for small data files (like calibration data) on STM32H753 flash (and local filesystem for Twin).

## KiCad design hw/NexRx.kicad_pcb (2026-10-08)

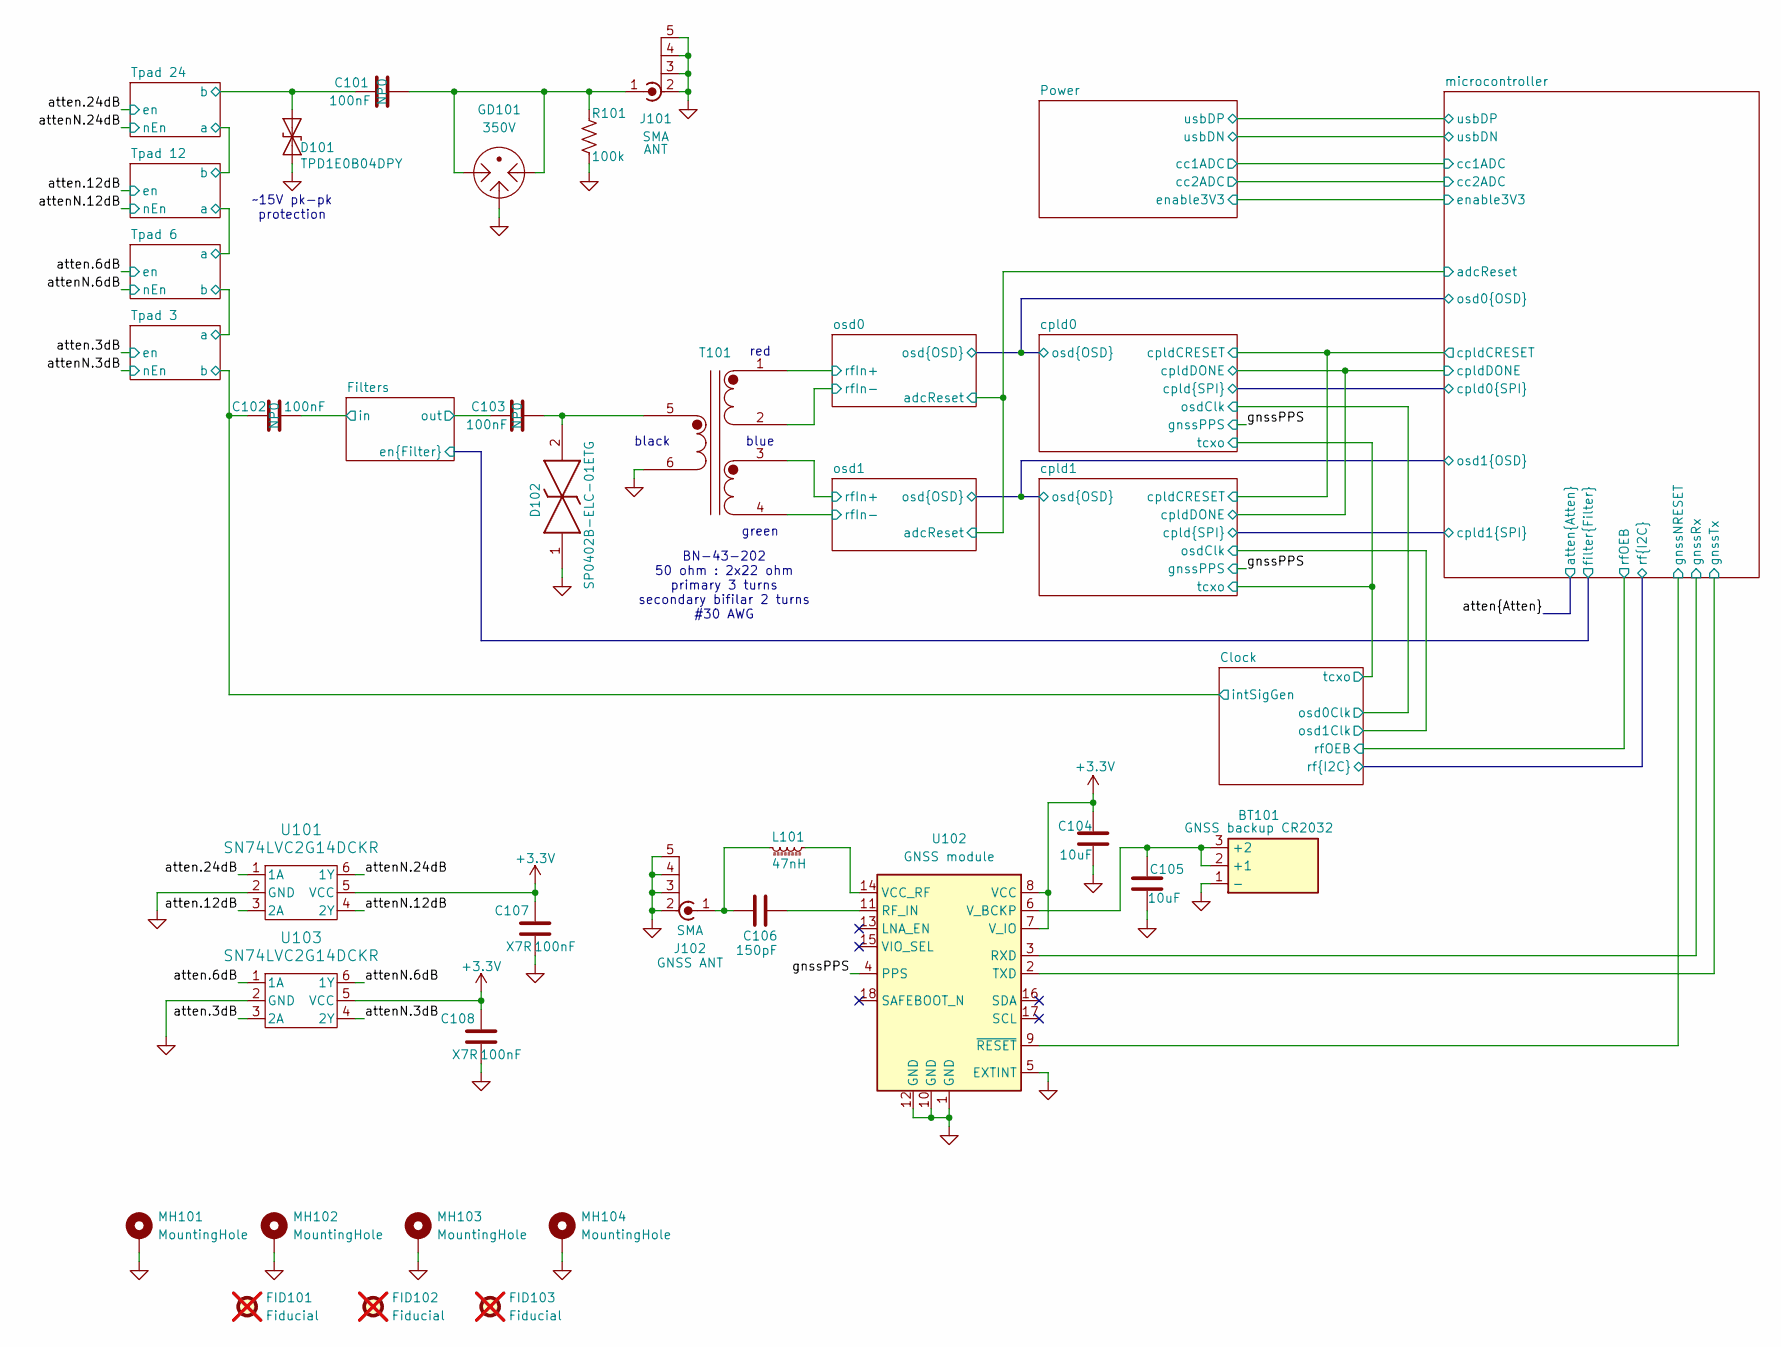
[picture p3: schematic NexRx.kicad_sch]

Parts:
BT101: CR3032 holder; XDBS-CR2032-5; Mouser Part Number 855-S8401-46; LCSC C48687404
C101, C102, C103: 100nF; C_1206_3216Metric; MPN GRM3195C2A104JA01D; LCSC_PN C170182
C104, C105: 10uF; C_0402_1005Metric; MPN CL05A106MP6NUN8; LCSC C479655
C106: 150pF; C_0402_1005Metric; MPN C0402C151J3GACTU; Mouser Part Number C0402C151J3GACTU
C107, C108: 100nF; C_0402_1005Metric; MPN GCM155R71H104KE02D; LCSC_PN C307331
D101: TPD1E0B04DPY; D_0402_1005Metric; LCSC_PN C5182093
D102: SP0402B-ELC-01ETG; D_0402_1005Metric; MPN SP0402B-ELC-01ETG; LCSC_PN C1974049
FID101, FID102, FID103: Fiducial; Fiducial_0.5mm_Mask2mm; MPN n/a; Mouser Part Number n/a; not fitted
GD101: 350V; GDT3535S1RP; MPN GDT35-35-S1-RP; LCSC_PN C19947197
J101, J102: SMA; SMAJPHRATH1; MPN SMA-J-P-H-RA-TH1; LCSC_PN C493445
L101: 47nH; L_0603_1608Metric; MPN AIMC-0603-47NJ-T; LCSC C98076
MH101, MH102, MH103, MH104: MountingHole; MountingHole_3.2mm_M3_ISO7380_Pad
R101: 100k; R_0402_1005Metric; MPN RP0402BRD07100KL; LCSC_PN C25741
T101: BN-43-202, 50:2x22 ohm, 3 turns primary, 2 turns 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; Transformer-2P-2S-BN-43-202
U101, U103: SN74LVC2G14DCKR; SOIC_G14DCK3_TEX; LCSC_PN C37361
U102: GNSS module; MAXM10M20B; MPN ATGM336H-5N31; LCSC C90770

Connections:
+3.3V: C104.1, C107.1, C108.1, U101.5 (VCC), U102.7 (V_IO), U102.8 (VCC), U103.5 (VCC); also elsewhere on the board
/Clock/intSigGen: C102.2; also elsewhere on the board
/Filters/in: C102.1; also elsewhere on the board
/Filters/out: C103.1; also elsewhere on the board
/Tpad 24/b: C101.1, D101.1 (A1); also elsewhere on the board
/atten.3dB: U103.3 (2A); also elsewhere on the board
/atten.6dB: U103.1 (1A); also elsewhere on the board
/atten.12dB: U101.3 (2A); also elsewhere on the board
/atten.24dB: U101.1 (1A); also elsewhere on the board
/attenN.3dB: U103.4 (2Y); also elsewhere on the board
/attenN.6dB: U103.6 (1Y); also elsewhere on the board
/attenN.12dB: U101.4 (2Y); also elsewhere on the board
/attenN.24dB: U101.6 (1Y); also elsewhere on the board
/gnssPPS: U102.4 (PPS); also elsewhere on the board
/microcontroller/gnssNRESET: U102.9 (~RESET); also elsewhere on the board
/microcontroller/gnssRx: U102.3 (RXD); also elsewhere on the board
/microcontroller/gnssTx: U102.2 (TXD); also elsewhere on the board
/osd0/rfIn+: T101.1 (S1A); also elsewhere on the board
/osd0/rfIn-: T101.2 (S1B); also elsewhere on the board
/osd1/rfIn+: T101.3 (S2A); also elsewhere on the board
/osd1/rfIn-: T101.4 (S2B); also elsewhere on the board
GND: BT101.1 (-), C104.2, C105.1, C107.2, C108.2, D101.2 (A2), D102.1, GD101.2, J101.2 (Ext), J101.3 (Ext), J101.4 (Ext), J101.5 (Ext), J102.2 (Ext), J102.3 (Ext), J102.4 (Ext), J102.5 (Ext), MH101.1, MH102.1, MH103.1, MH104.1, R101.2, T101.6 (P1B), U101.2 (GND), U102.1 (GND), U102.5 (EXTINT), U102.10 (GND), U102.12 (GND), U103.2 (GND); also elsewhere on the board
unnamed: BT101.2 (+1), BT101.3 (+2), C105.2, U102.6 (V_BCKP)
unnamed: C101.2, GD101.1, GD101.3, J101.1 (In), R101.1
unnamed: C106.2, J102.1 (In), L101.2
unnamed: C103.2, D102.2, T101.5 (P1A)
unnamed: C106.1, U102.11 (RF_IN)
unnamed: L101.1, U102.14 (VCC_RF)

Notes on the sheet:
black
red
blue
green
~15V pk-pk protection
BN-43-202 50 ohm : 2x22 ohm primary 3 turns secondary bifilar 2 turns #30 AWG

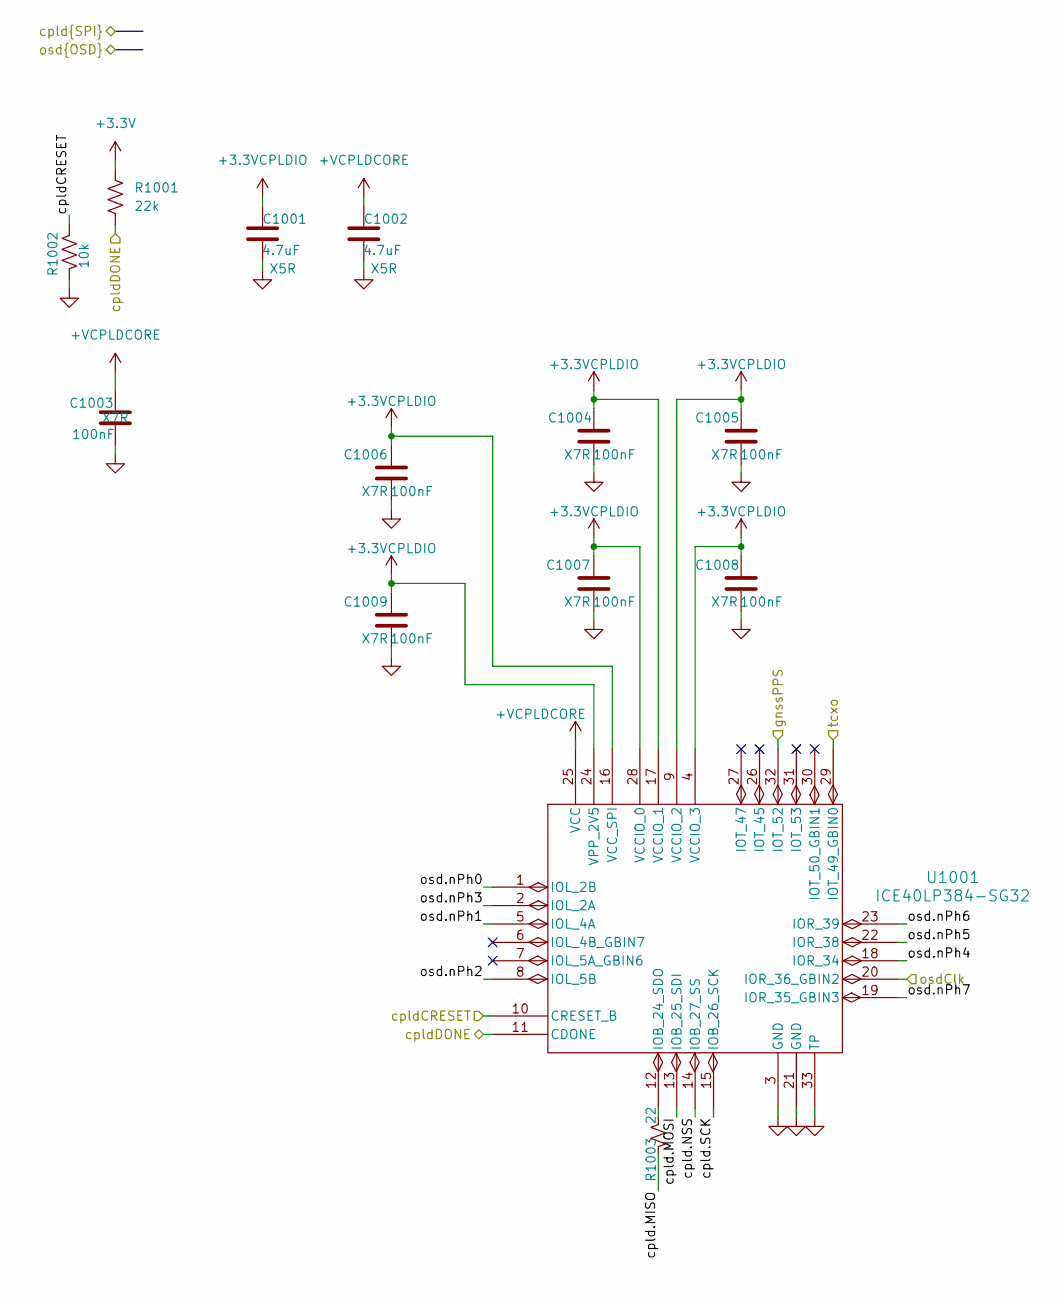
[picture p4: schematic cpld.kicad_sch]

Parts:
C1001, C1002: 4.7uF; C_0402_1005Metric; MPN CM05X5R475M10AH; LCSC_PN C23733
C1003, C1004, C1005, C1006, C1007, C1008, C1009: 100nF; C_0402_1005Metric; MPN GCM155R71H104KE02D; LCSC_PN C307331
R1001: 22k; R_0402_1005Metric; LCSC_PN C25768
R1002: 10k; R_0402_1005Metric; MPN RT0402BRD0710KL; JLCPCBpn C728576
R1003: 22; R_0402_1005Metric; MPN 560112110216; JLCPCBpn C4258780
U1001: ICE40LP384-SG32; QFNS32_LAT; MPN ICE40LP384-SG32; Mouser Part Number 842-ICE40LP384SG32

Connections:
+3.3V: C1001.1, C1004.1, C1005.1, C1006.1, C1007.1, C1008.1, C1009.1, R1001.1, U1001.4 (VCCIO_3), U1001.9 (VCCIO_2), U1001.16 (VCC_SPI), U1001.17 (VCCIO_1), U1001.24 (VPP_2V5), U1001.28 (VCCIO_0); also elsewhere on the board
+VCPLDCORE: C1002.1, C1003.2, U1001.25 (VCC); also elsewhere on the board
/Clock/osd1Clk: U1001.20 (IOR_36_GBIN2); also elsewhere on the board
/Clock/tcxo: U1001.29 (IOT_49_GBIN0); also elsewhere on the board
/cpld0/cpldCRESET: R1002.1, U1001.10 (CRESET_B); also elsewhere on the board
/cpld0/cpldDONE: R1001.2, U1001.11 (CDONE); also elsewhere on the board
/cpld1/cpld.MISO: R1003.2; also elsewhere on the board
/cpld1/cpld.MOSI: U1001.13 (IOB_25_SDI); also elsewhere on the board
/cpld1/cpld.NSS: U1001.14 (IOB_27_SS); also elsewhere on the board
/cpld1/cpld.SCK: U1001.15 (IOB_26_SCK); also elsewhere on the board
/cpld1/osd.nPh0: U1001.1 (IOL_2B); also elsewhere on the board
/cpld1/osd.nPh1: U1001.5 (IOL_4A); also elsewhere on the board
/cpld1/osd.nPh2: U1001.8 (IOL_5B); also elsewhere on the board
/cpld1/osd.nPh3: U1001.2 (IOL_2A); also elsewhere on the board
/cpld1/osd.nPh4: U1001.18 (IOR_34); also elsewhere on the board
/cpld1/osd.nPh5: U1001.22 (IOR_38); also elsewhere on the board
/cpld1/osd.nPh6: U1001.23 (IOR_39); also elsewhere on the board
/cpld1/osd.nPh7: U1001.19 (IOR_35_GBIN3); also elsewhere on the board
/gnssPPS: U1001.32 (IOT_52); also elsewhere on the board
GND: C1001.2, C1002.2, C1003.1, C1004.2, C1005.2, C1006.2, C1007.2, C1008.2, C1009.2, R1002.2, U1001.3 (GND), U1001.21 (GND), U1001.33 (TP); also elsewhere on the board
unnamed: R1003.1, U1001.12 (IOB_24_SDO)

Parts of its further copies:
C1401, C1402: 4.7uF; C_0402_1005Metric; MPN CM05X5R475M10AH; LCSC_PN C23733
C1403, C1404, C1405, C1406, C1407, C1408, C1409: 100nF; C_0402_1005Metric; MPN GCM155R71H104KE02D; LCSC_PN C307331
R1401: 22k; R_0402_1005Metric; LCSC_PN C25768
R1402: 10k; R_0402_1005Metric; MPN RT0402BRD0710KL; JLCPCBpn C728576
R1403: 22; R_0402_1005Metric; MPN 560112110216; JLCPCBpn C4258780
U1401: ICE40LP384-SG32; QFNS32_LAT; MPN ICE40LP384-SG32; Mouser Part Number 842-ICE40LP384SG32

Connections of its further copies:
+3.3V: C1401.1, C1404.1, C1405.1, C1406.1, C1407.1, C1408.1, C1409.1, R1401.1, U1401.4 (VCCIO_3), U1401.9 (VCCIO_2), U1401.16 (VCC_SPI), U1401.17 (VCCIO_1), U1401.24 (VPP_2V5), U1401.28 (VCCIO_0); also elsewhere on the board
+VCPLDCORE: C1402.1, C1403.2, U1401.25 (VCC); also elsewhere on the board
/Clock/osd0Clk: U1401.20 (IOR_36_GBIN2); also elsewhere on the board
/Clock/tcxo: U1401.29 (IOT_49_GBIN0); also elsewhere on the board
/cpld0/cpld.NSS: U1401.14 (IOB_27_SS); also elsewhere on the board
/cpld0/cpldCRESET: R1402.1, U1401.10 (CRESET_B); also elsewhere on the board
/cpld0/cpldDONE: R1401.2, U1401.11 (CDONE); also elsewhere on the board
/cpld0/osd.nPh0: U1401.1 (IOL_2B); also elsewhere on the board
/cpld0/osd.nPh1: U1401.5 (IOL_4A); also elsewhere on the board
/cpld0/osd.nPh2: U1401.8 (IOL_5B); also elsewhere on the board
/cpld0/osd.nPh3: U1401.2 (IOL_2A); also elsewhere on the board
/cpld0/osd.nPh4: U1401.18 (IOR_34); also elsewhere on the board
/cpld0/osd.nPh5: U1401.22 (IOR_38); also elsewhere on the board
/cpld0/osd.nPh6: U1401.23 (IOR_39); also elsewhere on the board
/cpld0/osd.nPh7: U1401.19 (IOR_35_GBIN3); also elsewhere on the board
/cpld1/cpld.MISO: R1403.2; also elsewhere on the board
/cpld1/cpld.MOSI: U1401.13 (IOB_25_SDI); also elsewhere on the board
/cpld1/cpld.SCK: U1401.15 (IOB_26_SCK); also elsewhere on the board
/gnssPPS: U1401.32 (IOT_52); also elsewhere on the board
GND: C1401.2, C1402.2, C1403.1, C1404.2, C1405.2, C1406.2, C1407.2, C1408.2, C1409.2, R1402.2, U1401.3 (GND), U1401.21 (GND), U1401.33 (TP); also elsewhere on the board
unnamed: R1403.1, U1401.12 (IOB_24_SDO)

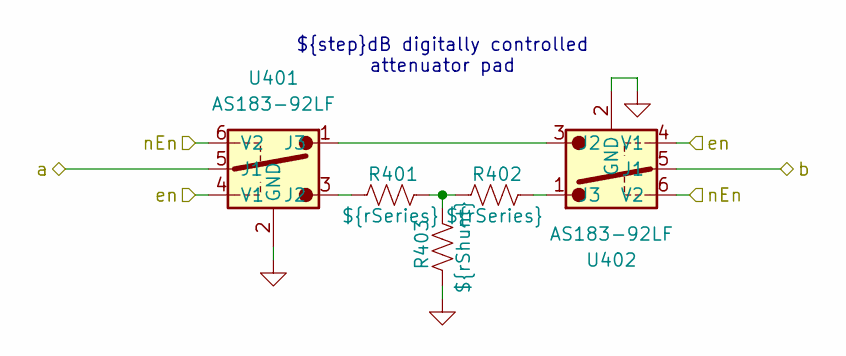
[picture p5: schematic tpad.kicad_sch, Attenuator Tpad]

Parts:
R401, R402: ${rSeries}; R_0402_1005Metric; LCSC_PN ${rSeriesLCSC}
R403: ${rShunt}; R_0402_1005Metric; LCSC_PN C270643
U401, U402: AS183-92LF; SOT65P220X110-6N; MPN AS183-92LF; LCSC_PN C2654768

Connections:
/Clock/intSigGen: U402.5 (J1); also elsewhere on the board
/Tpad 3/a: U401.5 (J1); also elsewhere on the board
/atten.3dB: U401.4 (V1), U402.4 (V1); also elsewhere on the board
/attenN.3dB: U401.6 (V2), U402.6 (V2); also elsewhere on the board
GND: R403.2, U401.2 (GND), U402.2 (GND); also elsewhere on the board
unnamed: R401.1, R402.2, R403.1
unnamed: R401.2, U401.3 (J2)
unnamed: U401.1 (J3), U402.3 (J2)
unnamed: R402.1, U402.1 (J3)

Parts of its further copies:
U501, U502, U601, U602, U701, U702: AS183-92LF; SOT65P220X110-6N; MPN AS183-92LF; LCSC_PN C2654768

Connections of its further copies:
/Tpad 3/a: U502.5 (J1); also elsewhere on the board
/Tpad 12/a: U501.5 (J1), U601.5 (J1)
/Tpad 12/b: U602.5 (J1), U701.5 (J1)
/Tpad 24/b: U702.5 (J1); also elsewhere on the board
/atten.6dB: U501.4 (V1), U502.4 (V1); also elsewhere on the board
/atten.12dB: U601.4 (V1), U602.4 (V1); also elsewhere on the board
/atten.24dB: U701.4 (V1), U702.4 (V1); also elsewhere on the board
/attenN.6dB: U501.6 (V2), U502.6 (V2); also elsewhere on the board
/attenN.12dB: U601.6 (V2), U602.6 (V2); also elsewhere on the board
/attenN.24dB: U701.6 (V2), U702.6 (V2); also elsewhere on the board
GND: U501.2 (GND), U502.2 (GND), U601.2 (GND), U602.2 (GND), U701.2 (GND), U702.2 (GND); also elsewhere on the board
unnamed 210: U501.3 (J2); also elsewhere on the board
unnamed: U501.1 (J3), U502.3 (J2)
unnamed 212: U502.1 (J3); also elsewhere on the board
unnamed 213: U601.3 (J2); also elsewhere on the board
unnamed: U601.1 (J3), U602.3 (J2)
unnamed 215: U602.1 (J3); also elsewhere on the board
unnamed 216: U701.3 (J2); also elsewhere on the board
unnamed: U701.1 (J3), U702.3 (J2)
unnamed 218: U702.1 (J3); also elsewhere on the board

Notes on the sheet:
${step}dB digitally controlled attenuator pad

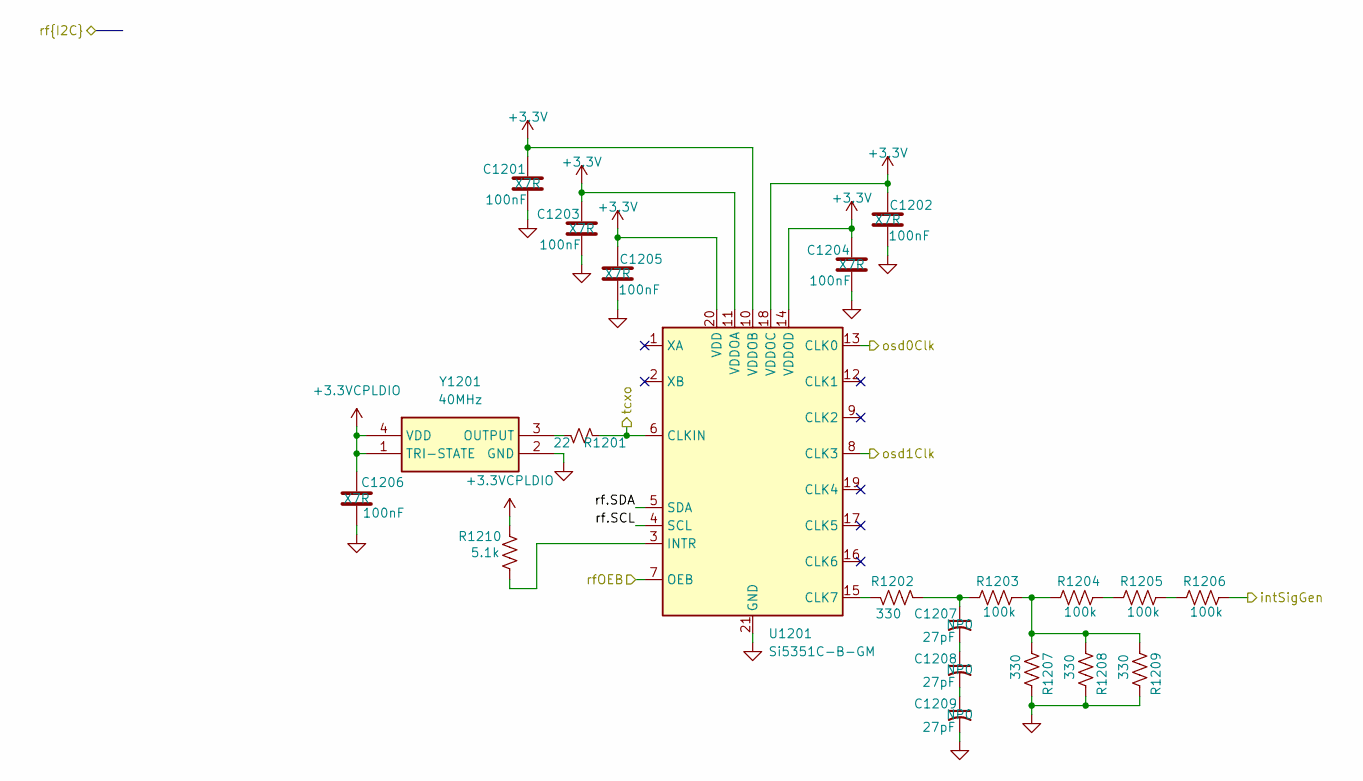
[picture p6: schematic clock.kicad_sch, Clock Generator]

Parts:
C1201, C1202, C1203, C1204, C1205, C1206: 100nF; C_0402_1005Metric; MPN GCM155R71H104KE02D; LCSC_PN C307331
C1207, C1208, C1209: 27pF; C_0402_1005Metric; MPN 04023A270JAT2A; Mouser Part Number 581-04023A270JAT2A
R1201: 22; R_0402_1005Metric; MPN 560112110216; JLCPCBpn C4258780
R1202: 330; R_0402_1005Metric; MPN RC0402JR-7D330RL; LCSC_PN C25104
R1203, R1205, R1206: 100k; R_0402_1005Metric; MPN RP0402BRD07100KL; JLCPCBpn C728576
R1204: 100k; R_0402_1005Metric; MPN RP0402BRD07100KL; LCSC_PN C25741
R1207, R1208, R1209: 330; R_0402_1005Metric; MPN RC0402JR-7D330RL; JLCPCBpn C854274
R1210: 5.1k; R_0402_1005Metric; MPN AC0402FR-7W5K1L; LCSC_PN C854378
U1201: Si5351C-B-GM; QFN-20-1EP_4x4mm_P0.5mm_EP2.7x2.7mm; MPN SI5351C-B-GM; Mouser Part Number 634-SI5351C-B-GM
Y1201: 40MHz; ECSTXO201633400TR; MPN ECS-TXO-2016-33-400-TR; LCSC_PN C2451471

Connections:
+3.3V: C1201.2, C1202.2, C1203.2, C1204.2, C1205.2, C1206.1, R1210.1, U1201.10 (VDDOB), U1201.11 (VDDOA), U1201.14 (VDDOD), U1201.18 (VDDOC), U1201.20 (VDD), Y1201.1 (TRI-STATE), Y1201.4 (VDD); also elsewhere on the board
/Clock/intSigGen: R1206.2; also elsewhere on the board
/Clock/osd0Clk: U1201.13 (CLK0); also elsewhere on the board
/Clock/osd1Clk: U1201.8 (CLK3); also elsewhere on the board
/Clock/rf.SCL: U1201.4 (SCL); also elsewhere on the board
/Clock/rf.SDA: U1201.5 (SDA); also elsewhere on the board
/Clock/rfOEB: U1201.7 (OEB); also elsewhere on the board
/Clock/tcxo: R1201.2, U1201.6 (CLKIN); also elsewhere on the board
GND: C1201.1, C1202.1, C1203.1, C1204.1, C1205.1, C1206.2, C1209.2, R1207.1, R1208.1, R1209.1, U1201.21 (GND), Y1201.2 (GND); also elsewhere on the board
unnamed: C1207.1, R1202.2, R1203.1
unnamed: C1207.2, C1208.1
unnamed: C1208.2, C1209.1
unnamed: R1203.2, R1204.1, R1207.2, R1208.2, R1209.2
unnamed: R1204.2, R1205.1
unnamed: R1205.2, R1206.1
unnamed: R1202.1, U1201.15 (CLK7)
unnamed: R1210.2, U1201.3 (INTR)
unnamed: R1201.1, Y1201.3 (OUTPUT)

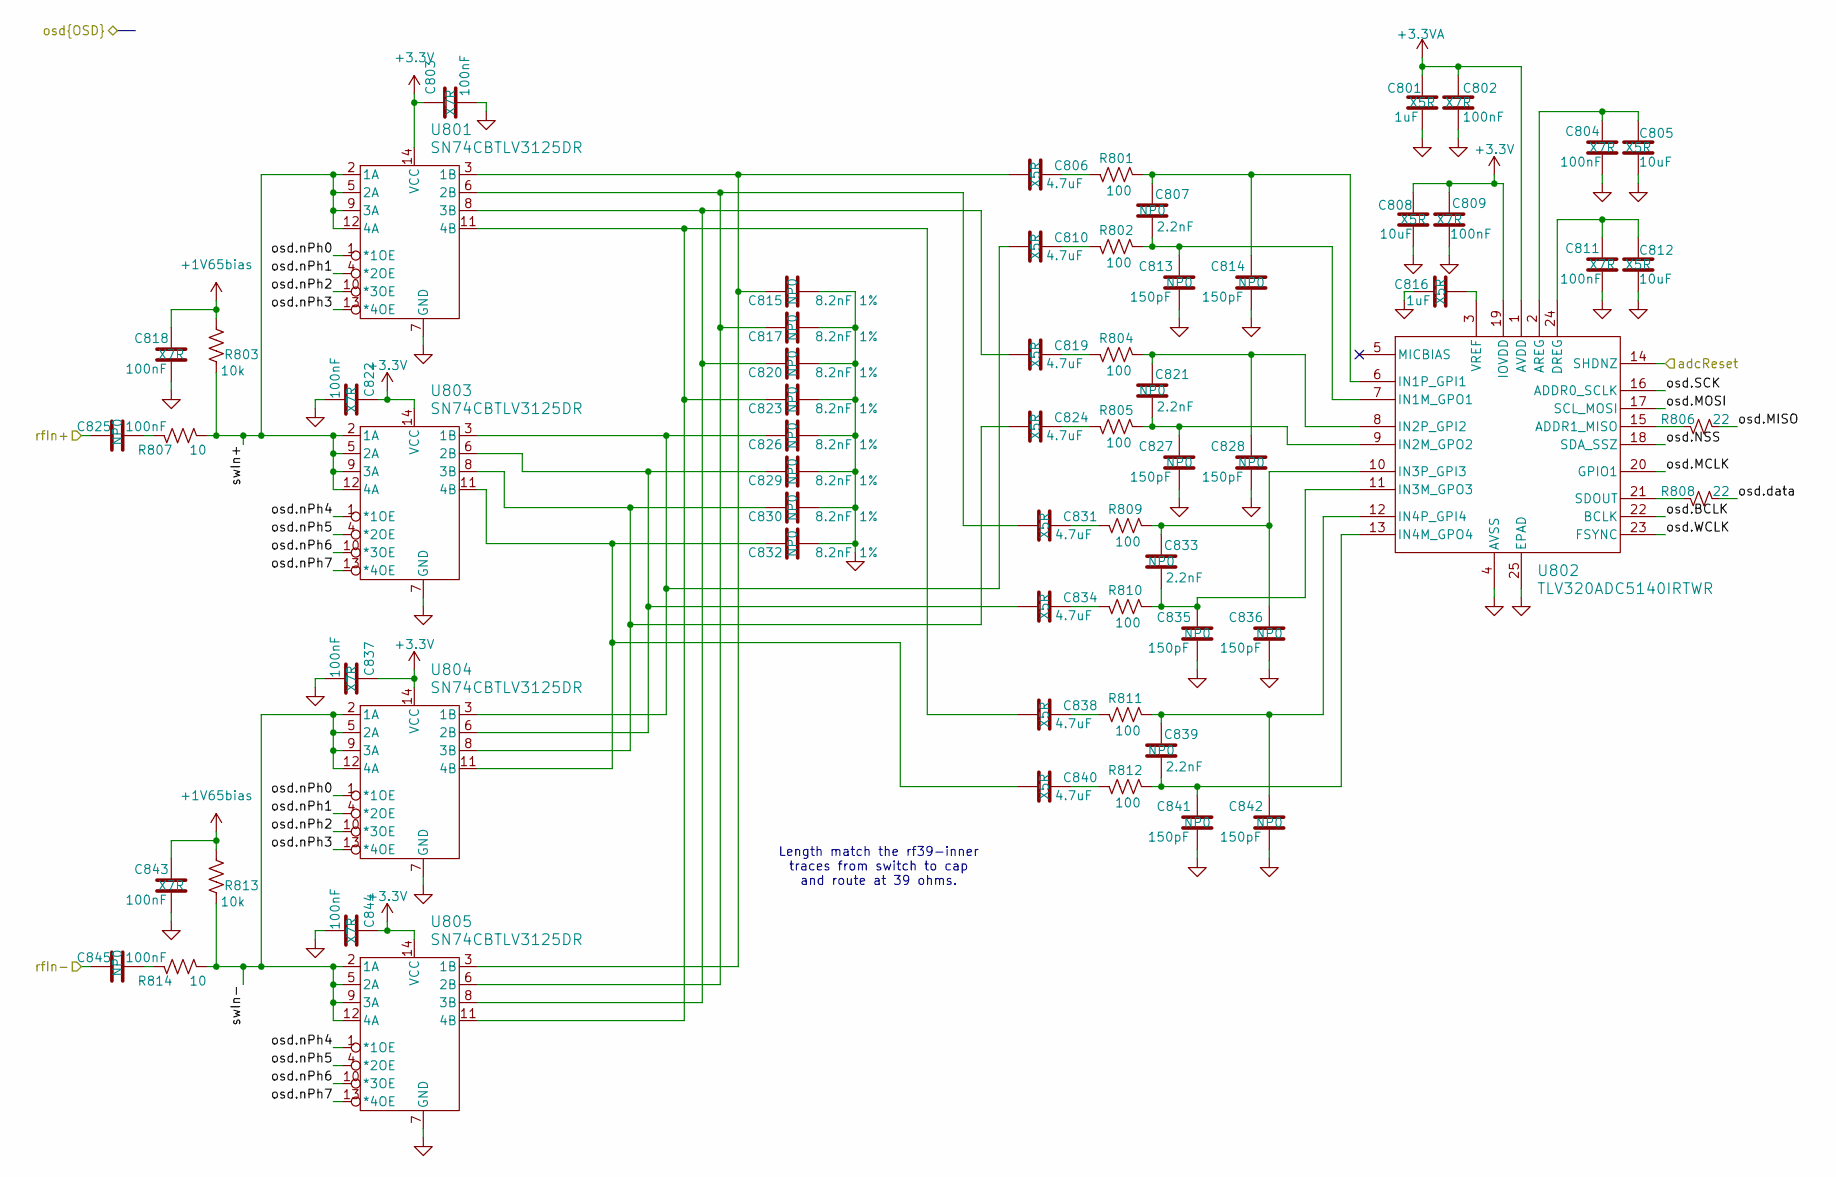
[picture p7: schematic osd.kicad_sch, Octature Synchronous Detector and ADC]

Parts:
C801, C816: 1uF; C_0402_1005Metric; MPN GRM155R61E105MA12D; LCSC_PN C77009
C802, C803, C804, C809, C811, C818, C822, C837, C843, C844: 100nF; C_0402_1005Metric; MPN GCM155R71H104KE02D; LCSC_PN C307331
C805, C808, C812: 10uF; C_0402_1005Metric; MPN CL05A106MP6NUN8; LCSC_PN C76991
C806, C810, C819, C824, C831, C834, C838, C840: 4.7uF; C_0402_1005Metric; MPN CM05X5R475M10AH; LCSC_PN C23733
C807, C821, C833, C839: 2.2nF; C_0402_1005Metric; MPN C0402C222K3GECTU; LCSC_PN C2167434
C813, C814, C827, C828, C835, C836, C841, C842: 150pF; C_0402_1005Metric; MPN C0402C151J3GACTU; LCSC_PN C12220
C815, C817, C820, C823, C826, C829, C830, C832: 8.2nF 1%; C_0805_2012Metric; Mouser Part Number 581-08053A822FAT2A
C825, C845: 100nF; C_1206_3216Metric; MPN GRM3195C2A104JA01D; LCSC_PN C170182
R801, R802, R804, R805, R809, R810, R811, R812: 100; R_0402_1005Metric; MPN MCS04020C1000FE000; LCSC_PN C332259
R803, R813: 10k; R_0402_1005Metric; MPN RT0402BRD0710KL; LCSC_PN C283961
R806, R808: 22; R_0402_1005Metric; MPN 560112110216; JLCPCBpn C4258780
R807, R814: 10; R_0402_1005Metric; MPN RE0402FRE0710RL; LCSC_PN C25077
U801, U803, U804, U805: SN74CBTLV3125DR; DGV14; MPN SN74CBTLV3125DGVR; LCSC_PN C2674493
U802: TLV320ADC5140IRTWR; RTW24_4P15X4P15_TEX; MPN TLV320ADC5140IRTWR; Mouser Part Number 595-V320ADC5140IRTWR

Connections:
+1V65bias: C818.1, C843.1, R803.1, R813.1; also elsewhere on the board
+3.3V: C803.1, C808.1, C809.1, C822.1, C837.1, C844.1, U801.14 (VCC), U802.19 (IOVDD), U803.14 (VCC), U804.14 (VCC), U805.14 (VCC); also elsewhere on the board
+3.3VA: C801.2, C802.2, U802.1 (AVDD); also elsewhere on the board
/cpld0/osd.NSS: U802.18 (SDA_SSZ); also elsewhere on the board
/cpld0/osd.data: R808.1; also elsewhere on the board
/cpld0/osd.nPh0: U801.1 (*1OE), U804.1 (*1OE); also elsewhere on the board
/cpld0/osd.nPh1: U801.4 (*2OE), U804.4 (*2OE); also elsewhere on the board
/cpld0/osd.nPh2: U801.10 (*3OE), U804.10 (*3OE); also elsewhere on the board
/cpld0/osd.nPh3: U801.13 (*4OE), U804.13 (*4OE); also elsewhere on the board
/cpld0/osd.nPh4: U803.1 (*1OE), U805.1 (*1OE); also elsewhere on the board
/cpld0/osd.nPh5: U803.4 (*2OE), U805.4 (*2OE); also elsewhere on the board
/cpld0/osd.nPh6: U803.10 (*3OE), U805.10 (*3OE); also elsewhere on the board
/cpld0/osd.nPh7: U803.13 (*4OE), U805.13 (*4OE); also elsewhere on the board
/cpld1/osd.BCLK: U802.22 (BCLK); also elsewhere on the board
/cpld1/osd.MCLK: U802.20 (GPIO1); also elsewhere on the board
/cpld1/osd.MISO: R806.1; also elsewhere on the board
/cpld1/osd.MOSI: U802.17 (SCL_MOSI); also elsewhere on the board
/cpld1/osd.SCK: U802.16 (ADDR0_SCLK); also elsewhere on the board
/cpld1/osd.WCLK: U802.23 (FSYNC); also elsewhere on the board
/microcontroller/adcReset: U802.14 (SHDNZ); also elsewhere on the board
/osd0/rfIn+: C825.1; also elsewhere on the board
/osd0/rfIn-: C845.1; also elsewhere on the board
/osd0/swIn+: R803.2, R807.2, U801.2 (1A), U801.5 (2A), U801.9 (3A), U801.12 (4A), U803.2 (1A), U803.5 (2A), U803.9 (3A), U803.12 (4A)
/osd0/swIn-: R813.2, R814.2, U804.2 (1A), U804.5 (2A), U804.9 (3A), U804.12 (4A), U805.2 (1A), U805.5 (2A), U805.9 (3A), U805.12 (4A)
GND: C801.1, C802.1, C803.2, C804.2, C805.2, C808.2, C809.2, C811.2, C812.2, C813.2, C814.2, C815.2, C816.1, C817.2, C818.2, C820.2, C822.2, C823.2, C826.2, C827.2, C828.2, C829.2, C830.2, C832.2, C835.2, C836.2, C837.2, C841.2, C842.2, C843.2, C844.2, U801.7 (GND), U802.4 (AVSS), U802.25 (EPAD), U803.7 (GND), U804.7 (GND), U805.7 (GND); also elsewhere on the board
unnamed: C806.2, R801.1
unnamed: C810.2, R802.1
unnamed: C819.2, R804.1
unnamed: C824.2, R805.1
unnamed: C825.2, R807.1
unnamed: C831.2, R809.1
unnamed: C834.2, R810.1
unnamed: C838.2, R811.1
unnamed: C840.2, R812.1
unnamed: C845.2, R814.1
unnamed: C806.1, C815.1, U801.3 (1B), U805.3 (1B)
unnamed: C817.1, C831.1, U801.6 (2B), U805.6 (2B)
unnamed: C819.1, C820.1, U801.8 (3B), U805.8 (3B)
unnamed: C823.1, C838.1, U801.11 (4B), U805.11 (4B)
unnamed: R806.2, U802.15 (ADDR1_MISO)
unnamed: C804.1, C805.1, U802.2 (AREG)
unnamed: C811.1, C812.1, U802.24 (DREG)
unnamed: C807.2, C813.1, R802.2, U802.7 (IN1M_GPO1)
unnamed: C807.1, C814.1, R801.2, U802.6 (IN1P_GPI1)
unnamed: C821.2, C827.1, R805.2, U802.9 (IN2M_GPO2)
unnamed: C821.1, C828.1, R804.2, U802.8 (IN2P_GPI2)
unnamed: C833.2, C835.1, R810.2, U802.11 (IN3M_GPO3)
unnamed: C833.1, C836.1, R809.2, U802.10 (IN3P_GPI3)
unnamed: C839.2, C841.1, R812.2, U802.13 (IN4M_GPO4)
unnamed: C839.1, C842.1, R811.2, U802.12 (IN4P_GPI4)
unnamed: R808.2, U802.21 (SDOUT)
unnamed: C816.2, U802.3 (VREF)
unnamed: C810.1, C826.1, U803.3 (1B), U804.3 (1B)
unnamed: C829.1, C834.1, U803.6 (2B), U804.6 (2B)
unnamed: C824.1, C830.1, U803.8 (3B), U804.8 (3B)
unnamed: C832.1, C840.1, U803.11 (4B), U804.11 (4B)

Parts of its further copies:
C901, C916: 1uF; C_0402_1005Metric; MPN GRM155R61E105MA12D; LCSC_PN C77009
C902, C903, C904, C909, C911, C918, C922, C937, C943, C944: 100nF; C_0402_1005Metric; MPN GCM155R71H104KE02D; LCSC_PN C307331
C905, C908, C912: 10uF; C_0402_1005Metric; MPN CL05A106MP6NUN8; LCSC_PN C76991
C906, C910, C919, C924, C931, C934, C938, C940: 4.7uF; C_0402_1005Metric; MPN CM05X5R475M10AH; LCSC_PN C23733
C907, C921, C933, C939: 2.2nF; C_0402_1005Metric; MPN C0402C222K3GECTU; LCSC_PN C2167434
C913, C914, C927, C928, C935, C936, C941, C942: 150pF; C_0402_1005Metric; MPN C0402C151J3GACTU; LCSC_PN C12220
C915, C917, C920, C923, C926, C929, C930, C932: 8.2nF 1%; C_0805_2012Metric; Mouser Part Number 581-08053A822FAT2A
C925, C945: 100nF; C_1206_3216Metric; MPN GRM3195C2A104JA01D; LCSC_PN C170182
R901, R902, R904, R905, R909, R910, R911, R912: 100; R_0402_1005Metric; MPN MCS04020C1000FE000; LCSC_PN C332259
R903, R913: 10k; R_0402_1005Metric; MPN RT0402BRD0710KL; LCSC_PN C283961
R906, R908: 22; R_0402_1005Metric; MPN 560112110216; JLCPCBpn C4258780
R907, R914: 10; R_0402_1005Metric; MPN RE0402FRE0710RL; LCSC_PN C25077
U901, U903, U904, U905: SN74CBTLV3125DR; DGV14; MPN SN74CBTLV3125DGVR; LCSC_PN C2674493
U902: TLV320ADC5140IRTWR; RTW24_4P15X4P15_TEX; MPN TLV320ADC5140IRTWR; Mouser Part Number 595-V320ADC5140IRTWR

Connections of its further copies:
+1V65bias: C918.1, C943.1, R903.1, R913.1; also elsewhere on the board
+3.3V: C903.1, C908.1, C909.1, C922.1, C937.1, C944.1, U901.14 (VCC), U902.19 (IOVDD), U903.14 (VCC), U904.14 (VCC), U905.14 (VCC); also elsewhere on the board
+3.3VA: C901.2, C902.2, U902.1 (AVDD); also elsewhere on the board
/cpld1/osd.BCLK: U902.22 (BCLK); also elsewhere on the board
/cpld1/osd.MCLK: U902.20 (GPIO1); also elsewhere on the board
/cpld1/osd.MISO: R906.1; also elsewhere on the board
/cpld1/osd.MOSI: U902.17 (SCL_MOSI); also elsewhere on the board
/cpld1/osd.NSS: U902.18 (SDA_SSZ); also elsewhere on the board
/cpld1/osd.SCK: U902.16 (ADDR0_SCLK); also elsewhere on the board
/cpld1/osd.WCLK: U902.23 (FSYNC); also elsewhere on the board
/cpld1/osd.data: R908.1; also elsewhere on the board
/cpld1/osd.nPh0: U901.1 (*1OE), U904.1 (*1OE); also elsewhere on the board
/cpld1/osd.nPh1: U901.4 (*2OE), U904.4 (*2OE); also elsewhere on the board
/cpld1/osd.nPh2: U901.10 (*3OE), U904.10 (*3OE); also elsewhere on the board
/cpld1/osd.nPh3: U901.13 (*4OE), U904.13 (*4OE); also elsewhere on the board
/cpld1/osd.nPh4: U903.1 (*1OE), U905.1 (*1OE); also elsewhere on the board
/cpld1/osd.nPh5: U903.4 (*2OE), U905.4 (*2OE); also elsewhere on the board
/cpld1/osd.nPh6: U903.10 (*3OE), U905.10 (*3OE); also elsewhere on the board
/cpld1/osd.nPh7: U903.13 (*4OE), U905.13 (*4OE); also elsewhere on the board
/microcontroller/adcReset: U902.14 (SHDNZ); also elsewhere on the board
/osd1/rfIn+: C925.1; also elsewhere on the board
/osd1/rfIn-: C945.1; also elsewhere on the board
/osd1/swIn+: R903.2, R907.2, U901.2 (1A), U901.5 (2A), U901.9 (3A), U901.12 (4A), U903.2 (1A), U903.5 (2A), U903.9 (3A), U903.12 (4A)
/osd1/swIn-: R913.2, R914.2, U904.2 (1A), U904.5 (2A), U904.9 (3A), U904.12 (4A), U905.2 (1A), U905.5 (2A), U905.9 (3A), U905.12 (4A)
GND: C901.1, C902.1, C903.2, C904.2, C905.2, C908.2, C909.2, C911.2, C912.2, C913.2, C914.2, C915.2, C916.1, C917.2, C918.2, C920.2, C922.2, C923.2, C926.2, C927.2, C928.2, C929.2, C930.2, C932.2, C935.2, C936.2, C937.2, C941.2, C942.2, C943.2, C944.2, U901.7 (GND), U902.4 (AVSS), U902.25 (EPAD), U903.7 (GND), U904.7 (GND), U905.7 (GND); also elsewhere on the board
unnamed: C906.2, R901.1
unnamed: C910.2, R902.1
unnamed: C919.2, R904.1
unnamed: C924.2, R905.1
unnamed: C925.2, R907.1
unnamed: C931.2, R909.1
unnamed: C934.2, R910.1
unnamed: C938.2, R911.1
unnamed: C940.2, R912.1
unnamed: C945.2, R914.1
unnamed: C906.1, C915.1, U901.3 (1B), U905.3 (1B)
unnamed: C917.1, C931.1, U901.6 (2B), U905.6 (2B)
unnamed: C919.1, C920.1, U901.8 (3B), U905.8 (3B)
unnamed: C923.1, C938.1, U901.11 (4B), U905.11 (4B)
unnamed: R906.2, U902.15 (ADDR1_MISO)
unnamed: C904.1, C905.1, U902.2 (AREG)
unnamed: C911.1, C912.1, U902.24 (DREG)
unnamed: C907.2, C913.1, R902.2, U902.7 (IN1M_GPO1)
unnamed: C907.1, C914.1, R901.2, U902.6 (IN1P_GPI1)
unnamed: C921.2, C927.1, R905.2, U902.9 (IN2M_GPO2)
unnamed: C921.1, C928.1, R904.2, U902.8 (IN2P_GPI2)
unnamed: C933.2, C935.1, R910.2, U902.11 (IN3M_GPO3)
unnamed: C933.1, C936.1, R909.2, U902.10 (IN3P_GPI3)
unnamed: C939.2, C941.1, R912.2, U902.13 (IN4M_GPO4)
unnamed: C939.1, C942.1, R911.2, U902.12 (IN4P_GPI4)
unnamed: R908.2, U902.21 (SDOUT)
unnamed: C916.2, U902.3 (VREF)
unnamed: C910.1, C926.1, U903.3 (1B), U904.3 (1B)
unnamed: C929.1, C934.1, U903.6 (2B), U904.6 (2B)
unnamed: C924.1, C930.1, U903.8 (3B), U904.8 (3B)
unnamed: C932.1, C940.1, U903.11 (4B), U904.11 (4B)

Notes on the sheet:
Length match the rf39-inner traces from switch to cap and route at 39 ohms.

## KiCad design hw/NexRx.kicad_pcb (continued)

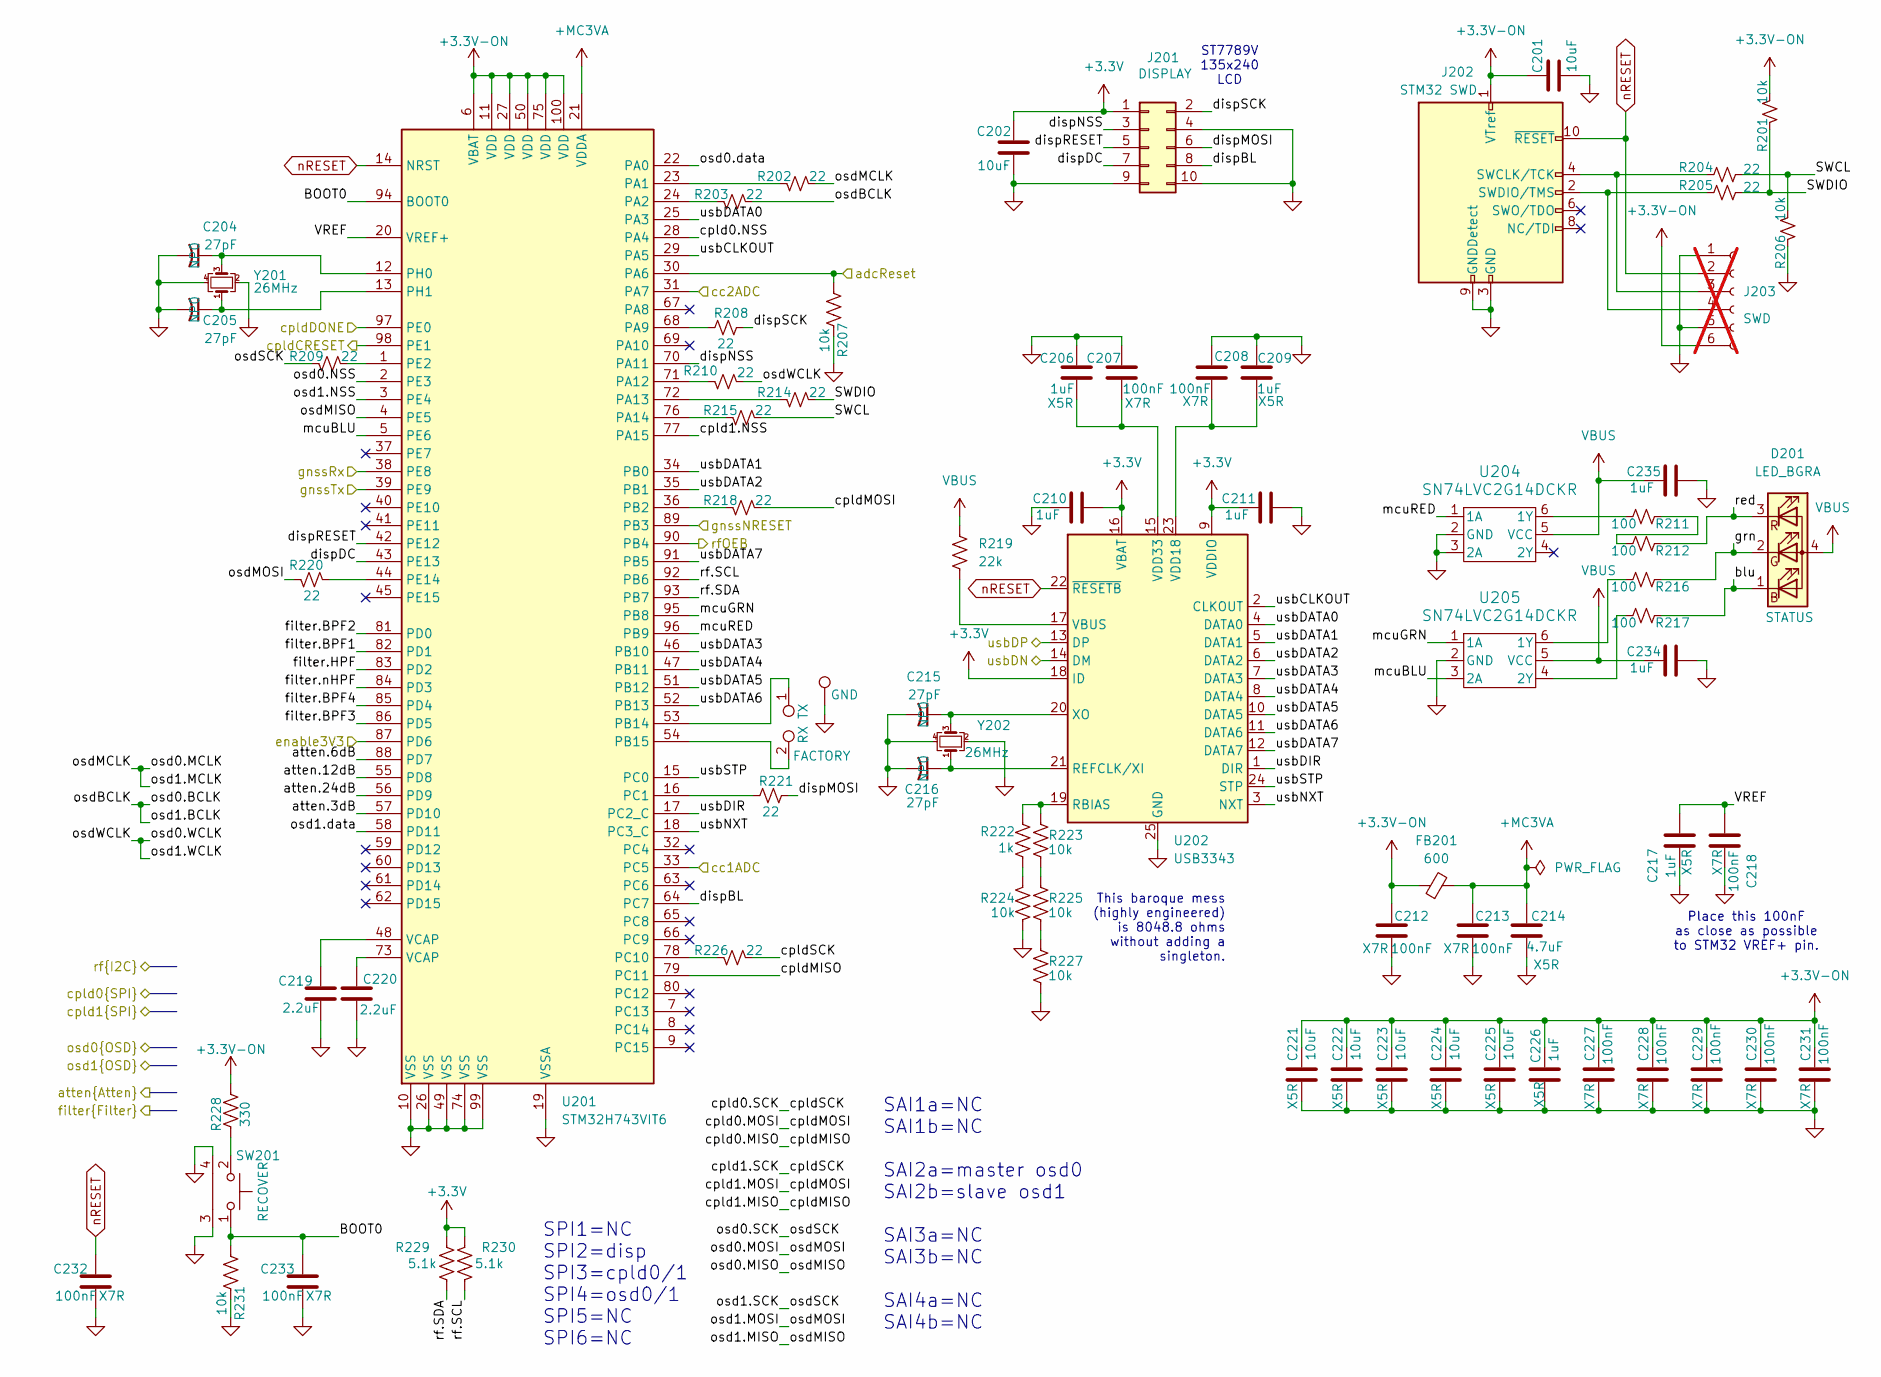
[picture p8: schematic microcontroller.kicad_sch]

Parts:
C201: 10uF; C_0402_1005Metric; MPN CL05A106MP6NUN8; LCSC_PN C76991
C202, C221, C222, C223, C224, C225: 10uF; C_0402_1005Metric; Mouser Part Number 187-CL05A106MP6NUN8
C204: 27pF; C_0402_1005Metric; MPN 04023A270JAT2A; LCSC_PN C1557
C205, C215, C216: 27pF; C_0402_1005Metric; MPN 04023A270JAT2A; Mouser Part Number 581-04023A270JAT2A
C206, C209, C210, C211, C234, C235: 1uF; C_0402_1005Metric; Mouser Part Number 81-GRM155R61E105MA2D
C207, C208, C212, C213, C231: 100nF; C_0402_1005Metric; MPN GCM155R71H104KE02D; LCSC_PN C307331
C214: 4.7uF; C_0402_1005Metric; MPN CM05X5R475M10AH; LCSC_PN C23733
C217, C226: 1uF; C_0402_1005Metric; MPN GRM155R61E105MA12D; LCSC_PN C77009
C218, C227, C228, C229, C230, C232, C233: 100nF; C_0402_1005Metric; Mouser Part Number 81-GCM155R71H104KE2D
C219, C220: 2.2uF; C_0402_1005Metric; MPN TMK105CBJ225MV-F; LCSC_PN C12530
D201: LED_BGRA; WL-SFCD_0606; Mouser_PN 941-UHD1AA3K3E3V53Z3
FB201: 600; L_0603_1608Metric; MPN MI0603J601R-10; LCSC_PN C1006
J201: Conn_01x08_Pin; IDC-Header_2x05_P2.54mm_Vertical_SMD; LCSC_PN C5371818
J202: FTSH-105-01-L-DV-K; FTSH10501LDVK; MPN FTSH-105-01-L-DV-K; LCSC_PN C5155080
J203: SWD; PinHeader_1x06_P2.54mm_Vertical; not fitted
R201, R206, R207, R223, R224, R225, R227, R231: 10k; R_0402_1005Metric; MPN RT0402BRD0710KL; LCSC_PN C283961
R202, R203: 22; R_0402_1005Metric; MPN 560112110216; LCSC_PN C25092
R204, R205, R208, R209, R210, R214, R215, R218, R220, R221, R226: 22; R_0402_1005Metric; MPN 560112110216; JLCPCBpn C4258780
R211, R212, R216, R217: 100; R_0402_1005Metric; MPN MCS04020C1000FE000; Mouser Part Number 594-MCS04020C1000FE0
R219: 22k; R_0402_1005Metric; LCSC_PN C25768
R222: 1k; R_0402_1005Metric; MPN RP0402FRE071KL; LCSC_PN C11702
R228: 330; R_0402_1005Metric; MPN RC0402JR-7D330RL; LCSC_PN C25104
R229, R230: 5.1k; R_0402_1005Metric; MPN AC0402FR-7W5K1L; LCSC_PN C854378
SW201: Push button switch; SW_TS11-674-43-BK-100-RA-D; LCSC_PN C7402553
TP201: GND; TestPoint_THTPad_1.0x1.0mm_Drill0.5mm
TP202: FACTORY; TestPoint_2Pads_Pitch2.54mm_Drill0.8mm
U201: STM32H743VIT6; LQFP-100_14x14mm_P0.5mm; MPN STM32H743VIT6; LCSC_PN C114409
U202: USB3343; QFN-24-1EP_4x4mm_P0.5mm_EP2.6x2.6mm; MPN USB3343-CP-TR; LCSC_PN C633347
U204, U205: SN74LVC2G14DCKR; SOIC_G14DCK3_TEX; LCSC_PN C37361
Y201, Y202: 26MHz; Crystal_SMD_2520-4Pin_2.5x2.0mm; MPN E2X260181G01; LCSC_PN C2149229

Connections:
+3.3V: C202.2, C210.2, C211.1, J201.1, R229.1, R230.1, U202.9 (VDDIO), U202.16 (VBAT), U202.18 (ID); also elsewhere on the board
+3.3V-ON: C201.2, C212.1, C221.1, C222.1, C223.1, C224.1, C225.1, C226.1, C227.1, C228.1, C229.1, C230.1, C231.1, FB201.1, J202.1 (VTref), J203.6, R201.1, R228.1, U201.6 (VBAT), U201.11 (VDD), U201.27 (VDD), U201.50 (VDD), U201.75 (VDD), U201.100 (VDD); also elsewhere on the board
+MC3VA: C213.1, C214.1, FB201.2, U201.21 (VDDA)
/Clock/rf.SCL: R230.2, U201.92 (PB6); also elsewhere on the board
/Clock/rf.SDA: R229.2, U201.93 (PB7); also elsewhere on the board
/Clock/rfOEB: U201.90 (PB4); also elsewhere on the board
/Filters/en.BPF1: U201.82 (PD1); also elsewhere on the board
/Filters/en.BPF2: U201.81 (PD0); also elsewhere on the board
/Filters/en.BPF3: U201.86 (PD5); also elsewhere on the board
/Filters/en.BPF4: U201.85 (PD4); also elsewhere on the board
/Filters/en.HPF: U201.83 (PD2); also elsewhere on the board
/Filters/en.nHPF: U201.84 (PD3); also elsewhere on the board
/Power/cc1ADC: U201.33 (PC5); also elsewhere on the board
/Power/cc2ADC: U201.31 (PA7); also elsewhere on the board
/Power/enable3V3: U201.87 (PD6); also elsewhere on the board
/Power/usbDN: U202.14 (DM); also elsewhere on the board
/Power/usbDP: U202.13 (DP); also elsewhere on the board
/atten.3dB: U201.57 (PD10); also elsewhere on the board
/atten.6dB: U201.88 (PD7); also elsewhere on the board
/atten.12dB: U201.55 (PD8); also elsewhere on the board
/atten.24dB: U201.56 (PD9); also elsewhere on the board
/cpld0/cpld.NSS: U201.28 (PA4); also elsewhere on the board
/cpld0/cpldCRESET: U201.98 (PE1); also elsewhere on the board
/cpld0/cpldDONE: U201.97 (PE0); also elsewhere on the board
/cpld0/osd.NSS: U201.2 (PE3); also elsewhere on the board
/cpld0/osd.data: U201.22 (PA0); also elsewhere on the board
/cpld1/cpld.MISO: U201.79 (PC11); also elsewhere on the board
/cpld1/cpld.MOSI: R218.1; also elsewhere on the board
/cpld1/cpld.NSS: U201.77 (PA15); also elsewhere on the board
/cpld1/cpld.SCK: R226.1; also elsewhere on the board
/cpld1/osd.BCLK: R203.1; also elsewhere on the board
/cpld1/osd.MCLK: R202.1; also elsewhere on the board
/cpld1/osd.MISO: U201.4 (PE5); also elsewhere on the board
/cpld1/osd.MOSI: R220.2; also elsewhere on the board
/cpld1/osd.NSS: U201.3 (PE4); also elsewhere on the board
/cpld1/osd.SCK: R209.2; also elsewhere on the board
/cpld1/osd.WCLK: R210.2; also elsewhere on the board
/cpld1/osd.data: U201.58 (PD11); also elsewhere on the board
/microcontroller/BOOT0: C233.1, R231.1, SW201.1, U201.94 (BOOT0)
/microcontroller/SWCL: R204.2, R206.1, R215.1
/microcontroller/SWDIO: R201.2, R205.2, R214.1
/microcontroller/VREF: C217.1, C218.1, U201.20 (VREF+)
/microcontroller/adcReset: R207.1, U201.30 (PA6); also elsewhere on the board
/microcontroller/blu: D201.1 (BK), R217.1
/microcontroller/dispBL: J201.8, U201.64 (PC7)
/microcontroller/dispDC: J201.7, U201.43 (PE13)
/microcontroller/dispMOSI: J201.6, R221.2
/microcontroller/dispNSS: J201.3, U201.70 (PA11)
/microcontroller/dispRESET: J201.5, U201.42 (PE12)
/microcontroller/dispSCK: J201.2, R208.2
/microcontroller/gnssNRESET: U201.89 (PB3); also elsewhere on the board
/microcontroller/gnssRx: U201.38 (PE8); also elsewhere on the board
/microcontroller/gnssTx: U201.39 (PE9); also elsewhere on the board
/microcontroller/grn: D201.2 (GK), R216.1
/microcontroller/mcuBLU: U201.5 (PE6), U205.3 (2A)
/microcontroller/mcuGRN: U201.95 (PB8), U205.1 (1A)
/microcontroller/mcuRED: U201.96 (PB9), U204.1 (1A)
/microcontroller/red: D201.3 (RK), R212.1
/microcontroller/usbCLKOUT: U201.29 (PA5), U202.2 (CLKOUT)
/microcontroller/usbDATA0: U201.25 (PA3), U202.4 (DATA0)
/microcontroller/usbDATA1: U201.34 (PB0), U202.5 (DATA1)
/microcontroller/usbDATA2: U201.35 (PB1), U202.6 (DATA2)
/microcontroller/usbDATA3: U201.46 (PB10), U202.7 (DATA3)
/microcontroller/usbDATA4: U201.47 (PB11), U202.8 (DATA4)
/microcontroller/usbDATA5: U201.51 (PB12), U202.10 (DATA5)
/microcontroller/usbDATA6: U201.52 (PB13), U202.11 (DATA6)
/microcontroller/usbDATA7: U201.91 (PB5), U202.12 (DATA7)
/microcontroller/usbDIR: U201.17 (PC2_C), U202.1 (DIR)
/microcontroller/usbNXT: U201.18 (PC3_C), U202.3 (NXT)
/microcontroller/usbSTP: U201.15 (PC0), U202.24 (STP)
GND: C201.1, C202.1, C204.2, C205.2, C206.2, C207.1, C208.1, C209.2, C210.1, C211.2, C212.2, C213.2, C214.2, C215.2, C216.2, C217.2, C218.2, C219.2, C220.2, C221.2, C222.2, C223.2, C224.2, C225.2, C226.2, C227.2, C228.2, C229.2, C230.2, C231.2, C232.2, C233.2, C234.2, C235.2, J201.4, J201.9, J201.10, J202.3 (GND), J202.5 (GND), J202.9 (GNDDetect), J203.1, J203.5, R206.2, R207.2, R224.2, R227.2, R231.2, SW201.3 (GND), SW201.4 (GND), TP201.1, U201.10 (VSS), U201.19 (VSSA), U201.26 (VSS), U201.49 (VSS), U201.74 (VSS), U201.99 (VSS), U202.25 (GND), U204.2 (GND), U204.3 (2A), U205.2 (GND), Y201.2, Y201.4, Y202.2, Y202.4; also elsewhere on the board
unnamed: C219.1, U201.48 (VCAP)
unnamed: C220.1, U201.73 (VCAP)
unnamed: J202.4 (SWCLK/TCK), J203.3, R204.1
unnamed: J202.2 (SWDIO/TMS), J203.4, R205.1
unnamed: R211.1, R212.2
unnamed: R222.2, R224.1
unnamed: R223.2, R225.1
unnamed: R225.2, R227.1
unnamed: R228.2, SW201.2
unnamed: R202.2, U201.23 (PA1)
unnamed: R203.2, U201.24 (PA2)
unnamed: R208.1, U201.68 (PA9)
unnamed: R210.1, U201.71 (PA12)
unnamed: R214.2, U201.72 (PA13)
unnamed: R215.2, U201.76 (PA14)
unnamed: R218.2, U201.36 (PB2)
unnamed: TP202.1, U201.53 (PB14)
unnamed: TP202.2, U201.54 (PB15)
unnamed: R221.1, U201.16 (PC1)
unnamed: R226.2, U201.78 (PC10)
unnamed: R209.1, U201.1 (PE2)
unnamed: R220.1, U201.44 (PE14)
unnamed: C204.1, U201.12 (PH0), Y201.3
unnamed: C205.1, U201.13 (PH1), Y201.1
unnamed: R222.1, R223.1, U202.19 (RBIAS)
unnamed: C216.1, U202.21 (REFCLK/XI), Y202.1
unnamed: R219.2, U202.17 (VBUS)
unnamed: C208.2, C209.1, U202.23 (VDD18)
unnamed: C206.1, C207.2, U202.15 (VDD33)
unnamed: C215.1, U202.20 (XO), Y202.3
unnamed: R211.2, U204.6 (1Y)
unnamed: R216.2, U205.6 (1Y)
unnamed: R217.2, U205.4 (2Y)
VBUS: C234.1, C235.1, D201.4 (A), R219.1, U204.5 (VCC), U205.5 (VCC); also elsewhere on the board
nRESET: C232.1, J202.10 (~RESET), J203.2, U201.14 (NRST), U202.22 (~RESETB)

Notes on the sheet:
SPI1=NC SPI2=disp SPI3=cpld0/1 SPI4=osd0/1 SPI5=NC SPI6=NC
This baroque mess (highly engineered) is 8048.8 ohms without adding a singleton.
SAI1a=NC SAI1b=NC SAI2a=master osd0 SAI2b=slave osd1 SAI3a=NC SAI3b=NC SAI4a=NC SAI4b=NC
Place this 100nF as close as possible to STM32 VREF+ pin.
ST7789V 135x240 LCD

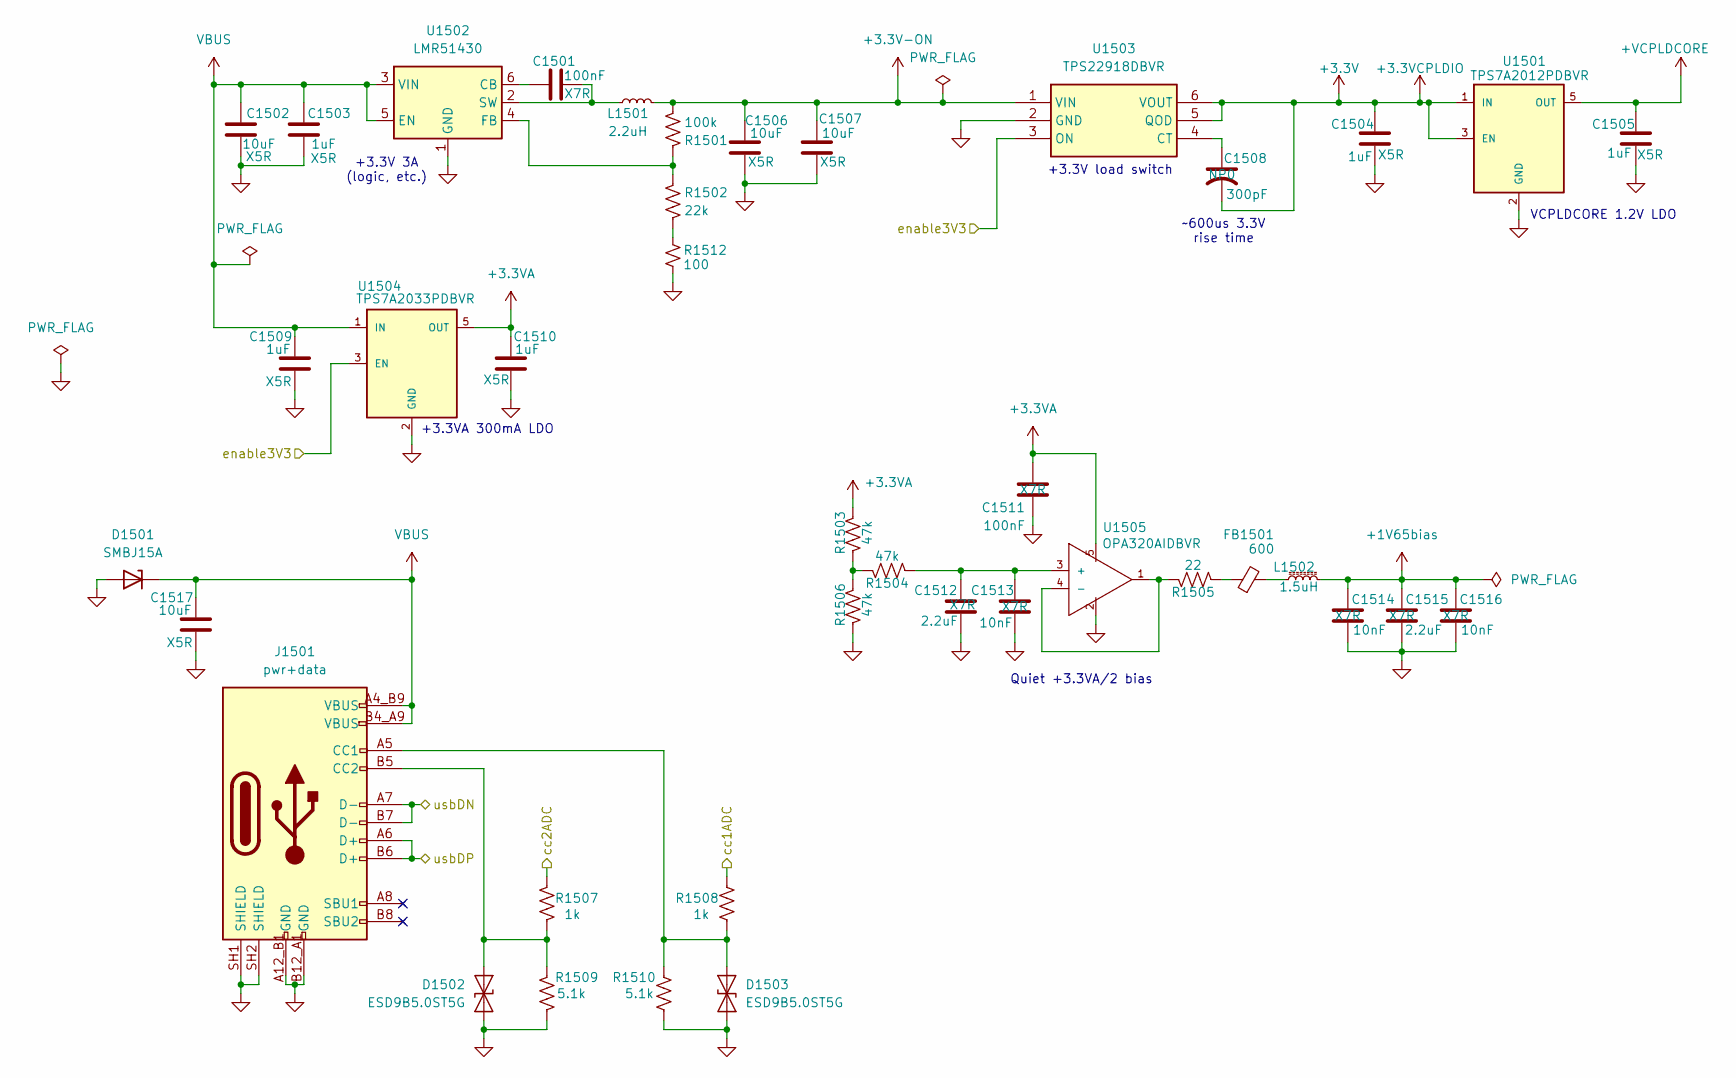
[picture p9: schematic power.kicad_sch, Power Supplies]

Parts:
C1501, C1511: 100nF; C_0402_1005Metric; MPN GCM155R71H104KE02D; LCSC_PN C307331
C1502, C1517: 10uF; C_0603_1608Metric; MPN CL10A106MA8NRWC; LCSC_PN C76614
C1503, C1505: 1uF; C_0402_1005Metric; MPN GRM155R61E105MA12D; LCSC_PN C77009
C1504, C1509, C1510: 1uF; C_0402_1005Metric; Mouser Part Number 81-GRM155R61E105MA2D
C1506, C1507: 10uF; C_0603_1608Metric; Mouser Part Number 187-CL10A106MA8NRWC
C1508: 300pF; C_0402_1005Metric; Mouser Part Number 80-C0402C301J3GACTU
C1512, C1515: 2.2uF; C_0402_1005Metric; MPN TMK105CBJ225MV-F; LCSC_PN C12530
C1513, C1514, C1516: 10nF; C_0402_1005Metric; MPN CC0402KRX5R8BB103; LCSC_PN C15195
D1501: SMBJ15A; D_SMB; MPN 1.0SMBJ15A-AQ; LCSC_PN C83846
D1502, D1503: ESD9B5.0ST5G; D_SOD-923; MPN ESD9B5.0ST5G; LCSC_PN C111566
FB1501: 600; L_0603_1608Metric; MPN MI0603J601R-10; LCSC_PN C1006
J1501: pwr+data; SAMESKY_UJ20-C-H-G-SMT-1-P16-TR; MPN UJ20-C-H-G-SMT-1-P16-TR; LCSC_PN C45082766
L1501: 2.2uH; L_0805_2012Metric; MPN 74479275222; LCSC_PN C341781
L1502: 1.5uH; L_0603_1608Metric; LCSC_PN C73201
R1501: 100k; R_0402_1005Metric; MPN RP0402BRD07100KL; LCSC_PN C25741
R1502: 22k; R_0402_1005Metric; LCSC_PN C25768
R1503, R1504, R1506: 47k; R_0402_1005Metric; MPN RC0402FR-7D47KL; JLCPCBpn C854337
R1505: 22; R_0402_1005Metric; MPN 560112110216; LCSC_PN C25092
R1507, R1508: 1k; R_0402_1005Metric; MPN RP0402FRE071KL; LCSC_PN C11702
R1509, R1510: 5.1k; R_0402_1005Metric; MPN AC0402FR-7W5K1L; LCSC_PN C854378
R1512: 100; R_0402_1005Metric; MPN MCS04020C1000FE000; Mouser Part Number 594-MCS04020C1000FE0
U1501: TPS7A2012PDBVR; DBV0005A-MFG; MPN TPS7A2012PDBVR; LCSC_PN C2864597
U1502: LMR51430; SOT-23-6; MPN MR51430YDDCR; LCSC_PN C5210749
U1503: TPS22918DBVR; SOT95P280X145-6N; MPN TPS22918DBVR; LCSC_PN C131941
U1504: TPS7A2033PDBVR; DBV0005A-MFG; MPN TPS7A2033PDBVR; LCSC_PN C2862740
U1505: OPA320AIDBVR; SOT95P280X145-5N; MPN OPA320AIDBVR; Mouser Part Number 595-OPA320AIDBVR

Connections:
+1V65bias: C1514.1, C1515.1, C1516.1, L1502.2; also elsewhere on the board
+3.3V: C1504.1, C1508.2, U1501.1 (IN), U1501.3 (EN), U1503.5 (QOD), U1503.6 (VOUT); also elsewhere on the board
+3.3V-ON: C1506.1, C1507.1, L1501.2, R1501.2, U1503.1 (VIN); also elsewhere on the board
+3.3VA: C1510.1, C1511.1, R1503.2, U1504.5 (OUT), U1505.5; also elsewhere on the board
+VCPLDCORE: C1505.1, U1501.5 (OUT); also elsewhere on the board
/Power/cc1ADC: R1508.1; also elsewhere on the board
/Power/cc2ADC: R1507.1; also elsewhere on the board
/Power/enable3V3: U1503.3 (ON), U1504.3 (EN); also elsewhere on the board
/Power/usbDN: J1501.A7 (D-), J1501.B7 (D-); also elsewhere on the board
/Power/usbDP: J1501.A6 (D+), J1501.B6 (D+); also elsewhere on the board
GND: C1502.2, C1503.2, C1504.2, C1505.2, C1506.2, C1507.2, C1509.2, C1510.2, C1511.2, C1512.2, C1513.2, C1514.2, C1515.2, C1516.2, C1517.2, D1501.2 (A), D1502.1 (A1), D1503.1 (A1), J1501.A12_B1 (GND), J1501.B12_A1 (GND), J1501.SH1 (SHIELD), J1501.SH2 (SHIELD), R1506.1, R1509.2, R1510.2, R1512.2, U1501.2 (GND), U1502.1 (GND), U1503.2 (GND), U1504.2 (GND), U1505.2; also elsewhere on the board
unnamed: D1502.2 (A2), J1501.B5 (CC2), R1507.2, R1509.1
unnamed: D1503.2 (A2), J1501.A5 (CC1), R1508.2, R1510.1
unnamed: FB1501.1, R1505.1
unnamed: FB1501.2, L1502.1
unnamed: R1502.1, R1512.1
unnamed: R1503.1, R1504.2, R1506.2
unnamed: C1501.1, U1502.6 (CB)
unnamed: R1501.1, R1502.2, U1502.4 (FB)
unnamed: C1501.2, L1501.1, U1502.2 (SW)
unnamed: C1508.1, U1503.4 (CT)
unnamed: C1512.1, C1513.1, R1504.1, U1505.3 (+)
unnamed: R1505.2, U1505.1, U1505.4 (-)
VBUS: C1502.1, C1503.1, C1509.1, C1517.1, D1501.1 (K), J1501.A4_B9 (VBUS), J1501.B4_A9 (VBUS), U1502.3 (VIN), U1502.5 (EN), U1504.1 (IN); also elsewhere on the board

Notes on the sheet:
~600us 3.3V rise time
VCPLDCORE 1.2V LDO
+3.3V load switch
Quiet +3.3VA/2 bias
+3.3V 3A (logic, etc.)
+3.3VA 300mA LDO

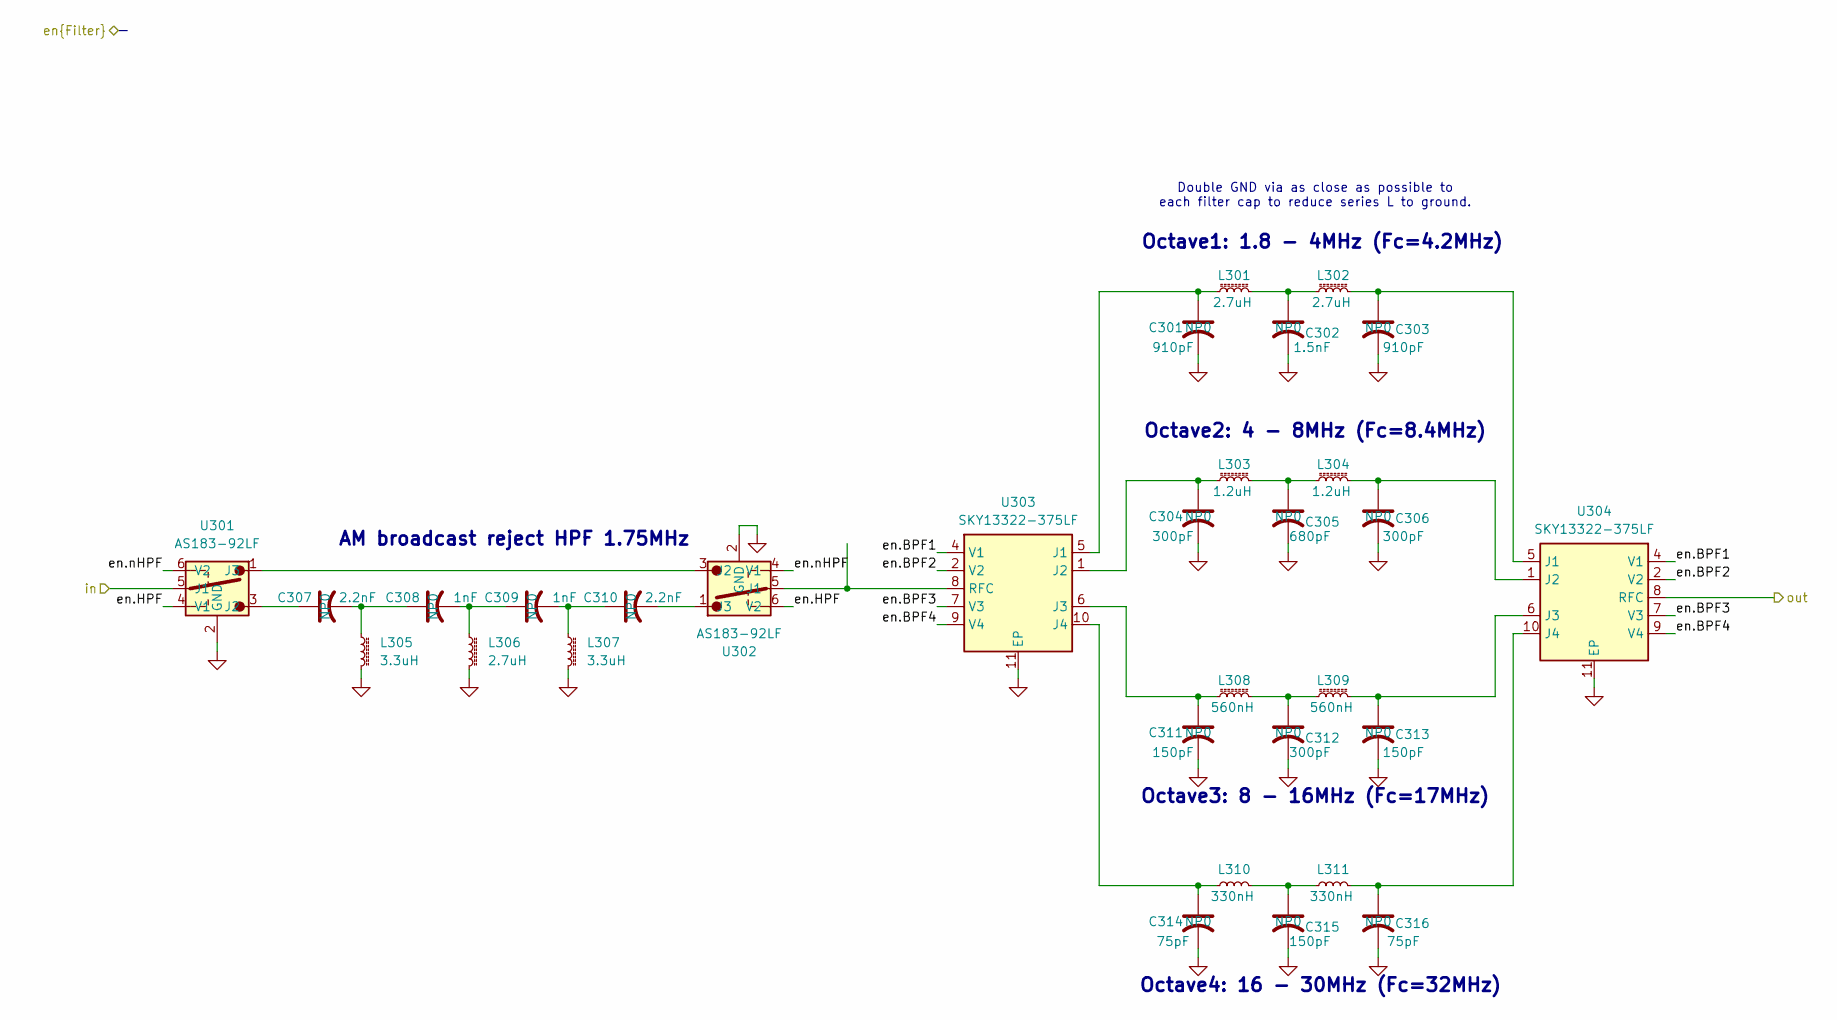
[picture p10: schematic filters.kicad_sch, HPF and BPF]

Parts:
C301, C303: 910pF; C_0603_1608Metric; Mouser Part Number 791-0603N911J250CT
C302: 1.5nF; C_0402_1005Metric; Mouser Part Number 80-C0402C152J3GACAUTO
C304, C306, C312: 300pF; C_0402_1005Metric; Mouser Part Number 80-C0402C301J3GACTU
C305: 680pF; C_0402_1005Metric; Mouser Part Number 81-GRT1555C1E681JA02J
C307, C310: 2.2nF; C_0402_1005Metric; Mouser Part Number 80-C0402C222K3GECTU
C308, C309: 1nF; C_0402_1005Metric; Mouser Part Number 81-GRT1555C1E102JA02J
C311, C313, C315: 150pF; C_0402_1005Metric; Mouser Part Number C0402C151J3GACTU
C314, C316: 75pF; C_0402_1005Metric; Mouser Part Number 80-CBR04C750G3GAC
L301, L302, L306: 2.7uH; L_1812_4532Metric; Mouser Part Number 994-1812CS-272XJRC
L303, L304: 1.2uH; L_1812_4532Metric; Mouser Part Number 994-1812CS-122XJRC
L305, L307: 3.3uH; L_1812_4532Metric; Mouser Part Number 994-1812CS-332XJRC
L308, L309: 560nH; L_1008_2520Metric_Pad1.43x2.20mm_HandSolder-keepout; Mouser Part Number 994-1008CS-561XJRC
L310, L311: 330nH; L_Coilcraft_2929SQ-331; MPN 2929SQ-331JEC; LCSC_PN C19271242
U301, U302: AS183-92LF; SOT65P220X110-6N; MPN AS183-92LF; LCSC_PN C2654768
U303, U304: SKY13322-375LF; SON50P200X300X50-11N-D; Mouser Part Number 873-SKY13322-375LF

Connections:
/Filters/en.BPF1: U303.4 (V1), U304.4 (V1); also elsewhere on the board
/Filters/en.BPF2: U303.2 (V2), U304.2 (V2); also elsewhere on the board
/Filters/en.BPF3: U303.7 (V3), U304.7 (V3); also elsewhere on the board
/Filters/en.BPF4: U303.9 (V4), U304.9 (V4); also elsewhere on the board
/Filters/en.HPF: U301.4 (V1), U302.6 (V2); also elsewhere on the board
/Filters/en.nHPF: U301.6 (V2), U302.4 (V1); also elsewhere on the board
/Filters/in: U301.5 (J1); also elsewhere on the board
/Filters/out: U304.8 (RFC); also elsewhere on the board
GND: C301.2, C302.2, C303.2, C304.2, C305.2, C306.2, C311.2, C312.2, C313.2, C314.2, C315.2, C316.2, L305.2, L306.2, L307.2, U301.2 (GND), U302.2 (GND), U303.11 (EP), U304.11 (EP); also elsewhere on the board
unnamed: C302.1, L301.2, L302.1
unnamed: C305.1, L303.2, L304.1
unnamed: C307.2, C308.1, L305.1
unnamed: C308.2, C309.1, L306.1
unnamed: C309.2, C310.1, L307.1
unnamed: C312.1, L308.2, L309.1
unnamed: C315.1, L310.2, L311.1
unnamed: C307.1, U301.3 (J2)
unnamed: U301.1 (J3), U302.3 (J2)
unnamed: U302.5 (J1), U303.8 (RFC)
unnamed: C310.2, U302.1 (J3)
unnamed: C301.1, L301.1, U303.5 (J1)
unnamed: C304.1, L303.1, U303.1 (J2)
unnamed: C311.1, L308.1, U303.6 (J3)
unnamed: C314.1, L310.1, U303.10 (J4)
unnamed: C303.1, L302.2, U304.5 (J1)
unnamed: C306.1, L304.2, U304.1 (J2)
unnamed: C313.1, L309.2, U304.6 (J3)
unnamed: C316.1, L311.2, U304.10 (J4)

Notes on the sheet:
Double GND via as close as possible to each filter cap to reduce series L to ground.
Octave3: 8 - 16MHz (Fc=17MHz)
Octave1: 1.8 - 4MHz (Fc=4.2MHz)
AM broadcast reject HPF 1.75MHz
Octave2: 4 - 8MHz (Fc=8.4MHz)
Octave4: 16 - 30MHz (Fc=32MHz)

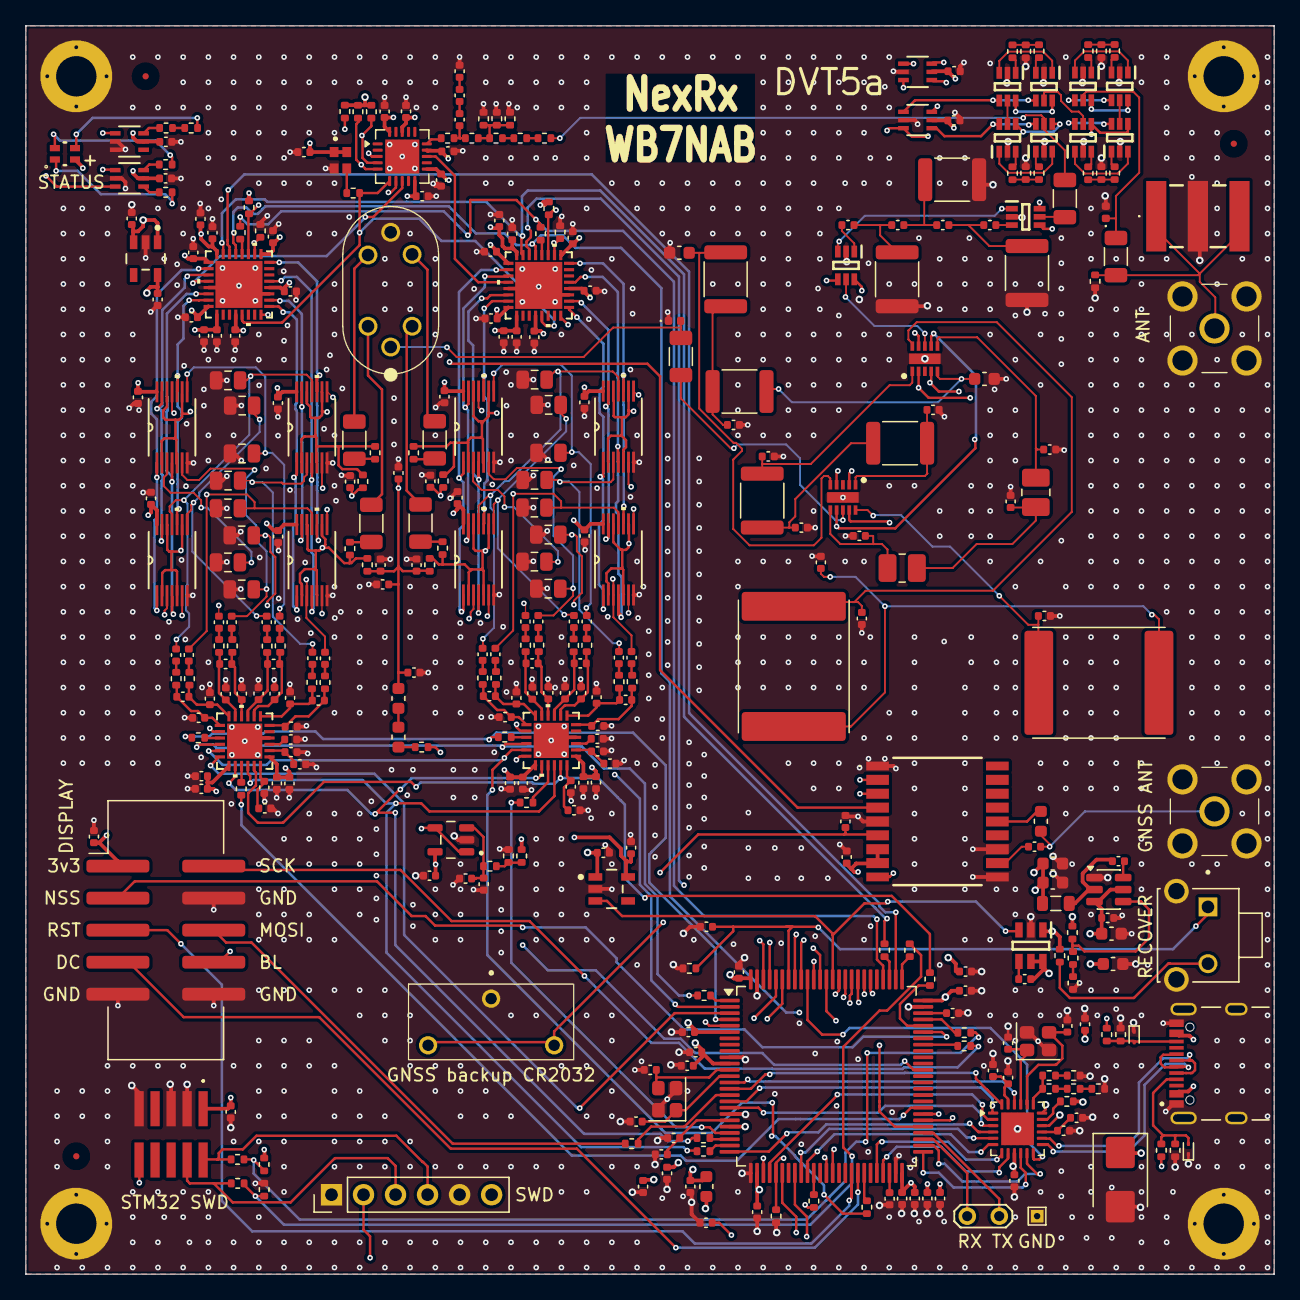
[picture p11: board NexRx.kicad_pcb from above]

Board: 6 copper layers, 99.0 x 99.0 mm, 371 parts (0 on the bottom side), 274 nets.

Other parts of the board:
R501, R502: 16.5; R_0402_1005Metric
R503: 66.5; R_0402_1005Metric
R601, R602: 30.1; R_0402_1005Metric
R603: 26.7; R_0402_1005Metric
R701, R702: 44.2; R_0402_1005Metric
R703: 6.34; R_0402_1005Metric

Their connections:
GND: R503.2, R603.2, R703.2; also elsewhere on the board
unnamed: R501.1, R502.2, R503.1
unnamed: R601.1, R602.2, R603.1
unnamed: R701.1, R702.2, R703.1
unnamed 210: R501.2; also elsewhere on the board
unnamed 212: R502.1; also elsewhere on the board
unnamed 213: R601.2; also elsewhere on the board
unnamed 215: R602.1; also elsewhere on the board
unnamed 216: R701.2; also elsewhere on the board
unnamed 218: R702.1; also elsewhere on the board

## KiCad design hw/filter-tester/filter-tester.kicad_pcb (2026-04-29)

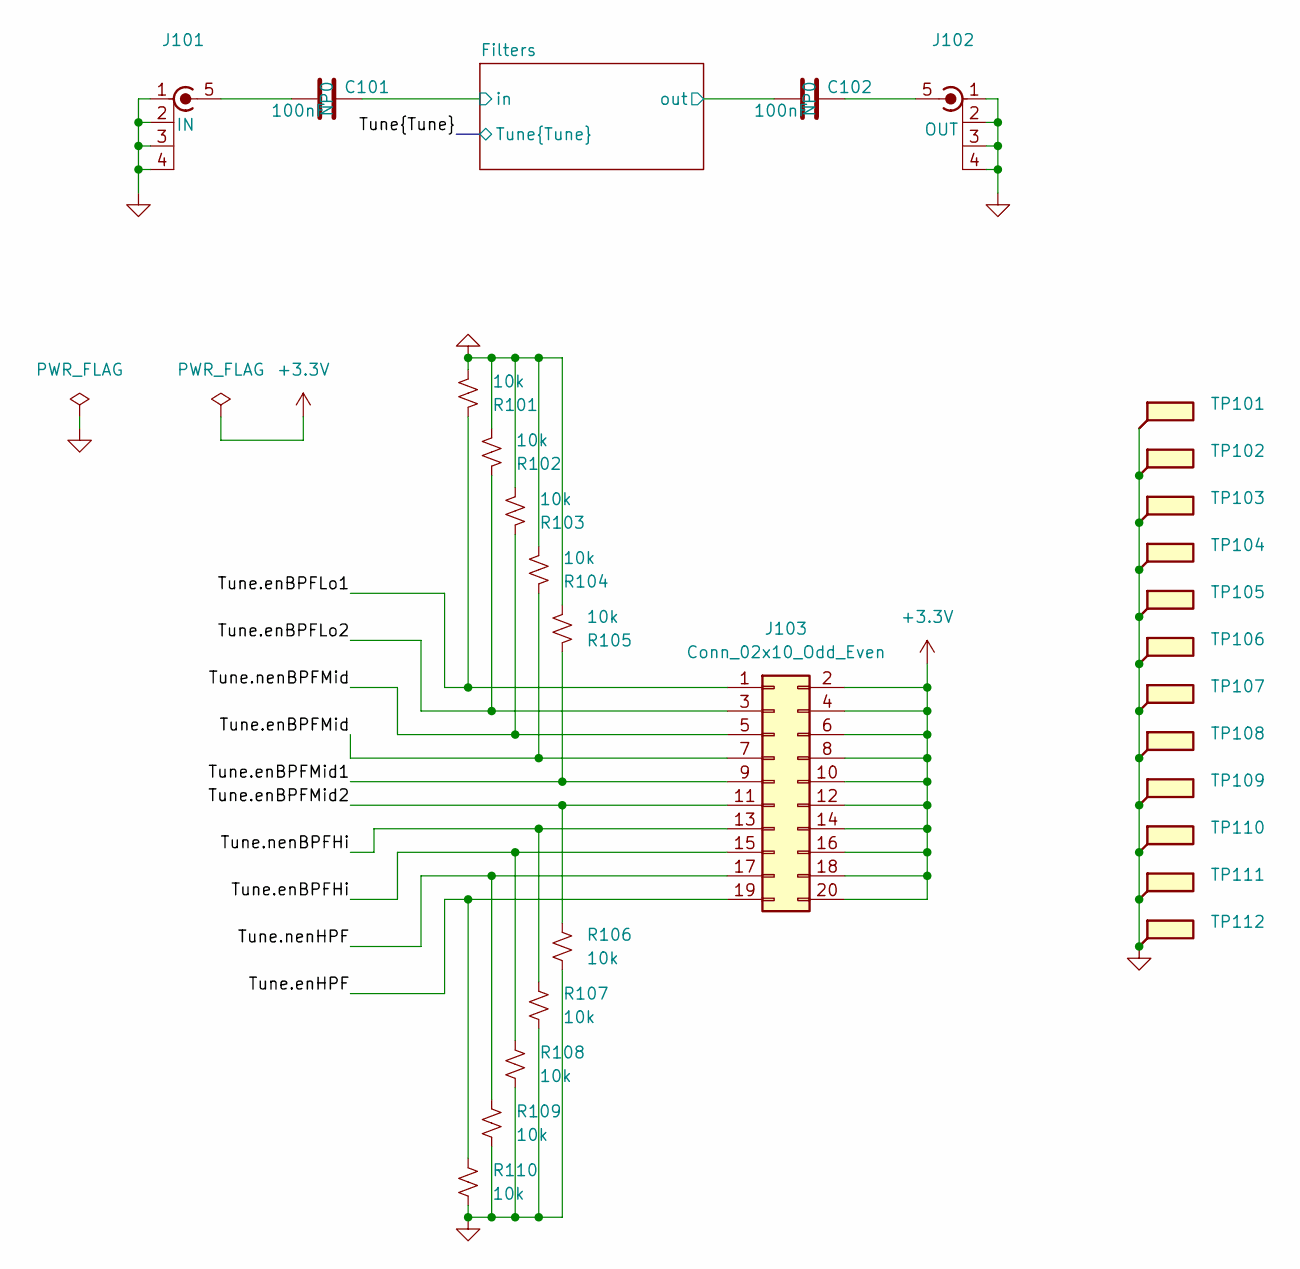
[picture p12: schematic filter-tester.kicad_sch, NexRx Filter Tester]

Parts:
C101, C102: 100nF; C_1206_3216Metric; MPN GRM3195C2A104JA01D; LCSC_PN C170182
J101, J102: SMA; 733910083; MPN 73391-0083; Mouser_PN 538-73391-0083
J103: Conn_02x10_Odd_Even; PinHeader_2x10_P2.54mm_Vertical_SMD; Mouser_PN 855-M20-8761046
R101, R102, R103, R104, R105, R106, R107, R108, R109, R110: 10k; R_0603_1608Metric; MPN RC0402JR-7D10KL; Mouser_PN 603-RC0402JR-7D10KL
TP101, TP102, TP103, TP104, TP105, TP106, TP107, TP108, TP109, TP110, TP111, TP112: GND; TestPoint_Pad_1.0x1.0mm

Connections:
+3.3V: J103.2, J103.4, J103.6, J103.8, J103.10, J103.12, J103.14, J103.16, J103.18, J103.20
/Filters/in: C101.1; also elsewhere on the board
/Filters/out: C102.2; also elsewhere on the board
/Tune.enBPFHi: J103.15, R108.1; also elsewhere on the board
/Tune.enBPFLo1: J103.1, R101.1; also elsewhere on the board
/Tune.enBPFLo2: J103.3, R102.1; also elsewhere on the board
/Tune.enBPFMid: J103.7, R104.1; also elsewhere on the board
/Tune.enBPFMid1: J103.9, R105.1; also elsewhere on the board
/Tune.enBPFMid2: J103.11, R106.1; also elsewhere on the board
/Tune.enHPF: J103.19, R110.1; also elsewhere on the board
/Tune.nenBPFHi: J103.13, R107.1; also elsewhere on the board
/Tune.nenBPFMid: J103.5, R103.1; also elsewhere on the board
/Tune.nenHPF: J103.17, R109.1; also elsewhere on the board
GND: J101.1 (In), J101.2 (Ext), J101.3 (Ext), J101.4 (Ext), J102.1 (In), J102.2 (Ext), J102.3 (Ext), J102.4 (Ext), R101.2, R102.2, R103.2, R104.2, R105.2, R106.2, R107.2, R108.2, R109.2, R110.2, TP101.1, TP102.1, TP103.1, TP104.1, TP105.1, TP106.1, TP107.1, TP108.1, TP109.1, TP110.1, TP111.1, TP112.1; also elsewhere on the board
unnamed: C101.2, J101.5 (Ext)
unnamed: C102.1, J102.5 (Ext)

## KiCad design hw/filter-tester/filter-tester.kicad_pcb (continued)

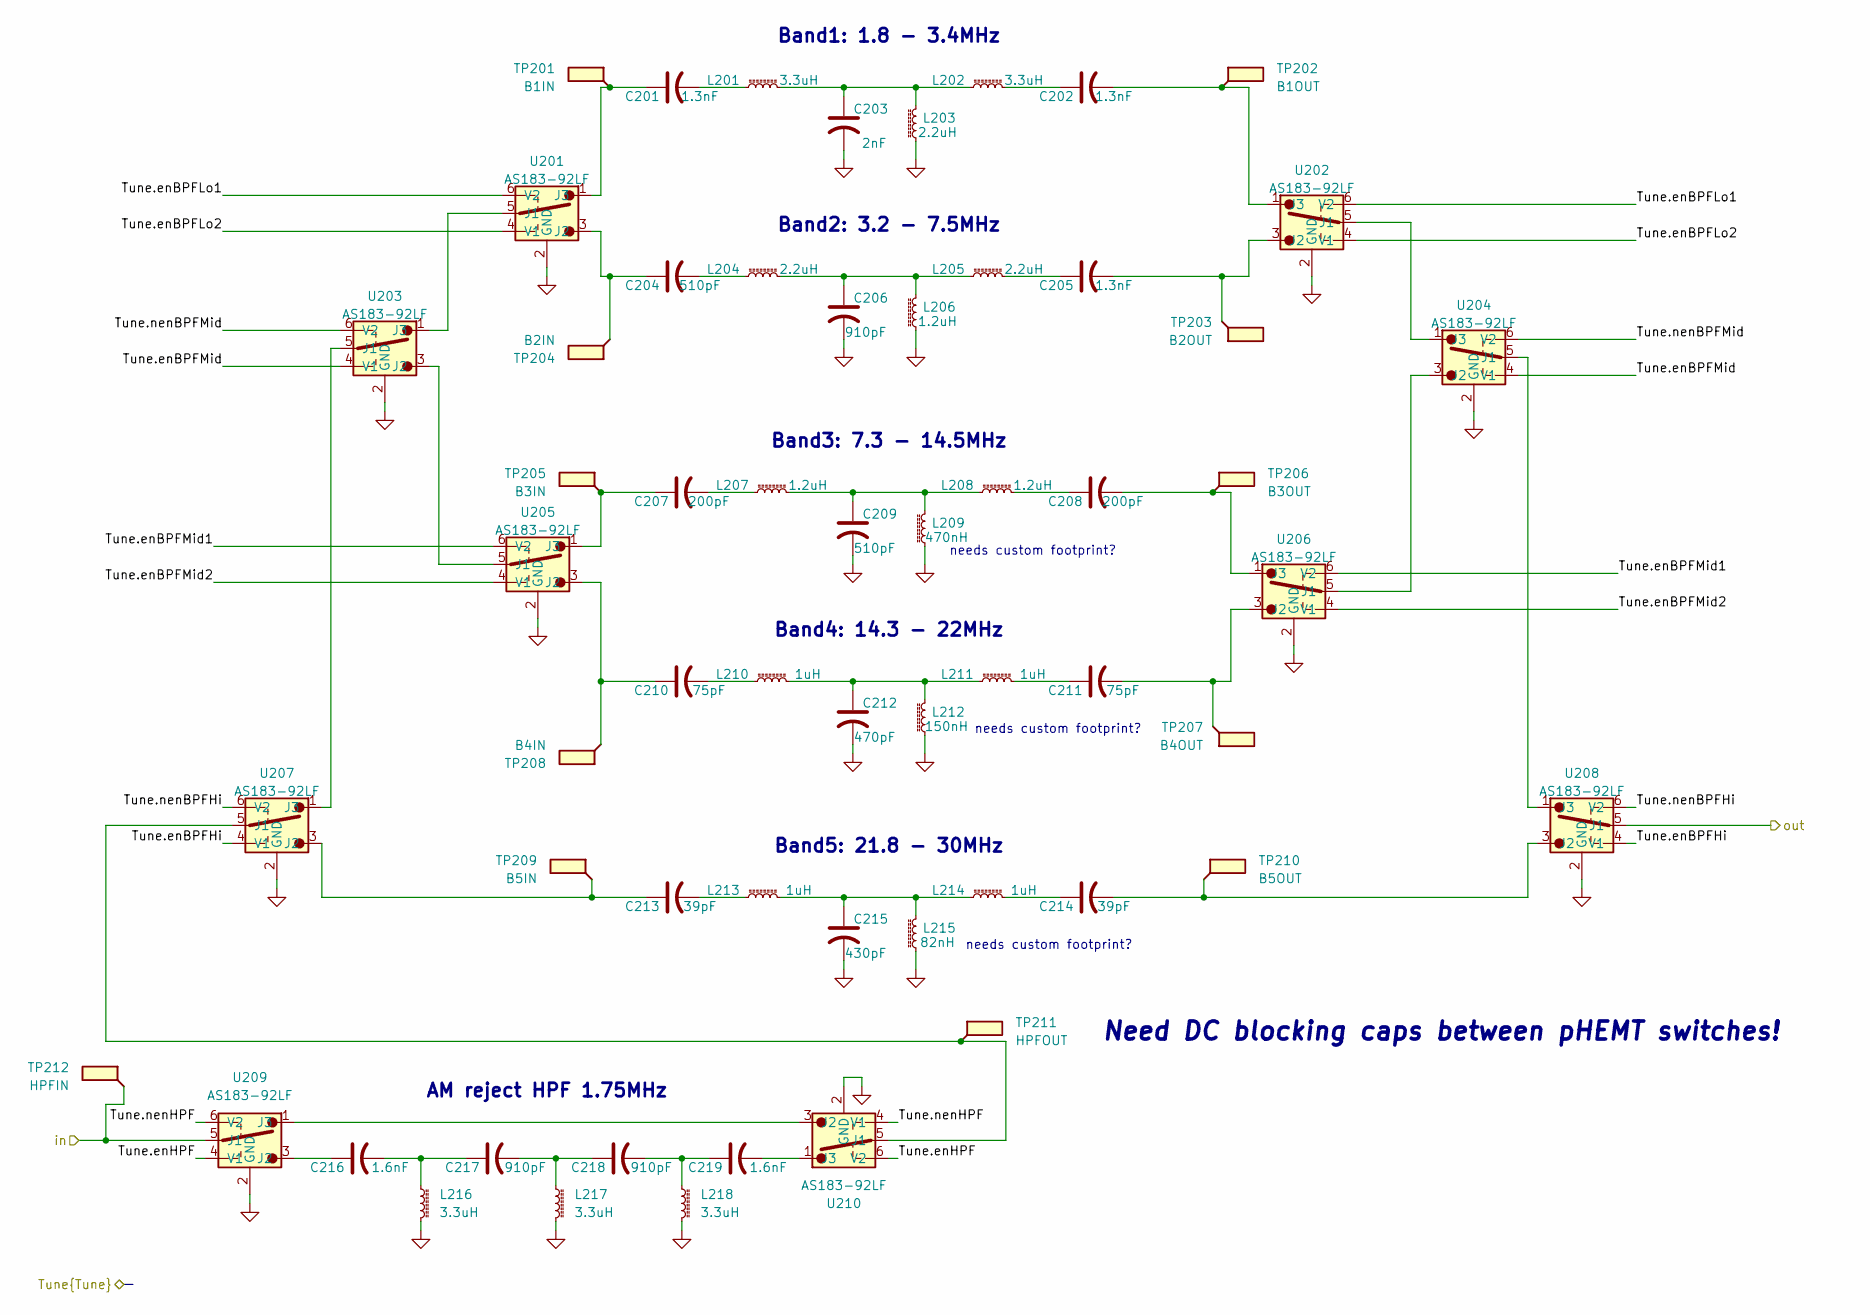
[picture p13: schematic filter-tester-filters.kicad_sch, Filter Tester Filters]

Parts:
C201, C202, C205: 1.3nF; C_0402_1005Metric; MPN C0402C132J5GACTU; Mouser_PN 80-C0402C132J5GACTU
C203: 2nF; C_0402_1005Metric; MPN C0402C202J3GACTU; Mouser_PN 80-C0402C202J3G
C204, C209: 510pF; C_0402_1005Metric; MPN GRT1555C1H511FA02D; Mouser_PN 81-GRT1555C1H511FA2D
C206: 910pF; C_0402_1005Metric; MPN GRT1555C1H911FA02D; Mouser_PN 81-GRT1555C1H911FA2D
C207, C208: 200pF; C_0402_1005Metric; MPN GCM1555C1H201FA16D; Mouser_PN 81-GCM1555C1H201FA6D
C210, C211: 75pF; C_0402_1005Metric; MPN GCM1555C1H750FA16J; Mouser_PN 81-GCM1555C1H750FA6J
C212: 470pF; C_0402_1005Metric; MPN GRM1555C2A471GE01D; Mouser_PN 81-GRM1555C2A471GE1D
C213, C214: 39pF; C_0402_1005Metric; MPN GRM1555C2A390JA01D; Mouser_PN 81-GRM1555C2A390JA1D
C215: 430pF; C_0402_1005Metric; MPN GRT1555C1H431FA02D; Mouser_PN 81-GRT1555C1H431FA2D
C216, C219: 1.6nF; C_0805_2012Metric; MPN GRM2165C1H162JA01D; Mouser_PN 81-GRM2165C1H162JA1D
C217, C218: 910pF; C_0805_2012Metric; MPN 08051A911JAT2A; Mouser_PN 581-08051A911JAT2A
L201, L202, L216, L217, L218: 3.3uH; L_1812_4532Metric-keepout; MPN 1812CS-332XJR; Mouser_PN 994-1812CS-332XJRC
L203, L204, L205: 2.2uH; L_1812_4532Metric-keepout; MPN 1812CS-222XJR; Mouser_PN 994-1812CS-222XJRC
L206, L207, L208: 1.2uH; L_1812_4532Metric-keepout; MPN 1812CS-122XJR; Mouser_PN 994-1812CS-122XJRC
L209: 470nH; L_1206_3216Metric-keepout; MPN AISC-1206-R47G-T; Mouser_PN 994-1206CS-471XJRC
L210, L211, L213, L214: 1uH; L_1812_4532Metric-keepout; MPN 1812CS-102XJR; Mouser_PN 994-1812CS-102XJRC
L212: 150nH; L_1206_3216Metric-keepout; MPN AISC-1206-R15G-T; Mouser_PN 994-1206CS-151XJRC
L215: 82nH; L_1206_3216Metric-keepout; MPN AISC-1206-82NK-T; Mouser_PN 994-1206CS-820XJRC
TP201: B1IN; TestPoint_Pad_1.0x1.0mm
TP202: B1OUT; TestPoint_Pad_1.0x1.0mm
TP203: B2OUT; TestPoint_Pad_1.0x1.0mm
TP204: B2IN; TestPoint_Pad_1.0x1.0mm
TP205: B3IN; TestPoint_Pad_1.0x1.0mm
TP206: B3OUT; TestPoint_Pad_1.0x1.0mm
TP207: B4OUT; TestPoint_Pad_1.0x1.0mm
TP208: B4IN; TestPoint_Pad_1.0x1.0mm
TP209: B5IN; TestPoint_Pad_1.0x1.0mm
TP210: B5OUT; TestPoint_Pad_1.0x1.0mm
TP211: HPFOUT; TestPoint_Pad_1.0x1.0mm
TP212: HPFIN; TestPoint_Pad_1.0x1.0mm
U201, U202, U203, U204, U205, U206, U207, U208, U209, U210: AS183-92LF; SOT65P220X110-6N; MPN AS183-92LF; LCSC_PN C2654768

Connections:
/Filters/in: TP212.1, U209.5 (J1); also elsewhere on the board
/Filters/out: U208.5 (J1); also elsewhere on the board
/Tune.enBPFHi: U207.4 (V1), U208.4 (V1); also elsewhere on the board
/Tune.enBPFLo1: U201.6 (V2), U202.6 (V2); also elsewhere on the board
/Tune.enBPFLo2: U201.4 (V1), U202.4 (V1); also elsewhere on the board
/Tune.enBPFMid: U203.4 (V1), U204.4 (V1); also elsewhere on the board
/Tune.enBPFMid1: U205.6 (V2), U206.6 (V2); also elsewhere on the board
/Tune.enBPFMid2: U205.4 (V1), U206.4 (V1); also elsewhere on the board
/Tune.enHPF: U209.4 (V1), U210.6 (V2); also elsewhere on the board
/Tune.nenBPFHi: U207.6 (V2), U208.6 (V2); also elsewhere on the board
/Tune.nenBPFMid: U203.6 (V2), U204.6 (V2); also elsewhere on the board
/Tune.nenHPF: U209.6 (V2), U210.4 (V1); also elsewhere on the board
GND: C203.2, C206.2, C209.2, C212.2, C215.2, L203.1, L206.1, L209.1, L212.1, L215.1, L216.2, L217.2, L218.2, U201.2 (GND), U202.2 (GND), U203.2 (GND), U204.2 (GND), U205.2 (GND), U206.2 (GND), U207.2 (GND), U208.2 (GND), U209.2 (GND), U210.2 (GND); also elsewhere on the board
unnamed: C201.2, L201.1
unnamed: C202.1, L202.2
unnamed: C203.1, L201.2, L202.1, L203.2
unnamed: C204.2, L204.1
unnamed: C205.1, L205.2
unnamed: C206.1, L204.2, L205.1, L206.2
unnamed: C207.2, L207.1
unnamed: C208.1, L208.2
unnamed: C209.1, L207.2, L208.1, L209.2
unnamed: C210.2, L210.1
unnamed: C211.1, L211.2
unnamed: C212.1, L210.2, L211.1, L212.2
unnamed: C213.2, L213.1
unnamed: C214.1, L214.2
unnamed: C215.1, L213.2, L214.1, L215.2
unnamed: C216.2, C217.1, L216.1
unnamed: C217.2, C218.1, L217.1
unnamed: C218.2, C219.1, L218.1
unnamed: U201.5 (J1), U203.1 (J3)
unnamed: C204.1, TP204.1, U201.3 (J2)
unnamed: C201.1, TP201.1, U201.1 (J3)
unnamed: U202.5 (J1), U204.1 (J3)
unnamed: C205.2, TP203.1, U202.3 (J2)
unnamed: C202.2, TP202.1, U202.1 (J3)
unnamed: U203.5 (J1), U207.1 (J3)
unnamed: U203.3 (J2), U205.5 (J1)
unnamed: U204.5 (J1), U208.1 (J3)
unnamed: U204.3 (J2), U206.5 (J1)
unnamed: C210.1, TP208.1, U205.3 (J2)
unnamed: C207.1, TP205.1, U205.1 (J3)
unnamed: C211.2, TP207.1, U206.3 (J2)
unnamed: C208.2, TP206.1, U206.1 (J3)
unnamed: TP211.1, U207.5 (J1), U210.5 (J1)
unnamed: C213.1, TP209.1, U207.3 (J2)
unnamed: C214.2, TP210.1, U208.3 (J2)
unnamed: C216.1, U209.3 (J2)
unnamed: U209.1 (J3), U210.3 (J2)
unnamed: C219.2, U210.1 (J3)

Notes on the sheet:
needs custom footprint?
AM reject HPF 1.75MHz
Band4: 14.3 - 22MHz
Need DC blocking caps between pHEMT switches!
Band3: 7.3 - 14.5MHz
Band2: 3.2 - 7.5MHz
Band5: 21.8 - 30MHz
Band1: 1.8 - 3.4MHz

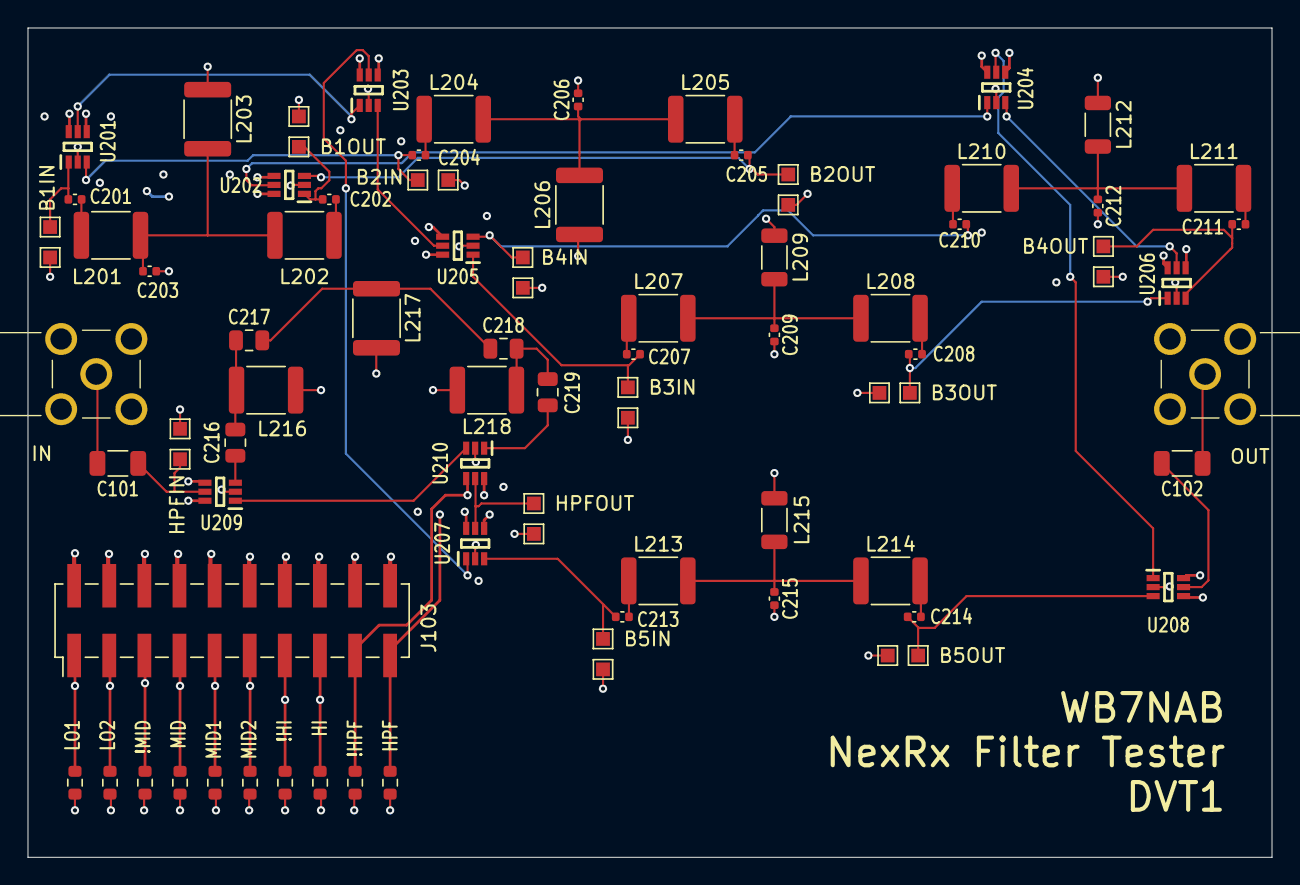
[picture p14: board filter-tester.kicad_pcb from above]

Board: 6 copper layers, 90.0 x 60.0 mm, 86 parts (0 on the bottom side), 54 nets.

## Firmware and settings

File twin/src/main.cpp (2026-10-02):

/**
 * @file main.cpp
 * @brief Entry point for NexRx Digital Twin
 *
 * @copyright 2026 NexRx Project - MIT License
 */

#include "orchestrator/Orchestrator.hpp"

#include <iostream>
#include <string>
#include <vector>
#include <getopt.h>
#include <csignal>

using namespace nexrx;

static Orchestrator* gOrchestrator = nullptr;

void signalHandler(int signum) {
  std::cout << "\nInterrupt signal (" << signum << ") received.\n";
  if (gOrchestrator) {
    gOrchestrator->stop();
  }
}

void printUsage(const char* progName) {
  std::cout << "Usage: " << progName << " [options] netlist_file\n"
            << "Options:\n"
            << "  -h, --help           Show this help\n"
            << "  -v, --verbose        Enable verbose output\n"
            << "  -r, --realtime       Run in real-time mode (sync with wall clock)\n"
            << "  -t, --timestep NS    Set simulation time step in ns (default: 10)\n"
            << "  -s, --samplerate HZ  Set ADC sample rate in Hz (default: 384000)\n"
            << "  -d, --duration S     Set simulation duration in seconds\n";
}

int main(int argc, char* argv[]) {
  std::signal(SIGINT, signalHandler);

  OrchestratorConfig config;
  double duration = 0.0;
  std::string netlistPath;

  static struct option longOptions[] = {
    {"help",       no_argument,       nullptr, 'h'},
    {"verbose",    no_argument,       nullptr, 'v'},
    {"realtime",   no_argument,       nullptr, 'r'},
    {"timestep",   required_argument, nullptr, 't'},
    {"samplerate", required_argument, nullptr, 's'},
    {"duration",   required_argument, nullptr, 'd'},
    {nullptr,      0,                 nullptr, 0}
  };

  int opt;
  while ((opt = getopt_long(argc, argv, "hvrt:s:d:", longOptions, nullptr)) != -1) {
    switch (opt) {
      case 'h': printUsage(argv[0]); return 0;
      case 'v': config.verbose = true; break;
      case 'r': config.realTimeMode = true; break;
      case 't': config.simulationTimeStepNS = std::stod(optarg); break;
      case 's': config.adcSampleRateHz = std::stod(optarg); break;
      case 'd': duration = std::stod(optarg); break;
      default: printUsage(argv[0]); return 1;
    }
  }

  if (optind >= argc) {
    std::cerr << "Error: No netlist file specified\n";
    printUsage(argv[0]);
    return 1;
  }
  netlistPath = argv[optind];
  config.netlistPath = netlistPath;

  std::cout << "=== NexRx Digital Twin ===" << std::endl;
  std::cout << "Loading netlist: " << netlistPath << std::endl;

  Orchestrator orchestrator;
  gOrchestrator = &orchestrator;

  if (!orchestrator.initialize(config)) {
    std::cerr << "Failed to initialize orchestrator" << std::endl;
    return 1;
  }

  uint64_t lastPrintSample = 0;
  orchestrator.setADCSampleCallback([&](double timeS, const std::vector<double>&) {
    uint64_t sampleIndex = orchestrator.getStats().adcSamplesGenerated;
    if (config.verbose && (sampleIndex - lastPrintSample >= 9600)) {
      std::cout << "  ADC sample " << sampleIndex
                << " at t=" << timeS * 1e3 << " ms" << std::endl;
      lastPrintSample = sampleIndex;
    }
  });

  bool success;
  if (duration > 0) {
    std::cout << "Running for " << duration << " seconds..." << std::endl;
    success = orchestrator.runFor(duration);
  } else {
    std::cout << "Running to completion..." << std::endl;
    success = orchestrator.runToCompletion();
  }

  const auto& stats = orchestrator.getStats();
  std::cout << "\n--- Results ---" << std::endl;
  std::cout << "  Success: " << (success ? "yes" : "no") << std::endl;
  std::cout << "  Total steps: " << stats.totalSteps << std::endl;
  std::cout << "  ADC samples: " << stats.adcSamplesGenerated << std::endl;
  std::cout << "  Simulated time: " << stats.simTimeS * 1e3 << " ms" << std::endl;
  std::cout << "  Wall clock: " << stats.wallTimeS << " s" << std::endl;
  std::cout << "  Speed factor: " << stats.speedFactor << "x real-time" << std::endl;

  gOrchestrator = nullptr;
  return success ? 0 : 1;
}

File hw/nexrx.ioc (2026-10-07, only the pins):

Mcu.UserName=STM32H753VITx
PA1.GPIO_Label=osdMCLK
PA1.Signal=SAI2_MCLK_B
PA11.GPIO_Label=dispNSS
PA11.Signal=SPI2_NSS
PA12.GPIO_Label=osdWCLK
PA12.Signal=SAI2_FS_B
PA2.GPIO_Label=osdBCLK
PA2.Signal=SAI2_SCK_B
PA3.GPIO_Label=usbDATA0
PA3.Signal=USB_OTG_HS_ULPI_D0
PA4.GPIO_Label=cpld0.NSS
PA4.Signal=GPIO_Output
PA5.GPIO_Label=usbCLKOUT
PA5.Signal=USB_OTG_HS_ULPI_CK
PA6.GPIO_Label=audioReset
PA6.Signal=GPIO_Output
PA7.GPIO_Label=cc2ADC
PA7.Signal=ADCx_INP7
PA9.GPIO_Label=dispSCK
PA9.Signal=SPI2_SCK
PB0.GPIO_Label=usbDATA1
PB0.Signal=USB_OTG_HS_ULPI_D1
PB1.GPIO_Label=usbDATA2
PB1.Signal=USB_OTG_HS_ULPI_D2
PB10.GPIO_Label=usbDATA3
PB10.Signal=USB_OTG_HS_ULPI_D3
PB11.GPIO_Label=usbDATA4
PB11.Signal=USB_OTG_HS_ULPI_D4
PB12.GPIO_Label=usbDATA5
PB12.Signal=USB_OTG_HS_ULPI_D5
PB13.GPIO_Label=usbDATA6
PB13.Signal=USB_OTG_HS_ULPI_D6
PB14.Signal=USART1_TX
PB15.Signal=USART1_RX
PB2.GPIO_Label=cpld.MOSI
PB2.Signal=SPI3_MOSI
PB5.GPIO_Label=usbDATA7
PB5.Signal=USB_OTG_HS_ULPI_D7
PB6.GPIO_Label=rfSCL
PB6.Signal=I2C1_SCL
PB7.GPIO_Label=rfSDA
PB7.Signal=I2C1_SDA
PB8.GPIO_Label=nGRN
PB8.Signal=S_TIM16_CH1
PB9.GPIO_Label=nRED
PB9.Signal=S_TIM17_CH1
PC0.GPIO_Label=usbSTP
PC0.Signal=USB_OTG_HS_ULPI_STP
PC1.GPIO_Label=dispMOSI
PC1.Signal=SPI2_MOSI
PC10.GPIO_Label=cpld.SCK
PC10.Signal=SPI3_SCK
PC11.GPIO_Label=cpld.MISO
PC11.Signal=SPI3_MISO
PC2_C.GPIO_Label=usbDIR
PC2_C.Signal=USB_OTG_HS_ULPI_DIR
PC3_C.GPIO_Label=usbNXT
PC3_C.Signal=USB_OTG_HS_ULPI_NXT
PC5.GPIO_Label=cc1ADC
PC5.Signal=ADCx_INP8
PC7.GPIO_Label=dispBL
PC7.Signal=S_TIM3_CH2
PD0.GPIO_Label=enBPFMid
PD0.Signal=GPIO_Output
PD1.GPIO_Label=enBPFMid2
PD1.Signal=GPIO_Output
PD10.Signal=GPIO_Output
PD11.GPIO_Label=atten.3dB
PD11.Signal=SAI2_SD_A
PD2.GPIO_Label=enBPFHi
PD2.Signal=GPIO_Output
PD3.GPIO_Label=enBPFLo1
PD3.Signal=GPIO_Output
PD4.GPIO_Label=enHPF
PD4.Signal=GPIO_Output
PD5.Signal=GPIO_Output
PD6.GPIO_Label=enable3V3
PD6.Signal=GPIO_Output
PD7.GPIO_Label=atten.24dB
PD7.Signal=GPIO_Output
PD8.GPIO_Label=atten.12dB
PD8.Signal=GPIO_Output
PD9.GPIO_Label=atten.6dB
PD9.Signal=GPIO_Output
PE0.GPIO_Label=cpld.DONE
PE0.Signal=GPIO_Input
PE1.GPIO_Label=cpld.CRESET
PE1.Signal=GPIO_Output
PE11.GPIO_Label=osd0.sai.data
PE11.Signal=SAI2_SD_B
PE12.GPIO_Label=dispRESET
PE12.Signal=GPIO_Output
PE13.GPIO_Label=dispDC
PE13.Signal=GPIO_Output
PE14.GPIO_Label=osdMOSI
PE14.Signal=SPI4_MOSI
PE2.GPIO_Label=osdSCK
PE2.Signal=SPI4_SCK
PE3.GPIO_Label=osd0.NSS
PE3.Signal=GPIO_Output
PE4.GPIO_Label=osd1.NSS
PE4.Signal=GPIO_Output
PE5.GPIO_Label=osdMISO
PE5.Signal=SPI4_MISO
PE6.GPIO_Label=nBLU
PE6.Signal=S_TIM15_CH2

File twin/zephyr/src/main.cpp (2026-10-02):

/*
 * SPDX-License-Identifier: MIT
 * NexRx Digital Twin - Zephyr Firmware Main
 *
 * Entry point for the STM32 firmware running on native_sim.
 * Connects to the twin orchestrator for I/Q data and control.
 *
 * Copyright 2026 NexRx Project
 */

#include <zephyr/kernel.h>
#include <zephyr/logging/log.h>
#include <zephyr/shell/shell.h>
#include <inttypes.h>
#include <stdlib.h>

#include "twin_transport.hpp"
#include "virtual_nco.hpp"
#include "virtual_adc.hpp"

LOG_MODULE_REGISTER(nexrx_main, LOG_LEVEL_INF);

namespace {

// Twin transport for communication with orchestrator
nexrx::TwinTransport g_transport;

// Virtual peripherals
nexrx::VirtualNco g_nco;
nexrx::VirtualAdc g_adc;

// Current VFO frequencies (Hz)
uint64_t g_vfo_freq[3] = {14000000, 14000000, 14000000};

// Processing thread
K_THREAD_STACK_DEFINE(process_stack, 4096);
struct k_thread process_thread;

void process_iq_thread(void* p1, void* p2, void* p3) {
    ARG_UNUSED(p1);
    ARG_UNUSED(p2);
    ARG_UNUSED(p3);

    LOG_INF("I/Q processing thread started");

    while (true) {
        // Read I/Q frame from shared memory
        if (g_adc.hasData()) {
            auto frame = g_adc.readFrame();

            // Process I/Q data here
            // In real firmware, this would:
            // 1. Apply digital filtering
            // 2. Combine OSD outputs for image rejection
            // 3. Decimate to audio rate
            // 4. Send to USB audio class

            // For now, just count frames
            static uint64_t frame_count = 0;
            if (++frame_count % 9600 == 0) {  // Every 100ms
                LOG_INF("Processed %" PRIu64 " frames", frame_count);
            }
        } else {
            // No data available, sleep briefly
            k_msleep(1);
        }
    }
}

} // anonymous namespace

// Shell commands for debugging
static int cmd_status(const struct shell* sh, size_t argc, char** argv) {
    ARG_UNUSED(argc);
    ARG_UNUSED(argv);

    shell_print(sh, "NexRx Twin Firmware Status");
    shell_print(sh, "  Transport: %s", g_transport.isConnected() ? "connected" : "disconnected");
    shell_print(sh, "  VFO0: %" PRIu64 " Hz", g_vfo_freq[0]);
    shell_print(sh, "  VFO1: %" PRIu64 " Hz", g_vfo_freq[1]);
    shell_print(sh, "  VFO2: %" PRIu64 " Hz", g_vfo_freq[2]);
    shell_print(sh, "  ADC frames: %" PRIu64 "", g_adc.frameCount());

    return 0;
}

static int cmd_freq(const struct shell* sh, size_t argc, char** argv) {
    if (argc < 3) {
        shell_print(sh, "Usage: freq <vfo 0-2> <freq_hz>");
        return -EINVAL;
    }

    int vfo = atoi(argv[1]);
    uint64_t freq = strtoull(argv[2], nullptr, 10);

    if (vfo < 0 || vfo > 2) {
        shell_print(sh, "Invalid VFO: %d (must be 0-2)", vfo);
        return -EINVAL;
    }

    g_vfo_freq[vfo] = freq;
    g_nco.setFrequency(vfo, freq);

    shell_print(sh, "VFO%d set to %" PRIu64 " Hz", vfo, freq);
    return 0;
}

SHELL_STATIC_SUBCMD_SET_CREATE(nexrx_cmds,
    SHELL_CMD(status, NULL, "Show firmware status", cmd_status),
    SHELL_CMD(freq, NULL, "Set VFO frequency", cmd_freq),
    SHELL_SUBCMD_SET_END
);
SHELL_CMD_REGISTER(nexrx, &nexrx_cmds, "NexRx commands", NULL);

int main(void) {
    LOG_INF("NexRx Digital Twin Firmware starting...");
    LOG_INF("Build: %s %s", __DATE__, __TIME__);

    // Initialize transport to orchestrator
    if (!g_transport.initialize("/nexrx_iq", "/tmp/nexrx_rpc.sock")) {
        LOG_ERR("Failed to initialize transport");
        // Continue anyway - we can still test shell commands
    }

    // Initialize virtual peripherals
    g_nco.initialize(&g_transport);
    g_adc.initialize(&g_transport);

    // Set default frequencies
    for (int i = 0; i < 3; ++i) {
        g_nco.setFrequency(i, g_vfo_freq[i]);
    }

    // Start I/Q processing thread
    k_thread_create(&process_thread, process_stack,
                    K_THREAD_STACK_SIZEOF(process_stack),
                    process_iq_thread, nullptr, nullptr, nullptr,
                    K_PRIO_COOP(7), 0, K_NO_WAIT);
    k_thread_name_set(&process_thread, "iq_process");

    LOG_INF("Firmware initialized, entering shell");

    // Main thread just runs the shell
    // The processing happens in the process_iq_thread
    return 0;
}

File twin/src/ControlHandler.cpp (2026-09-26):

#include "ControlHandler.hpp"
#include "AGCManager.hpp"
#include <chrono>
#include <iostream>
#include <string>
#include <vector>

namespace nexrx {

ControlHandler::ControlHandler(double centerFreqHz, double offsetHz, 
                               AttenuatorModel* atten, 
                               FilterBankModel* filters, 
                               PGAModel* pga,
                               AGCManager* agc)
  : attenuator(atten)
  , filters(filters)
  , pga(pga)
  , agc(agc)
  , streaming(false)
  , running(false)
  , connected(false)
  , reconnected(false) {
  vfoHz.store(centerFreqHz);
  osdOffsetKHz.store(offsetHz / 1000.0);
  osdFreqHz[0].store(centerFreqHz - offsetHz, std::memory_order_relaxed);
  osdFreqHz[1].store(centerFreqHz + offsetHz, std::memory_order_relaxed);
  isgEnabled.store(false);
  isgFreqHz.store(14201000.0);
  agcMode.store(0);
  trMode.store(0);
}

ControlHandler::~ControlHandler() {
  stop();
}

void ControlHandler::start(TCPControlTransport* ctrl, bool verbosity) {
  controlTransport = ctrl;
  verbose = verbosity;
  running = true;
  connected = true;
  workerThread = std::thread(&ControlHandler::run, this);
}

void ControlHandler::stop() {
  running = false;
  if (workerThread.joinable()) {
    workerThread.join();
  }
}

void ControlHandler::run() {
  while (running) {
    auto result = controlTransport->receiveRequest(std::chrono::milliseconds(100));
    if (!result.ok()) {
      if (result.error == TransportError::Closed && connected.load()) {
        if (verbose) {
          std::cout << "[Control] Client connection closed" << std::endl;
        }
        connected.store(false, std::memory_order_release);
        streaming.store(false, std::memory_order_release);
      }
      continue;
    }
    std::vector<uint8_t> response = handleCborCommand(result.value);
    controlTransport->sendResponse(response);
  }
}

std::vector<uint8_t> ControlHandler::handleCborCommand(const std::vector<uint8_t>& request) {
  CborParser parser;
  CborValue it, arrayIt;
  if (cbor_parser_init(request.data(), request.size(), 0, &parser, &it) != CborNoError) {
    return encodeResponse(1, "CBOR Error");
  }

  cbor_value_enter_container(&it, &arrayIt);
  uint64_t cmdID = 0;
  if (cbor_value_get_uint64(&arrayIt, &cmdID) != CborNoError) {
    return encodeResponse(1, "Command ID Error");
  }
  cbor_value_advance(&arrayIt);

  if (verbose && (uint32_t)cmdID != Control::CMD_GET_STATE) {
    char cmdChars[5] = {
      (char)((cmdID >> 24) & 0xFF),
      (char)((cmdID >> 16) & 0xFF),
      (char)((cmdID >> 8) & 0xFF),
      (char)(cmdID & 0xFF),
      0
    };
    std::printf("[Control] Received command: %s", cmdChars);
    
    CborValue argIt = arrayIt;
    while (!cbor_value_at_end(&argIt)) {
      CborType type = cbor_value_get_type(&argIt);
      if (type == CborIntegerType) {
        int64_t val;
        cbor_value_get_int64(&argIt, &val);
        std::printf(" %lld", (long long)val);
      } else if (type == CborDoubleType) {
        double val;
        cbor_value_get_double(&argIt, &val);
        std::printf(" %.6g", val);
      } else if (type == CborBooleanType) {
        bool val;
        cbor_value_get_boolean(&argIt, &val);
        std::printf(" %s", val ? "true" : "false");
      } else if (type == CborTextStringType) {
        size_t len;
        cbor_value_get_string_length(&argIt, &len);
        std::vector<char> buf(len + 1);
        cbor_value_copy_text_string(&argIt, buf.data(), &len, nullptr);
        std::printf(" \"%s\"", buf.data());
      } else {
        std::printf(" <type %d>", type);
      }
      cbor_value_advance(&argIt);
    }
    std::printf("\n");
  }

  switch ((uint32_t)cmdID) {
    case Control::CMD_SET_VFO: {
      double f, k;
      cbor_value_get_double(&arrayIt, &f);
      cbor_value_advance(&arrayIt);
      cbor_value_get_double(&arrayIt, &k);
      
      vfoHz.store(f);
      osdOffsetKHz.store(k);
      
      osdFreqHz[0].store(f - k * 1000.0);
      osdFreqHz[1].store(f + k * 1000.0);
      return encodeResponse(0, "OK");
    } 
    case Control::CMD_SET_ATTEN: {
      uint64_t db;
      cbor_value_get_uint64(&arrayIt, &db);
      if (attenuator) {
        attenuator->setAtten3dB(db & 0x01);
        attenuator->setAtten6dB(db & 0x02);
        attenuator->setAtten12dB(db & 0x04);
        attenuator->setAtten24dB(db & 0x08);
      }
      return encodeResponse(0, "OK");
    }
    case Control::CMD_SET_PGA_GAIN: {
      uint64_t code;
      cbor_value_get_uint64(&arrayIt, &code);
      if (pga) {
        pga->setGainCode((int)code);
      }
      return encodeResponse(0, "OK");
    }
    case Control::CMD_SET_AGC_MODE: {
      uint64_t mode;
      cbor_value_get_uint64(&arrayIt, &mode);
      agcMode.store((int)mode);
      if (agc) {
        agc->setModeInt((int)mode);
      }
      return encodeResponse(0, "OK");
    }
    case Control::CMD_SET_TR_MODE: {
      uint64_t mode;
      cbor_value_get_uint64(&arrayIt, &mode);
      trMode.store((int)mode);
      return encodeResponse(0, "OK");
    }
    case Control::CMD_START_STREAM:
      if (verbose) std::cout << "[Control] STREAMING START requested" << std::endl;
      streaming.store(true);
      return encodeResponse(0, "OK");
    case Control::CMD_STOP_STREAM:
      if (verbose) std::cout << "[Control] STREAMING STOP requested" << std::endl;
      streaming.store(false);
      return encodeResponse(0, "OK");
    case Control::CMD_GET_TIMESTAMP:
      return encodeResponse(0, std::to_string(std::chrono::steady_clock::now().time_since_epoch().count()));
    case Control::CMD_SET_ISG_FREQ: {
      double f;
      cbor_value_get_double(&arrayIt, &f);
      isgFreqHz.store(f);
      return encodeResponse(0, "OK");
    }
    case Control::CMD_SET_ISG_ENABLE: {
      bool en;
      cbor_value_get_boolean(&arrayIt, &en);
      isgEnabled.store(en);
      return encodeResponse(0, "OK");
    }
    case Control::CMD_SET_HPF_BYPASS: {
      bool bypass;
      cbor_value_get_boolean(&arrayIt, &bypass);
      if (filters) {
        filters->setHpfBypass(bypass);
      }
      return encodeResponse(0, "OK");
    }
    case Control::CMD_SET_BPF_SELECT: {
      uint64_t index;
      cbor_value_get_uint64(&arrayIt, &index);
      if (filters) {
        filters->setBpfIndex((int)index);
      }
      return encodeResponse(0, "OK");
    }
    case Control::CMD_GET_STATE: {
      uint8_t buf[1024];
      CborEncoder enc, array, map;
      cbor_encoder_init(&enc, buf, sizeof(buf), 0);
      cbor_encoder_create_array(&enc, &array, 2);
      cbor_encode_int(&array, 0); // Status OK
      cbor_encoder_create_map(&array, &map, 9);

      cbor_encode_text_stringz(&map, "vfo");
      cbor_encode_double(&map, vfoHz.load());

      cbor_encode_text_stringz(&map, "atten");
      cbor_encode_double(&map, attenuator ? attenuator->getTotalAttenDB() : 0.0);

      cbor_encode_text_stringz(&map, "pga");
      cbor_encode_int(&map, pga ? pga->getGainCode() : 0);
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

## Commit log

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2025-08-28 MUCH better Chebyshev response but high end still a bit off (too high)
    [test.kicad_sch]
2025-08-29 Fixed BPF design with proper Chebyshev response and bandwidth control
    - transformer-coupled-three-tank-bpf-minimal-fix.py: Final working version
    - Uses 90% bandwidth compensation to achieve target bandwidth
    - Maintains original 0.65 factor and g-values that produce Chebyshev ripple
    - Generated band1.mod through band7.mod for all 7 amateur bands
    - Band 5 (20m: 13.5-18.5 MHz) verified with proper 0.1dB ripple
    - Ready for multi-band BPF simulation in KiCad
    [test.kicad_sch]
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2025-10-03 Tx LPF and its selection is pretty much done. Fix some OCD. Start to describe the design and construction.
    [BPF.kicad_sch, DAC.kicad_sch, PIN-bias-boost.kicad_sch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]
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2025-11-02 LPF was completely bugs. AI got decimal place wrong :) . Redesigned and better now in various ways anyway.
    [microcontroller.kicad_sch, pa-tanks.kicad_sch, preselector.kicad_sch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]
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2025-11-05 Added two H bridges for quadrature output via GaN FETs to replace single PA MOSFET
    [h-bridge-pa.kicad_sch, tx-signal-chain.kicad_sch]
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2025-11-15 Massive (simple) fixes to connect Ctrl bus across sheets - I had misunderstood how that works.
    [USB-SSB-txcvr.kicad_pcb, USB-SSB-txcvr.kicad_sch, ant-tuner.kicad_sch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]
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2025-12-07 Giant rename to actual NexRig project name which seems to have stuck
    [NexRig.csv, NexRig.kicad_pcb, NexRig.kicad_sch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]
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2025-12-16 Checkpoint. FPGA is mostly done (need a check!). Working on new LPFs. Need inductor footprints and to fix a bunch of broken/missing footprints.
    [NexRig.kicad_pcb, NexRig.kicad_sch, ant-tuner.kicad_sch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]
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2025-12-18 Clean up some footprints no longer used. Build footprints for LPF and antenna tuner inductors.
    [NexRig.kicad_pcb, ant-tuner.kicad_sch, power.kicad_sch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]
2025-12-18 All symbols and footprints seem right now, and schematic again imports into PCB without error
    [NexRig.kicad_pcb, ant-tuner.kicad_sch, eer-buckboost.kicad_sch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]
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2025-12-31 Checkpoint. Now using TQFP100 STM32H753VIT6, no longer using SPI expanders to drive controls for L,C,atten. FPGA does that now.
    [NexRx.kicad_pcb, NexRx.kicad_sch, fpga.kicad_sch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]
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2026-01-03 Digital twin Stage 1-3: Xyce integration and RF netlists
    Stage 1 - Foundation:
    - CMake build system with Xyce/Trilinos linkage
    - XyceWrapper class for SPICE simulation control
    - Orchestrator skeleton for simulation coordination
    Stage 3 - RF Component Netlists:
    - components.lib: Switch, inductor, attenuator, transformer models
    - preselector.cir: 800Ω LC tank with 10-bit binary cap bank
    - transformers.cir: Impedance matching (50→200→800Ω, splitter)
    - qsd.lib/cir: 4-phase and 6-phase QSD models
    - triple_qsd.cir: Triple-QSD array for image rejection
    - stimulus.lib: RF signal generators (tone, two-tone, AM, noise)
    - nexrx_rx.cir: Full receiver chain (has transformer issues, -48dB loss)
    Kn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
    [Orchestrator.cpp, main.cpp]
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2026-01-05 Updates based on sim results and tuning. Fixup docs to explain what is changing.
    [microcontroller.kicad_sch, qsd.kicad_sch, rx-signal-chain.kicad_sch]
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2026-01-06 Add SDL2/OpenGL windowed app with Lua GUI (Phase 2A)
    Create the foundation for custom Lua-based GUI:
    - SDL2 window with OpenGL 3.3 context
    - Embedded LuaJIT with sol2 bindings
    - Input handling (mouse, keyboard) exposed to Lua
    - Basic drawing primitives (rect, rectOutline)
    - Lua main loop (init, update, draw callbacks)
    - SetBox integration for configuration
    - Demo UI with interactive button and slider
    Architecture: C++ host with SDL2/OpenGL, Lua handles all UI logic.
    [main.cpp]
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2026-01-06 Fix OpenGL rendering by using compatibility profile
    OpenGL 3.3 Core profile doesn't support immediate mode (glBegin/glEnd).
    Switch to OpenGL 2.1 Compatibility profile for proper rendering.
    [main.cpp]
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2026-01-06 Add waterfall spectrum display with colormaps (Phase 2G)
    - OpenGL texture streaming with circular buffer for efficient scrolling
    - Multiple colormaps: Viridis, Plasma, Inferno, Magma, GreenPhosphor, BlueHot, Grayscale
    - Spectrum analyzer with filled gradient and line overlay
    - Simulated signal data for testing (noise floor + carrier peaks)
    - Lua bindings for waterfall control (init, addRow, render, setColormap, setRange)
    [main.cpp]
2026-01-06 Add programmable stimulus system with Lua scripting
    Implement runtime-controllable RF signal generation for the digital twin:
    - StimulusManager: Thread-safe manager for named signal sources
    - MorseGenerator: Text-to-CW with ITU timing, configurable WPM
    - SsbGenerator: USB/LSB with multi-tone or TTS voice modulation
    - SweepGenerator: Phase-continuous frequency sweeps for passband testing
    - TtsEngine: espeak-ng integration for voice synthesis (optional)
    - StimulusLua: sol2 bindings for Lua scripting control
    Lua API provides:
    stimulus.addMorse(name, {freq, amplitude, text, wpm, repeat})
    stimulus.addSsb(name, {freq, amplitude, mode, tones/voice})
    stimulus.addSweep(name, {start, end, ampl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
    [StimulusManager.hpp]
2026-01-06 Wire stimulus system to Xyce simulation (Phase 7)
    Integrate StimulusManager with Orchestrator for runtime RF injection:
    - Add setStimulusManager() to Orchestrator for attaching stimulus sources
    - Generate 100 MHz sampled stimulus data in configurable batches
    - Inject via Xyce updateTimeVoltagePairs() API during simulation loop
    - Add updateTimeVoltagePairs() wrapper in XyceWrapper
    New netlist nexrx_stimulus.cir uses V_STIM PWL source for external
    stimulus instead of fixed sine wave, enabling CW/SSB/sweep injection.
    [Orchestrator.cpp]
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2026-01-07 Add demodulation, audio output, and VFO control
    Full SDR integration connecting twin simulation to app:
    - Add Demodulator class (USB/LSB/AM/CW modes, BFO for CW)
    - Wire I/Q frames through demodulator to audio output
    - Add audio ring buffer with 96kHz→48kHz decimation
    - Add 2000x gain with soft clipping for low-level RF signals
    - Implement file-based VFO control (/tmp/nexrx_control)
    - Add frequency entry mode (F key, type digits, Enter)
    - Add scroll wheel tuning (Shift=100kHz, Ctrl=100Hz, plain=1kHz)
    - Add run-forever mode to pipeline_test (duration=0)
    - Fix SDL input handling (scancodes + SDL_TEXTINPUT)
    - Restore ESC to quit when not in frequency entry mode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
    [main.cpp]
2026-01-07 Logarithmic volume, fix rounded rect, rename signalgen
    - Volume slider now logarithmic (-60dB to 0dB scale)
    - Fix GL_TRIANGLE_FAN bowtie artifact in drawRoundedRect by adding
    edge vertices between corners
    - Rename pipeline_test to signalgen (file, CMakeLists, README)
    [main.cpp]
2026-01-07 Fix RF aliasing with baseband I/Q generation
    The functional simulation was sampling 14MHz RF at 96kHz, causing
    severe aliasing (signals appearing at wrong frequencies).
    Fix: Add getBasebandIQ() method to all stimulus generators. This
    computes baseband I/Q analytically given the LO frequency, avoiding
    RF simulation entirely. The mixer math is done symbolically.
    - AntennaStimulus: Add getBasebandIQ(), carrierFrequency(), getEnvelope()
    - MorseGenerator: Implement getBasebandIQ with envelope extraction
    - ToneGenerator: Implement getBasebandIQ for multi-tone signals
    - SsbGenerator: Implement getBasebandIQ with proper USB/LSB phasing
    - NoiseGenerator: Implement getBasebandIQ (independen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
    [NoiseGenerator.hpp, StimulusManager.hpp, ToneGenerator.hpp]
2026-01-07 Add S-meter, audio bandpass filter, fix aliasing bugs
    - S-meter now shows real signal levels from I/Q stream (RMS → dBm → S-units)
    - Add 50Hz-5kHz Butterworth bandpass filter to demodulator for voice bandwidth
    - Fix baseband aliasing: filter out stimuli outside ±48kHz receiver passband
    - Fix audio filter: process all samples (not just decimated) for proper state
    - Fix Lua variable shadowing: rename local 'rx' to avoid conflict with rx table
    - Update default.lua stimulus positions to avoid overlap
    [main.cpp]
2026-01-07 Add Hann window, increase audio gain, enable TTS voice
    - Add Hann window to spectrum DFT to reduce spectral leakage
    - Increase audio gain 10x (2000→20000) for comfortable µV signal levels
    - Enable espeak-ng TTS for SSB voice stimulus
    - Add espeak_ng.h include for GetSampleRate function
    - Enable voice_id stimulus at 14.175 MHz with phonetic callsign
    [main.cpp]
2026-01-07 Add WAV file playback, fix audio clipping, expose espeak params
    - Add WAV file loading for SSB stimulus (audioFile parameter)
    - Fix audio distortion by applying volume before soft-clip
    - Expose espeak-ng voice parameters (voiceName, rate, pitch, etc.)
    - Change 'repeat' to 'loop' to avoid Lua keyword conflict
    - Include test WAV files for SSB voice simulation
    [main.cpp]
2026-01-07 Replace shared memory with TCP/UDP network transport
    - Add TcpControlTransport for reliable RPC commands (SET_LO, GET_STATUS)
    - Add UdpStreamTransport for real-time I/Q streaming with batching
    - signalgen: auto-detect client IP from TCP, send UDP to that address
    - signalgen: add --bind option for listen address
    - App: read twin connection settings from config (twinHost, twinControlPort, etc.)
    - App: add connectTwin()/disconnectTwin() Lua functions
    - Fix timeout=0 bug in UDP read that prevented data flow
    [main.cpp]
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2026-01-09 Fix macOS app bundle resource paths
    On macOS, when running from a .app bundle, the executable is in
    Contents/MacOS/ but config/lua files are in Contents/Resources/.
    Detect this and chdir to Resources so relative paths work.
    [main.cpp]
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2026-01-10 Increase audio buffering for Windows VM compatibility
    - Set miniaudio period to 40ms with triple buffering
    - Double audio ring buffer to 16384 samples (~340ms)
    Windows VMs have more jittery audio timing than native Linux.
    [main.cpp]
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2026-01-11 Add --no-vsync option and thread priority boosting for VM audio
    VSync blocking can cause audio glitches in VMs where graphics is slow.
    This adds:
    - --no-vsync / -n flag to disable VSync with 60 FPS frame cap
    - Thread priority boosting (THREAD_PRIORITY_HIGHEST on Windows,
    SCHED_FIFO on POSIX) for UDP receive and IQ processing threads
    [main.cpp]
2026-01-11 Add rate-adaptive audio buffer with drop statistics
    Implement async-friendly streaming architecture:
    - Add RateAdaptiveBuffer<T> template with drop/stretch adaptation
    - Refactor audio to use rate-adaptive buffer instead of simple ring
    - Add drop rate tracking (drops/second) for IQ and audio streams
    - Expose stats to Lua: rx.getAudioDropRate(), twin.getIqDropRate()
    - Display buffer fill % and drop rates in UI (red when non-zero)
    - Add GET_STREAM_CONFIG command for rate negotiation
    Buffer automatically drops samples when >75% full and stretches via
    linear interpolation when <25% full, maintaining smooth audio even
    with network jitter or slow consumers.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
    [main.cpp]
2026-01-11 Fix VFO tuning: proper RF/QSD architecture and TCP connection handling
    Architecture fix:
    - Stimulus generators now produce RF I/Q at carrier frequency (getRfIQ)
    - Removed LO knowledge from stimulus - antenna signals are LO-independent
    - QSD mixing (RF × exp(-jωLO) → baseband) now happens in signalgen
    - This matches real hardware: antenna→QSD→baseband→DSP
    TCP connection fix:
    - Server no longer closes connection on recv timeout (EAGAIN/EWOULDBLOCK)
    - Only closes on actual client disconnect (recv returns 0)
    - Fixes broken pipe errors on subsequent SET_LO commands
    Build system:
    - All platforms now use TCP/UDP to connect to twin
    - Removed NEXRX_LOCAL_TWIN conditional (shared memory pa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
    [NoiseGenerator.hpp, StimulusManager.hpp, ToneGenerator.hpp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]
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2026-01-13 Fix SSB sideband inversion and improve twin performance
    Major fixes:
    - Fix Hilbert transform sign error in SsbGenerator: was using correlation
    (i + offset) instead of convolution (i - offset), causing USB to produce
    LSB and vice versa. USB signals now demodulate correctly in USB mode.
    - Add proper audio resampling with anti-alias filter: audio files are now
    resampled to 48kHz at load time using windowed-sinc interpolation with
    Kaiser window. This eliminates the 5kHz aliasing spike that appeared when
    upsampling 8kHz files via linear interpolation.
    - Disable rate adaptation in audio buffer to prevent aliasing: readWithSkip()
    was dropping samples without filtering, causing aliasin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
    [StimulusManager.hpp, main.cpp]
2026-01-13 Fix audio loop transients and add signal stability improvements
    - SsbGenerator: Add loop crossfade that blends end samples toward
    sample[0] for seamless wrap-around (eliminates broadband spikes
    at audio loop boundaries)
    - signalgen: Add periodic LO phase renormalization to prevent
    floating-point drift over long runs
    - app: Skip 8 samples ahead of write position in FFT buffer to
    avoid race condition between producer and consumer threads
    [main.cpp]
2026-01-13 Fix attenuation artifacts with TPDF dithering and add config system
    - Add TPDF (Triangular PDF) dithering before 24-bit quantization in twin
    to preserve low-level signals that would otherwise quantize to zero
    - Add FTZ/DAZ denormal float handling in both twin and app
    - Rename signalgen references to twin in documentation
    - Add Lua-driven configuration code generation system (RxConfig)
    - Integrate config API with app (volume, mute, attenuation, etc.)
    [main.cpp]
2026-01-13 Add SetBox-RxConfig integration for tag-based configuration
    - Add setbox.onPropertyChange() to wire SetBox property changes to RxConfig
    - Add setbox.rule() to define rules from app Lua
    - Add setbox.loadFile(), hasTag(), toggleTag(), resolve()
    - Add config/modes.lua example with band/mode/activity rules
    SetBox resolves configuration based on active tags (e.g., {cw, 80m, contest}),
    then callbacks apply the values to RxConfig which syncs to the twin.
    [main.cpp]
2026-01-13 Add spectrum averaging and re-enable triple-QSD LMS processing
    - Add exponential moving average (EMA) to FFT spectrum computation
    to reduce noise floor speckle from single-frame variance
    - Re-enable LMS adaptive image rejection using all three QSDs
    (was bypassed during attenuation artifact debugging)
    - Add note about TPDF dither amplitude (-138 dBFS)
    [main.cpp]
2026-01-17 Add FIR baseband filter with crossfade transitions and UI controls
    - Add BasebandFilter class with complex FIR bandpass and notch filters
    - Windowed-sinc design with Kaiser window for adjustable steepness
    - 10ms crossfade prevents audio glitches when parameters change
    - Bandpass: adjustable center (-20kHz to +20kHz), width (50-6000Hz), taps
    - Notch: adjustable center and width for removing interfering carriers
    - Wire SetBox properties to RxConfig for tag-based mode presets
    - Add UI controls in Baseband section (show/hide based on enable state)
    - Add waterfall Floor/Peak gain sliders in Display section
    - Add LMS mu slider for tuning adaptive image rejection
    - Remove unused Filter Width/Shift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
    [main.cpp]
2026-01-18 Move colormap definitions from C++ to Lua
    This completes Phase 5 of the architecture refactoring plan.
    - Create app/config/colormaps.lua with colormap gradient definitions
    - viridis, plasma, inferno, magma, green, blue, grayscale
    - Added new colormaps: turbo, hot, cool, amber
    - Users can add custom colormaps by editing this file
    - Add WaterfallRenderer::setColormapData() C++ primitive
    - Accepts gradient stops as {position, r, g, b} tuples
    - Builds 256-entry LUT from gradient stops
    - Add waterfall.setColormapData() Lua binding
    - Converts Lua table to C++ gradient format
    - Called from Lua to apply colormap data
    - Update main.lua with applyColormap() helper
    - Checks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
    [main.cpp]
2026-01-18 Move property change handlers from C++ to Lua dispatch
    Replace C++ if-else-if chains with Lua table-based property
    dispatch. C++ now just extracts the value and calls the Lua
    onPropertyChange function, which uses table lookup to find
    the appropriate handler.
    - Create lua/property_handlers.lua with handler table
    - Dispatch property changes to Lua instead of handling inline
    - Handlers call C++ primitives via existing bindings
    - Supports custom handler registration via PropertyHandlers.register()
    [main.cpp]
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2026-01-20 Refactor to fully event-driven widget architecture
    - Widgets (button, toggle, checkbox) no longer return click state
    - Each widget registers itself with events module for SetBox dispatch
    - Add 36 specific event handlers for all UI interactions
    - Add mode tag system for FreqEntryMode-based event routing
    - Add keycodes.lua with SDL scan code constants
    - Mouse wheel tuning works on VFO display, spectrum, and waterfall
    - Ctrl+Q to quit, ESC only cancels frequency entry mode
    [main.cpp]
2026-01-20 Fix twin session management and client reconnection
    - Add DISCONNECT command to gracefully notify twin when app exits
    - Fix TCP close detection (recv returns 0) by setting errno=ECONNRESET
    - Twin now properly waits for new client after disconnect
    - App explicitly calls startStream() after connecting (no auto-resume)
    - Twin pauses signal generation when no client connected (saves CPU)
    - Update UDP destination when new client reconnects
    [main.cpp]
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2026-01-23 Add container-based layout system with constraint solver
    Replace dock-based layout with container.solve() that computes all widget
    regions at once using anchors. Widgets declare their anchor edge (top,
    bottom, left, right) and the solver processes them in order, claiming
    space from edges before filling the center.
    Key changes:
    - lua/ui/container.lua: New container solver with anchor-based positioning
    - lua/ui/constraints.lua: Constraint expression evaluator for dynamic sizes
    - lua/layout_overrides.lua: Runtime layout modifications persisted to config
    - config/constraints.lua: SetBox rules for widget sizing constraints
    - lua/edit.lua: Fix resize to use totalDx for linear (not exponential) be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
    [main.cpp]
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2026-02-18 Fix up docs to make this NexRx (receiver project) specific and eliminate all but elliptical references to NexRig (the transceiver)
    [top.sv]
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2026-02-20 Added RC filter for "static" signals to avoid coupling noise from 3.3V logic into signal path.
    [NexRx.kicad_pcb, fpga.kicad_sch, gpio-expander.kicad_sch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]
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2026-02-25 Refactor: Pursue generalization of NexRx architecture
    Implemented core architectural improvements focused on generalization and
    reactive design:
    - SetBox: Refactored as a singleton with fixed rule matching and scoring.
    - AppState: Implemented a centralized reactive state system using
    observables and computeds, including declarative animation support.
    - Layout: Implemented a generalized iterative spring layout solver in
    container.solve and solveSublayout, respecting min/max constraints.
    - UI: Created generalized frequencyDisplay and smeter widgets; refactored
    main.lua to use these and delegated layout to the new solver.
    - Events: Improved input synchronization and event bubbling throug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
    [main.cpp]
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2026-02-26 Implement hardware calibration, FPGA BIST, and multi-threaded SDR control plane. Fixed UI bugs and optimized twin pacing.
    [main.cpp]
2026-02-26 Fix volume jumps and signal stability. Implement stable phase-accumulator oscillators in Twin, correct DSP signal path to Center QSD, and rename BIST to Internal Signal Generator with safety interloc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
    [main.cpp]
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2026-02-26 Implement high-selectivity S-meter tracking audible passband
    * Move metering logic into Demodulator to ensure mode-aware selectivity.
    * Implement FFT bin power summation for SSB modes to ignore out-of-band signals.
    * Fix S-meter update timing to be sample-count based (10ms updates).
    * Add Hann window power correction (1.633x) for accurate SSB readings.
    * Ensure AM carrier is preserved in metering by measuring before audio HPF.
    * Maintain stable primary audio path using center QSD (i2).
    [main.cpp]
2026-02-26 Fix AM selectivity, eliminate aliased images, and support 32-bit float WAVs
    * Implement per-channel Simulation Roofing Filters (+/- 200kHz) in Digital Twin to eliminate aliased images of far-off stimuli.
    * Implement dedicated complex 4th-order AM selectivity filter (3kHz cutoff) in Demodulator.
    * Restore wideband (unfiltered) waterfall/spectrum while keeping audio path selective.
    * Upgrade WAV loader to robustly handle 32-bit float, 24-bit integer, and multi-chunk files from Audacity.
    * Auto-enable 6kHz bandpass filter when switching to AM mode.
    * Clean up redundant and non-compiling code in app DSP path.
    [StimulusManager.hpp, main.cpp]
2026-02-27 Add some tools to do various selecting things so I can build the keepout rules for rf200 impedance zone. Fix up a bunch of annoyingly untidy items. Route grounds with traces WITHIN the 200 ohm zone t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
    [NexRx.kicad_pcb]
2026-02-27 Rename BIST to ISG and fix Internal Signal Generator Lua error
    * Standardize terminology by renaming BIST (Built-In Self Test) to ISG (Internal Signal Generator) in UI, documentation, and TODOs.
    * Fix 'nil value' error in app_state.lua by updating hardware control setters to use the new setIsgEnable and setIsgFreq method names.
    * Update digital-twin.md documentation for the new SET_PRESEL_L <index> signature.
    [nexrx_full_bom.csv, nexrx_kicad_bom.csv, nexrx_lcsc_bom.csv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]
2026-02-28 Expand control protocol and scaffold Test & Calibration Suite
    * Normal Protocol: Add SPGA (PGA control) and expand SCOD (Codec config with TDM mapping/filter type).
    * Digital Twin: Implement PgaModel and update simulation to apply independent gain per channel.
    * App: Add setPgaGain and sync setCodecConfig with the new protocol signature.
    * Test Suite: Scaffold test-app directory with CMake and stubs for presel-cal, iq-bal, spur-chk, pga-chk, and stream-chk.
    * Consistency: Fix 'bist' to 'isg' renaming in app_state.lua and documentation.
    [main.cpp]
2026-02-28 Consolidate BOM management and back-propagate properties to schematics
    * Implement unified BOM processor (tools/bom-processor.py) using kicad-cli for macro expansion and field collapsing.
    * Back-propagate unified component properties (Manufacturer, MPN, LCSC_PN, Mouser_PN, Description) to all KiCad schematic files.
    * Generate initial production BOM (production/nexrx-bom.csv) with 100% LCSC part number coverage.
    * Standardize passive component descriptions with full technical specifications (dielectric, voltage, tolerance).
    * Clean up redundant manufacturer and part number fields in schematic symbols.
    * Remove obsolete BOM management scripts.
    [NexRx.kicad_sch, PGA.kicad_sch, fpga.kicad_sch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]
2026-02-28 Restore component Value positions in schematics
    The previous back-propagation script reset component property coordinates to (0, 0, 0), causing them to disappear or cluster at the page origin. This update:
    * Reads the previous schematic versions from git (HEAD~1).
    * Extracts original (at X Y R) coordinates and (effects) formatting for each symbol.
    * Preserves original placements while updating Value and metadata properties.
    * Ensures metadata fields (LCSC_PN, etc.) remain hidden.
    [NexRx.kicad_sch, PGA.kicad_sch, fpga.kicad_sch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]
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
